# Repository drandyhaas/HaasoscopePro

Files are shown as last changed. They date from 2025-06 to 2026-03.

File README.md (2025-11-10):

## Haasoscope Pro

An affordable 2 GHz 3.2 GS/s 12 bit open-source open-hardware expandable USB oscilloscope

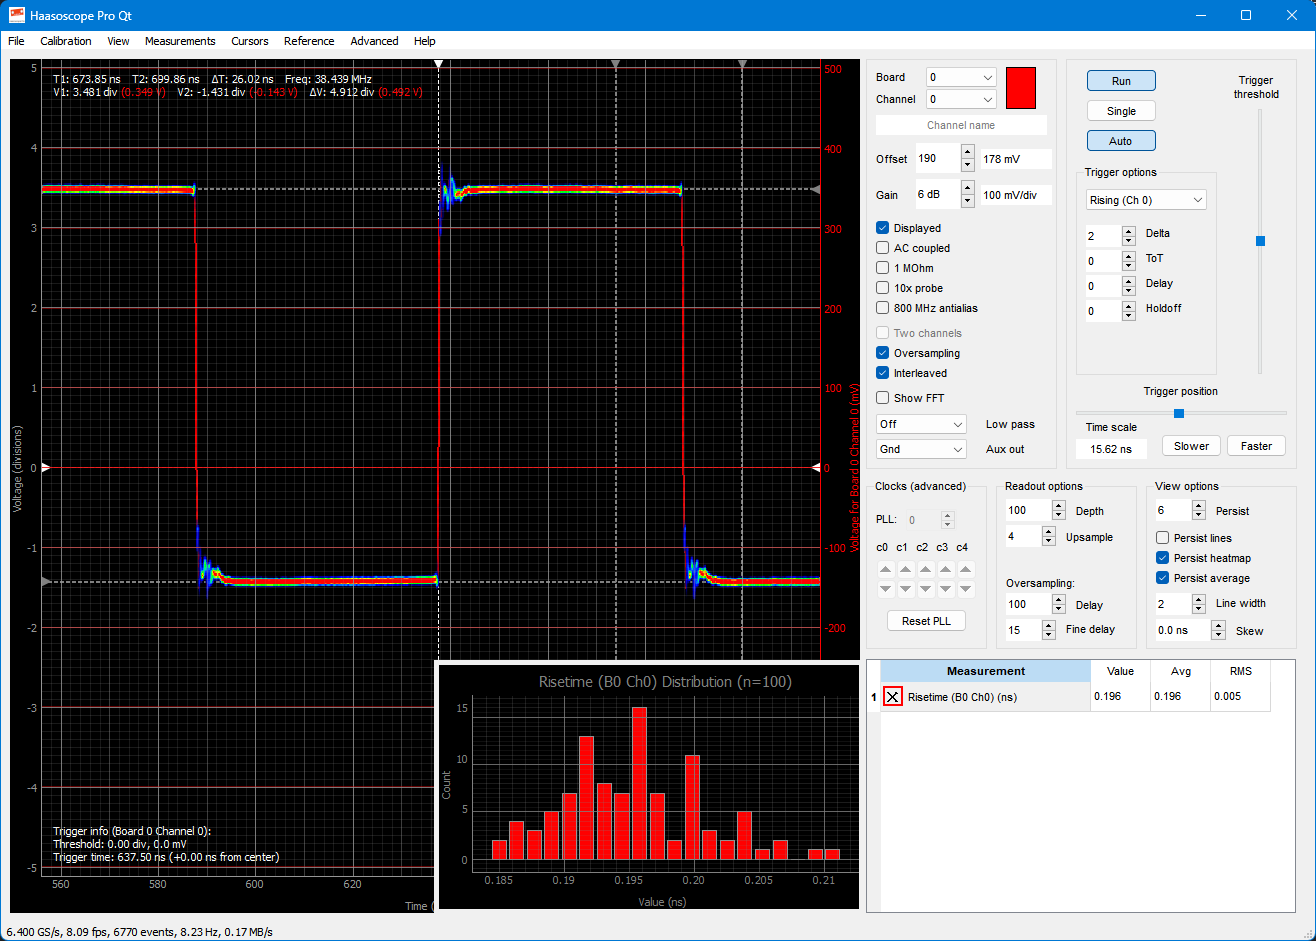
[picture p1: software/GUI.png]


## Links

Available on [CrowdSupply](https://www.crowdsupply.com/andy-haas/haasoscope-pro) and at [Mouser](https://www.mouser.com/c/?q=Haasoscope)

[Hackaday.io page](https://hackaday.io/project/200773-haasoscope-pro)

[Schematics PDF](adc%20board/haasoscope_pro_adc_fpga_board_schematics.pdf)

[Routing image](adc%20board/haasoscope_pro_adc_fpga_board_routing.png)

[Firmware overview](adc%20board%20firmware/schematic.pdf)

[Software overview](software/diagram.png)

## Video tutorials

See this [YouTube Playlist](https://www.youtube.com/playlist?list=PLB1iz3MRh5DiKQQmUUNoTf2oo_m5qS00k) !

## Software and firmware versions

- "main" branch currently has v32 firmware and software
- "v32_test" branch: new development is happening here
- old: "v29" branch has v29 firmware and adds more software features
- old: "v27" branch has v27 firmware that shipped with the first round of units

To use a different branch, do <code>git pull && git checkout "branchname"</code>.
For v30+ you can [download a release](https://github.com/drandyhaas/HaasoscopePro/releases) zip file for your platform (Windows, Mac, Linux).
Then run the new software, update the firmware (if needed) on your board from that new software, and power cycle the board (automatic firmware reload for boards with v29+ firmware).

## Quick start for Windows / Mac (M1+) / Linux (Ubuntu)

1) [Download a release](https://github.com/drandyhaas/HaasoscopePro/releases) zip file for your OS
2) Install [FTDI D2xx driver](https://ftdichip.com/drivers/d2xx-drivers/) for your OS:
- for Windows: run the setup exe at <code>ftdi_setup.exe</code>
- for Mac: <code>sudo mkdir -p /usr/local/lib; sudo cp libftd2xx.dylib /usr/local/lib/</code> 
- for Linux: <code>sudo cp libftd2xx.so /usr/lib/</code>
3) Plug Haasoscope Pro into your computer via USB (5V 2A at least!)
4) Run **HaasoscopeProQt** in the <code>(OS)_HaasoscopeProQt</code> directory

## Fuller way of running

1) Install python3 and git for your operating system
2) Get code: <code>git clone https://github.com/drandyhaas/HaasoscopePro.git</code>
3) <code>cd HaasoscopePro/software</code>
4) Install dependencies: <code>pip install -r requirements.txt</code><br>
   or manually: <code>pip install numpy scipy pyqtgraph PyQt5 pyftdi ftd2xx requests packaging</code><br>
5) Install FTDI driver (see Quick start above)
6) Plug Haasoscope Pro into your computer via USB (5V 2A at least!)
7) Run: <code>python3 HaasoscopeProQt.py</code>

## Tips

- If not enough power is being supplied, plug in via a [powered USB hub](https://a.co/d/hfAtVhl), a [USB PD hub with 15W reserved for ports](https://a.co/d/174I3v8), or use an external [5-24V 20W+ power adapter with 2.1mm plug](https://a.co/d/1EkzLRP)
- If you get security issues on Mac, do: <code>xattr -cr Mac_HaasoscopeProQt</code>
- If the board is not found on Linux, use this udev rule and then plug it in: <code>sudo cp ft245.rules /etc/udev/rules.d/</code>
- If you get an error like "qt.qpa.plugin: Could not load the Qt platform plugin "xcb" in "" even though it was found", try: <code>sudo apt install libxcb-xinerama0</code>

## Support

- Ask a question in the [discussions forum](https://github.com/drandyhaas/HaasoscopePro/discussions)
- Post bugs or requests in the [issues section](https://github.com/drandyhaas/HaasoscopePro/issues)

## Repository structure

- [adc board](adc%20board/): Design files and documentation for the main board, based on Eagle 9.6.2
- [adc board firmware](adc%20board%20firmware/): Quartus lite project and documentation for the Altera Cyclone IV FPGA firmware
- [case](case/): Front and back PCB panels for the aluminum case
- [other](other/): Other files like safety docs, jlc files, and ftdi template
- [software](software/): Python files and documentation for the oscilloscope program
- [sub boards](sub%20boards/): Eagle design files and documentation for smaller test boards that were used during development

## 2 GHz Active Probe

All designs for the accompanying Haasoscope Pro-be active probe are in a [separate repository](https://github.com/drandyhaas/oshw-active-probe)

## Other GUIs

 - [ngscopeclient](https://www.ngscopeclient.org/) is a very powerful multi-instrument analysis suite. HaasoscopeProQt must be running, which then automatically opens the LAN port and accepts connections from ngscopeclient. See the ngscopeclient user manual for details.

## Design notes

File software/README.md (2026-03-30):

# HaasoscopePro Software

Python-based oscilloscope software for the HaasoscopePro hardware.

## Quick Start

### Installation

```bash
# Install dependencies from requirements file
pip install -r requirements.txt

# Or install manually
pip install numpy scipy pyqtgraph PyQt5 ftd2xx requests packaging
```

**Note:** `requests` and `packaging` are optional but recommended for automatic update checking.

### Running with Hardware

```bash
# Run the application
python HaasoscopeProQt.py
```

The software will automatically detect connected HaasoscopePro boards via USB.

### Running with Dummy Server (No Hardware Required)

For development and testing without physical hardware:

```bash
# Terminal 1 - Start dummy server
cd dummy_scope
python dummy_server.py --port 9999

# Terminal 2 - Run application with socket connection
python HaasoscopeProQt.py --socket localhost:9999
```

**Command-Line Options:**

```bash
# Single dummy board on custom port
python HaasoscopeProQt.py --socket localhost:9999

# Multiple dummy boards (multi-board simulation)
python HaasoscopeProQt.py --socket localhost:9998 --socket localhost:9999 --socket localhost:10000

# Remote dummy server
python HaasoscopeProQt.py --socket 192.168.1.100:9999

# Mix hardware and dummy boards (if hardware is detected, socket boards are added)
python HaasoscopeProQt.py --socket localhost:9999

# Limit maximum number of devices to connect (default: 100)
python HaasoscopeProQt.py --max-devices 4

# USB3 mode for HaasoscopePro Max (uses FT60X instead of FT232H, allows 1M memory depth)
python HaasoscopeProQt.py --usb3

# Testing mode (disables dynamic status bar updates for stable screenshots)
python HaasoscopeProQt.py --socket localhost:9999 --testing

# Combine options
python HaasoscopeProQt.py --max-devices 5 --socket localhost:9999 --testing

# Show help
python HaasoscopeProQt.py --help
```

**Automatic Fallback:** If no `--socket` is specified and no hardware is detected, the application automatically tries to connect to `localhost:9998`.

See [dummy_scope/README.md](dummy_scope/README.md) for detailed dummy server documentation.

## Editing the GUI

The Haasoscope Pro GUI can be edited using [Qt Designer](https://www.pythonguis.com/installation/install-qt-designer-standalone/), on software/HaasoscopePro.ui or HaasoscopeProFFT.ui etc.

## Keyboard Shortcuts

The GUI supports keyboard shortcuts for quick control adjustments:

| Shortcut | Function |
|---|---|
| **Arrow Keys** | |
| `Left` / `Right` | Decrease / Increase time scale (downsample) |
| `Up` / `Down` | Increase / Decrease offset |
| **Shift + Arrow Keys** | |
| `Shift+Up` / `Shift+Down` | Increase / Decrease gain |
| **Ctrl + Arrow Keys** | |
| `Ctrl+Up` / `Ctrl+Down` | Increase / Decrease trigger threshold |
| `Ctrl+Left` / `Ctrl+Right` | Decrease / Increase trigger position |
| **Alt + Arrow Keys** | |
| `Alt+Up` / `Alt+Down` | Increase / Decrease trigger delta |
| **Other Keys** | |
| `Space` | Toggle run/pause |
| `R` | Set rising edge trigger on current channel |
| `F` | Set falling edge trigger on current channel |
| `T` | Toggle two-channel mode for current board |
| `C` | Toggle between channel 0 and 1 (two-channel mode) |
| `0` - `9` | Select board 0-9 |
| `` ` `` (backtick) | Select board 0 (alias for `0`) |

**Tips:**
- Arrow keys provide quick navigation without reaching for the mouse
- Modifier keys (Shift/Ctrl/Alt) access additional functions on the same arrow keys
- All shortcuts work when the main window has focus

## Multi-Board Features

The Haasoscope Pro supports daisy-chaining multiple boards via LVDS for synchronized operation.

### Automatic LVDS Delay Calibration

When multiple boards are connected, the system automatically calibrates and compensates for trigger signal propagation delays:

- **Initial Setup**: After PLL reset during startup, LVDS calibration runs automatically for the initial trigger board
- **Switching Trigger Sources**: When you set a different board to channel-based trigger (using `R` or `F` keys, or via UI), calibration runs automatically if no saved calibration exists
- **Saved Calibrations**: Each trigger source board has its own calibration set that is automatically restored when switching back

**To use:**
1. Start the application (PLL reset and LVDS calibration happen automatically)
2. Switch trigger sources as needed using keyboard shortcuts or UI - calibration is fully automatic!

**Manual calibration** is also available via **Calibration → Board LVDS delays** menu.

For detailed technical information, see [EXTTRIG_ECHO_CALIBRATION.md](EXTTRIG_ECHO_CALIBRATION.md).

### Trigger Source Management

- Only one board can be self-triggering at a time (enforced automatically)
- When setting a board to channel-based trigger, all other boards are automatically set to external trigger mode
- Keyboard shortcuts make it easy to switch trigger boards:
  - `0`-`9`: Select board
  - `R`: Set rising edge trigger on current board
  - `F`: Set falling edge trigger on current board

### Board Synchronization

- **Board Stabilizer**: Corrects for trigger jitter on the self-triggering board
- **Extra Trigger Stabilizer**: Fine-grained per-frame stabilization applied across all boards
- **LVDS Compensation**: Firmware (coarse) + software (fine) dual-layer delay compensation for sample-level precision

## Code Architecture

This diagram shows the software architecture with all major components, data flows, and relationships.
Use [mermaid.live](https://mermaid.live/) to convert it to [diagram.png](https://raw.githubusercontent.com/drandyhaas/HaasoscopePro/refs/heads/main/software/diagram.png).

```mermaid
graph TD
    %% --- Styling Definitions ---
    classDef core fill:#d9ead3,stroke:#38761d,stroke-width:2px,font-size:12px;
    classDef startup fill:#cfe2f3,stroke:#3d85c6,stroke-width:2px,font-size:12px;
    classDef hardware fill:#fce5cd,stroke:#e69138,stroke-width:2px,font-size:12px;
    classDef helpers fill:#fff2cc,stroke:#f1c232,stroke-width:2px,font-size:12px;
    classDef datastore fill:#e2d0f3,stroke:#674ea7,stroke-width:2px,font-size:12px;
    classDef user fill:#f4cccc,stroke:#cc0000,stroke-width:2px,font-size:12px;
    classDef device fill:#d0e0e3,stroke:#45818e,stroke-width:2px,font-size:14px;
    classDef testing fill:#c9daf8,stroke:#1c4587,stroke-width:2px,font-size:12px,stroke-dasharray:5;

    %% --- Entry Point ---
    User(["👤 User Input<br>Clicks, Menus, Keys"]) -.-> A
    A["🚀 HaasoscopeProQt.py<br><i>Entry Point</i>"] --> B

    %% --- Main Controller ---
    B["🎛️ MainWindow<br>main_window.py<br><i>Central Controller</i>"]

    %% --- Central State ---
    C[("💾 ScopeState<br>scope_state.py<br>Settings & Config")]

    B <--> C

    %% --- Core Processing Components ---
    B --> D["🔌 HardwareController<br>hardware_controller.py<br>USB/Socket Communication"]
    B --> E["⚙️ DataProcessor<br>data_processor.py<br>Signal Processing"]
    B --> F["📊 PlotManager<br>plot_manager.py<br>Visualization"]

    D <--> C
    E <--> C
    F <--> C

    %% --- Owned Managers ---
    B --> M1["📏 MeasurementsManager<br>measurements_manager.py<br>Statistics & Analysis"]
    B --> M2["📌 ReferenceManager<br>reference_manager.py<br>Waveform Storage"]
    B --> M3["💾 SettingsManager<br>settings_manager.py<br>Save/Load .hsp"]

    M1 --> C
    M2 --> C
    M3 --> C

    %% --- Plot Manager Owned Components ---
    F --> P1["🎯 CursorManager<br>cursor_manager.py<br>H/V Cursors"]
    F --> P2["🔥 HeatmapManager<br>heatmap_manager.py<br>Persistence Heatmap"]

    P1 --> C
    P2 --> C

    %% --- Popup Windows ---
    B -.-> W1["📈 FFTWindow<br>FFTWindow.py<br>Frequency Analysis"]
    B -.-> W2["🧮 MathChannelsWindow<br>math_channels_window.py<br>Channel Math"]
    B -.-> W3["📊 HistogramWindow<br>histogram_window.py<br>Distribution View"]
    B -.-> W4["🕐 HistoryWindow<br>history_window.py<br>Waveform History"]
    B -.-> W5["📉 XYWindow<br>xy_window.py<br>XY Plot Mode"]
    B -.-> W6["🔍 ZoomWindow<br>zoom_window.py<br>Zoomed View"]

    W1 --> C
    W2 --> C
    W5 --> C
    W6 --> C

    %% --- Data Flow ---
    D -- "Raw ADC Data" --> E
    E -- "Processed xydata" --> F
    E -- "Measurements" --> M1
    E -- "FFT Data" --> W1

    %% --- Hardware Layer ---
    D --> H1["🔧 Low-Level Libs<br>usbs.py, board.py<br>USB_FT232H.py"]
    H1 --> H2["🔌 Hardware Interface<br>SPI: spi.py, adf435x_core.py<br>Calibration: calibration.py"]

    H1 --> DEV1["🖥️ Physical Scope<br>via USB/FTDI"]
    H1 --> DEV2["🔬 Dummy Server<br>dummy_scope/<br>TCP Socket"]

    %% --- Additional Services ---
    B -.-> S1["🌐 SCPIsocket.py<br>Remote Control"]
    B -.-> S2["💾 DataRecorder<br>data_recorder.py<br>CSV Export"]

    %% --- Style Applications ---
    class A startup
    class B core
    class C datastore
    class D,E,F core
    class M1,M2,M3,P1,P2 core
    class W1,W2,W3,W4,W5,W6 helpers
    class H1,H2 hardware
    class DEV1 device
    class DEV2 testing
    class S1,S2 helpers
    class User user
```

## Key Modules

### Core Components

**`main_window.py`** - Main application controller
- Handles all UI events (clicks, menus, keyboard shortcuts)
- Orchestrates data flow between hardware, processing, and display
- Manages all component lifecycles
- Implements per-channel/per-board setting synchronization

**`scope_state.py`** - Central state storage
- Single source of truth for all oscilloscope settings
- Per-channel settings: gain, offset, AC/DC, impedance, resamp, peak detect, persistence
- Per-board settings: trigger settings, channel modes, pulse stabilizer
- Global settings: timebase, downsample, display options

**`hardware_controller.py`** - Hardware abstraction layer
- Manages communication with oscilloscope boards
- Sends low-level commands (SPI, trigger, gain/offset)
- Retrieves waveform data packets
- Supports both USB (FTDI) and socket (dummy server) connections

**`data_processor.py`** - Signal processing
- Processes raw ADC data into calibrated waveforms
- Calculates FFT spectra
- Computes measurements (Vpp, RMS, frequency, duty cycle, rise time, trigger-crossing frequency/period)
- Applies calibration corrections

**`plot_manager.py`** - Display and visualization
- Renders waveforms using PyQtGraph
- Applies FIR frequency response correction
- Applies Savitzky-Golay polynomial filtering
- Manages per-channel peak lines, persistence, references
- Handles XY plot mode
- Cursor and measurement overlays
- Real-time plot updates

**`frequency_calibration.py`** - FIR calibration system
- Automatic frequency response correction using square wave calibration
- Support for all modes: normal (3.2 GHz), two-channel (1.6 GHz), oversampling, and interleaved (6.4 GHz)
- Measures duty cycle, frequency, and DC offset from input signal
- Adaptive tap count (32/64/128) based on sample rate
- Save/load calibration files (.fir format)
- See [FIR_CALIBRATION_README.md](FIR_CALIBRATION_README.md) for details

### Supporting Components

**`FFTWindow.py`** - FFT spectrum analyzer window
- Real-time frequency domain display
- Per-channel FFT enable/disable
- Peak detection and analysis

**`math_channels_window.py`** - Math channel operations
- Channel arithmetic (add, subtract, multiply, divide)
- Mathematical functions (differentiate, integrate, smooth, envelope, abs, square, sqrt, log, exp)
- Digital filters (low-pass, high-pass, band-pass, band-stop) with Butterworth and Chebyshev designs
- Time shift with sub-sample interpolation (0.001 Hz to 10 GHz range)
- AC coupling and min/max tracking
- Custom expression evaluation

**Implementation Note**: Math channels are calculated from non-resampled source data (before `doresamp` is applied) to ensure correct FFT frequency ranges and optimal filter performance. Results are then resampled for display to match the source channel's resampling setting. This ensures that:
- FFT analysis shows the true Nyquist frequency of the source data
- Digital filters operate at the actual hardware sample rate
- Min/Max tracking automatically handles array size changes when `doresamp` is modified

**`xy_window.py`** - XY Plot window
- Displays Lissajous figures and parametric plots
- Plots one channel against another (X vs Y)
- Supports both physical and math channels
- Channel selection via dropdown menus
- Useful for I-V curves, phase relationships, and parametric analysis
- Accessed via View menu → XY Plot

**`zoom_window.py`** - Zoom window
- Synchronized zoomed view of the main plot
- Shows all active channels, math channels, and references
- Displays trigger lines, cursors, peak detect, and persistence
- Region of Interest (ROI) selection on main plot
- Secondary Y-axis for voltage display
- Non-interactive view (pan/zoom controlled by ROI on main plot)
- Cross-window mouse pointer (20-pixel crosshair visible only within ROI)
- Accessed via View menu → Zoom Window

**`histogram_window.py`** - Histogram display
- Statistical distribution visualization
- Waveform amplitude analysis
- Histogram binning and counting

**`history_window.py`** - Waveform history viewer
- Stores previous waveform captures
- Allows review of historical data
- Sequential playback of captured waveforms

**`measurements_manager.py`** - Measurements display
- Automated measurement calculations
- Statistics table display
- Rise time and edge analysis

**`reference_manager.py`** - Reference waveform management
- Store and recall waveforms
- Per-channel reference display
- Waveform comparison

**`cursor_manager.py`** - Cursor controls
- Horizontal/vertical cursors
- Delta measurements
- Snap to waveform
- Rise time fit visualization

**`heatmap_manager.py`** - Persistence heatmap visualization
- Density-based visualization of persist lines
- Adaptive resolution based on zoom level (1000x200 bins)
- Gaussian smoothing for professional appearance
- Color-coded density (blue-to-red gradient)
- Automatic regeneration on pan/zoom/gain changes

**`settings_manager.py`** - Settings persistence
- Save/load configuration files (.hsp)
- Backward compatibility handling
- Per-channel/board settings migration

**`data_recorder.py`** - Data logging
- CSV export
- Event capture
- Waveform recording

### Hardware Communication

**`usbs.py`** - USB device management
- FTDI device discovery and initialization
- Socket device connections (for dummy server)
- Multi-board detection and ordering

**`board.py`** - Low-level board commands
- SPI communication
- PLL configuration
- Fan control, temperature reading
- Clock distribution for multi-board setups

**`USB_FT232H.py`** - FTDI wrapper
- Synchronous FIFO mode (FT232H)
- High-speed USB data transfer

**`dummy_scope/`** - Testing framework
- TCP socket-based oscilloscope simulator
- Configurable waveform generation (sine, square, pulse)
- Full protocol implementation
- Multi-board simulation support

**`test/test_scpi_client.py`** - SCPI socket test client
- Connects to the SCPI server and queries identity, rates, and depths
- Retrieves and parses binary waveform data
- Usage: `python test/test_scpi_client.py [host] [port]`

### Utility Modules

**`calibration.py`** - Calibration data management

**`SCPIsocket.py`** - SCPI remote control interface
- TCP server on port 32001 for remote oscilloscope control
- Supports standard SCPI queries (`*IDN?`, `RATES?`, `DEPTHS?`) and acquisition commands (`START`, `STOP`, `SINGLE`, `FORCE`)
- Binary waveform data retrieval via `K` command
- See `test/test_scpi_client.py` for an example client

**`spi.py`** - SPI communication helpers

**`utils.py`** - Common utility functions

## Data Flow

1. **Acquisition**: `hardware_controller.get_event()` retrieves raw ADC data from board
2. **Processing**: `data_processor.process_board_data()` converts to calibrated waveforms
3. **Display**: `plot_manager.update_plots()` renders waveforms on screen
4. **Analysis**: `data_processor.calculate_measurements()` computes measurements
5. **FFT**: Optional FFT analysis in `FFTWindow`

## Configuration Files

Settings are saved in `.hsp` files (JSON format):
- Window geometry and UI state
- Per-channel settings (gain, offset, colors, persistence, resamp)
- Per-board settings (trigger, modes, pulse stabilizer)
- Display preferences (grid, cursors, markers)
- Math channel definitions
- Reference waveforms
- FIR and polynomial filtering enable states

FIR calibration data is saved separately in `.fir` files (JSON format):
- FIR coefficients for all modes (normal, two-channel, oversampling, interleaved)
- Sample rates and frequency response data
- Calibration metadata (timestamp, parameters)

**Backward Compatibility**: The settings manager automatically converts old single-value settings (resamp, peak detect, pulse stabilizer) to per-channel/board arrays when loading legacy files.

## Development

### Building Standalone Executables

```bash
# Windows
windowspyinstaller.bat

# macOS
./macpyinstaller.sh

# Linux
./linuxpyinstaller.sh
```

Executables are created in `dist/` directory.

### Adding New Per-Channel Settings

1. Add array to `scope_state.py`:
   ```python
   self.my_setting = [default_value] * (num_boards * num_chan_per_board)
   ```

2. Update GUI in `main_window.py` `select_channel()`:
   ```python
   self.ui.mySettingBox.setValue(s.my_setting[s.activexychannel])
   ```

3. Add change handler:
   ```python
   def my_setting_changed(self, value):
       self.state.my_setting[self.state.activexychannel] = value
   ```

4. Update `settings_manager.py` for save/load with backward compatibility

### Adding New Per-Board Settings

Same pattern as per-channel, but use `s.activeboard` instead of `s.activexychannel`.

### Code Style

- Follow existing naming conventions (snake_case for functions, CamelCase for classes)
- Document complex algorithms with inline comments
- Use type hints where helpful
- Keep UI logic in `main_window.py`, processing in separate modules

## Troubleshooting

**ImportError: No module named 'PyQt5'**
```bash
pip3 install PyQt5 pyqtgraph
```

**FTDI device not found**
- Install FTDI D2XX drivers (see main README)
- Check USB connection (5V 2A minimum)
- Verify device appears in system device manager

**Slow performance**
- Reduce persistence time
- Disable peak detect when not needed
- Close FFT window when not in use

## Dependencies

All dependencies are listed in `requirements.txt` and can be installed with:

```bash
pip install -r requirements.txt
```

### Core Dependencies
- **Python 3.7+** (3.8+ recommended)
- **PyQt5** - GUI framework
- **pyqtgraph** - Fast plotting library
- **numpy** - Numerical computing
- **scipy** - Signal processing (FFT, filtering, interpolation)
- **ftd2xx** - FTDI driver wrapper for hardware communication

### Optional Dependencies
- **requests** - For automatic update checking (gracefully degrades if not installed)
- **packaging** - For version comparison in update checker

## License

Same as parent HaasoscopePro project.

## See Also

- [Main Project README](../README.md)
- [Dummy Server Documentation](dummy_scope/README.md)
- [Firmware Documentation](../adc%20board%20firmware/README.md)
- [Hardware Schematics](../adc%20board/haasoscope_pro_adc_fpga_board_schematics.pdf)
- [HaasoscopePro on Hackaday.io](https://hackaday.io/project/200773-haasoscope-pro)

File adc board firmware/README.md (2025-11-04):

# Firmware Architecture

This section documents how the Haasoscope Pro ADC board firmware works.

## Overview

The firmware runs on an **Intel/Altera Cyclone IV E FPGA** (EP4CE30F23C6) and implements a real-time data acquisition system with the following key features:
- **LVDS high-speed serial interface** (800 Mbps) for ADC data
- **USB 2.0 control and data transfer** via FT232H chip
- **Advanced triggering system** with sub-sample precision
- **Multi-board synchronization** via LVDS trigger chain
- **Flexible downsampling** and averaging (1× to 40×)

**Current Firmware Version:** 31

## System Block Diagram

```
ADC Chips (4 channels × 14-bit LVDS @ 800 Mbps)
    ↓
LVDS Receivers & Deserializers (10:1 deserialization)
    ↓
Downsampler (40 samples/clock, channel formatting, decimation)
    ↓
Triggerer (threshold detection, state machine, RAM write control)
    ↓
RAM Buffer (1024 × 560-bit dual-port circular buffer)
    ↓
Command Processor (USB interface, waveform readout)
    ↓
FTDI 245-FIFO Controller (AXI-stream to USB)
    ↓
FT232H USB 2.0 Chip → PC Software
```

## Main Components

### 1. LVDS Receivers (lvds1.v, lvds2.v, etc.)
- **Purpose:** Convert LVDS analog signals from ADC chips to digital data
- **Configuration:** 4 independent receivers, 14-bit parallel output per receiver
- **Data Rate:** 800 Mbps input → 140-bit parallel output (10:1 deserialization)
- **Technology:** Altera ALTLVDS_RX with DPA (Dynamic Phase Alignment) for clock recovery
- **Clock Domain:** LVDS sample clock (100 MHz)

### 2. Downsampler (downsampler.v)
- **Purpose:** Organize deserialized data into samples, apply channel formatting, and perform decimation
- **Input:** 4 × 140-bit LVDS data (560 bits total)
- **Processing:**
  - Extracts 40 individual 12-bit ADC samples per clock cycle
  - Applies channel configuration (single/dual/oversampling modes)
  - Performs programmable downsampling (1×, 2×, 4×, 8×, 20×, 40×)
  - Optional high-resolution averaging (sums multiple samples for 12-20 bit precision)
- **Output:** 560-bit wide data containing 40 samples × 14 bits (12-bit data + 2-bit metadata)
- **Clock:** 100 MHz LVDS clock

### 3. Triggerer (triggerer.v)
- **Purpose:** Implements the trigger detection system and controls RAM write operations
- **Key States:**
  - State 0: Ready (waiting for trigger)
  - States 1-2: Threshold comparison (rising/falling edge)
  - States 5-7: External/auto triggers
  - State 200: Pre-acquisition (collecting pre-trigger samples)
  - State 250: Post-trigger acquisition
  - State 251: Data ready for readout
- **Trigger Types:**
  - Type 1: Threshold rising edge
  - Type 2: Threshold falling edge
  - Type 3: External LVDS trigger (from another board)
  - Type 4: Auto trigger (periodic forced capture)
  - Type 5: External SMA trigger (back panel input)
  - Type 30: LVDS trigger with echo-back (for time measurement)
- **Features:**
  - Programmable upper/lower thresholds (12-bit signed)
  - Time-of-Threshold (ToT) gating to prevent false triggers
  - Pre/post trigger capture (configurable sample counts)
  - Rolling trigger mode (~10 Hz when armed but not triggered)
  - Trigger phase detection (records which of 40 samples triggered)
  - Multi-board synchronization via LVDS trigger I/O
- **Clock:** 100 MHz LVDS clock

### 4. RAM Buffer (rambuffer.v)
- **Purpose:** Store captured ADC waveforms during acquisition
- **Capacity:** 1024 locations × 560 bits = 655 kB
- **Write Port:** LVDS clock domain (100 MHz), controlled by triggerer
- **Read Port:** Main clock domain (50 MHz), controlled by command processor
- **Technology:** Altera altsyncram (dual-port synchronous RAM)
- **Organization:** Circular buffer, each location holds 40 samples

### 5. Command Processor (command_processor.v)
- **Purpose:** Main control module - receives USB commands, configures system, reads out data
- **Clock:** 50 MHz main clock
- **Interfaces:**
  - USB AXI-stream input: 8-bit command reception
  - USB AXI-stream output: 32-bit data transmission
  - SPI master control for ADC configuration
  - PLL phase adjustment control
  - Flash memory interface for firmware updates
  - RGB LED and fan PWM control

**Key Commands (8-byte USB messages):**

| Cmd | Function | Description |
|-----|---|---|
| 0 | Read waveform data | Reads RAM from triggered point, transmits via USB |
| 1 | Arm trigger | Sets trigger type, channel type, and capture length |
| 2 | Read status/registers | Returns version, board status, lock info, etc. |
| 3 | SPI transaction | Configures ADC chips via SPI |
| 4 | Set SPI mode | Selects SPI timing mode (0-3) |
| 5 | Reset PLLs | Resets clock generation PLLs |
| 6 | Adjust PLL phase | Fine-tunes clock phase for alignment |
| 7 | Switch clock source | Selects crystal oscillator or external clock |
| 8 | Set trigger thresholds | Programs trigger levels and options |
| 9 | Downsampling settings | Controls decimation rate and averaging |
| 10 | Control board outputs | Sets relay outputs, probe comp, etc. |
| 11 | RGB LED colors | Sets neo-pixel LED colors |
| 14 | Read register | Reads internal register value |
| 15 | Read flash | Reads byte from on-board flash memory |
| 16 | Write flash | Writes byte to flash (requires auth) |
| 17 | Erase flash | Bulk erases flash (requires auth) |

### 6. FTDI 245-FIFO Controller (ftdi245fifo/)
- **Purpose:** Interfaces with FT232H USB chip using 245-FIFO mode
- **Input:** 32-bit AXI-stream from command processor
- **Output:** 8-bit parallel data to FT232H chip
- **Features:** Handles USB flow control, data packing/unpacking, FIFOs for clock domain crossing
- **Third-party IP:** Based on open-source ftdi_245fifo_top module

### 7. Supporting Modules
- **SPI_Master.v:** Bit-banging SPI controller with configurable modes (0-3) and clock speed
- **phase_detector.v:** Measures time difference between signal edges using fast clock (for multi-board sync)
- **pwm_generator.v:** 8-bit PWM generator for fan speed control
- **neo_driver.v:** WS2812B protocol driver for RGB LED control
- **pll1-4.v:** Programmable clock generation and phase adjustment (Altera IP)

## Data Flow

### ADC Input → USB Output Pipeline

1. **ADC LVDS Input:** 4 ADC chips output 14-bit differential data at 800 Mbps
2. **LVDS Deserializer:** Converts serial LVDS to 140-bit parallel (10:1) at 100 MHz
3. **Downsampler:** Organizes 560 bits into 40 × 12-bit samples, applies decimation
4. **Triggerer:** Monitors samples for trigger conditions, controls RAM writes
5. **RAM Buffer:** Stores 1024 sets of 40 samples (circular buffer)
6. **Command Processor:** Receives USB commands, reads RAM from trigger point, reorders data
7. **FTDI Controller:** Converts 32-bit words to 8-bit USB, handles flow control
8. **USB to PC:** FT232H chip transmits data at USB 2.0 speeds (up to ~60-120 Mbps sustained)

### Data Width Conversions
- LVDS: 14 bits × 4 ADCs = 56 bits per LVDS bit time
- Deserialized: 56 bits × 10 = 560 bits per 100 MHz clock
- Samples: 40 × 12-bit = 480 bits of ADC data (+ 80 bits control/metadata)
- RAM: 560 bits × 1024 locations = 655 kB total
- USB: 32-bit words transmitted sequentially

## Clock Architecture

### Primary Clock Domains

1. **LVDS Clock (100 MHz)**
   - Derived from ADC sample clock via DPA
   - Feeds: Downsampler, Triggerer, RAM write port
   - Critical for timing accuracy

2. **Main Clock (50 MHz)**
   - Source: On-board crystal oscillator (switchable to external)
   - Feeds: Command processor, USB controller, control logic
   - Generated by PLL1 with multiple phase-adjustable outputs

3. **Flash/LED Clock (12.5 MHz)**
   - Divided from 50 MHz (÷4)
   - Feeds: Flash memory interface, RGB LED driver, PWM fan control

### Clock Domain Crossing (CDC)
- LVDS domain → 50 MHz domain: 2-3 stage synchronizer pipeline
- Synchronized signals: trigger state, RAM address, event counters, timestamps

## Triggering System

### Threshold Trigger Operation

The threshold trigger uses a **two-step detection** algorithm to prevent false triggers:

1. **Step 1:** Detect signal crossing threshold *outward*
   - Rising edge: sample < lower_threshold
   - Falling edge: sample > upper_threshold

2. **Step 2:** Detect signal crossing threshold *inward*
   - Rising edge: sample > upper_threshold
   - Falling edge: sample < lower_threshold
   - Also enforces Time-of-Threshold (ToT) holdoff

This hysteresis prevents noise from causing false triggers.

### Runt Pulse Trigger

The firmware implements a **runt pulse rejection** feature that prevents triggering on pulses that exceed a second, higher threshold. This is useful for rejecting overshoot or selecting signals of a specific amplitude range.

**Operation:**
- When `triggerdelta + triggerdelta2 < 128`, runt rejection is active
- The trigger system uses two thresholds:
  - **threshold1** = triggerlevel + triggerdelta (first threshold)
  - **threshold2** = triggerlevel + triggerdelta + triggerdelta2 (runt threshold)
- During State 2 (Step 2 of threshold detection), the system checks all 40 samples
- If any sample exceeds threshold2, the trigger is rejected and returns to State 1
- This ensures the trigger only fires when the signal crosses threshold1 but does NOT exceed threshold2

**Threshold Encoding:**
- Both thresholds are packed into 24-bit registers:
  - `lowerthresh[11:0]` = threshold1, `lowerthresh[23:12]` = threshold2
  - `upperthresh[11:0]` = threshold1, `upperthresh[23:12]` = threshold2
- When `triggerdelta + triggerdelta2 >= 128`, runt rejection is disabled
  - The software sends triggerdelta2 = 128 to the firmware
  - The firmware sets threshold2 to min/max values (-2048/+2047) to never trigger rejection

**Use Cases:**
- Reject pulses with overshoot or ringing
- Select pulses of specific amplitude ranges
- Discriminate between different signal types by amplitude

### Trigger Configuration
- **Thresholds:** Set via command 8, 12-bit signed values
- **triggerdelta:** Hysteresis threshold offset (upper/lower from triggerlevel)
- **triggerdelta2:** Runt rejection threshold offset (adds to triggerdelta)
- **Pre-trigger:** `prelengthtotake` samples captured before trigger
- **Post-trigger:** `lengthtotake` total samples after trigger fires
- **ToT:** Minimum time signal must remain outside thresholds
- **Holdoff:** Quiet time required between triggers

### Trigger Phase Detection
- Records which of 40 samples caused the trigger
- Provides sub-microsecond precision (~2.5 ns resolution)
- Enables precise trigger jitter elimination in post-processing

### Multi-Board Synchronization
- LVDS trigger outputs: `lvdsout_trig` (forward) and `lvdsout_trig_b` (backward echo)
- Supports daisy-chain topology with configurable "first"/"last" board designation
- Enables synchronized multi-channel capture across multiple Haasoscope Pro units
- Phase detector measures propagation delay for time correlation

## Advanced Features

### Pre-Trigger Capture
The firmware can capture samples *before* the trigger condition occurs by continuously writing to a circular RAM buffer. When a trigger fires, it records the current RAM address and the PC can read backwards to retrieve pre-trigger history.

### Rolling Trigger Mode
When armed but no trigger condition is met, the system automatically triggers periodically (~10 Hz) to allow observation of slow or repetitive signals without explicit triggering.

### Overrange Detection
Monitors 4 ADC overrange flags and counts saturation events, helping identify when signals exceed ADC input range.

### Event Time Stamping
A 32-bit counter increments at the LVDS clock rate and captures the timestamp when each trigger fires, enabling precise event correlation.

### Flash Firmware Updates
The firmware supports reading/writing the on-board flash memory, allowing firmware updates without a JTAG programmer (requires authentication to prevent accidental corruption).

### Fan Control & LED Indicators
- PWM-controlled cooling fan with software-adjustable duty cycle
- 2 RGB neo-pixel LEDs for status indication
- 10 board LEDs for debug output

## Key Files

| File | Purpose |
|---|---|
| `command_processor.v` | Main control processor, USB interface, waveform readout |
| `triggerer.v` | Trigger state machine, RAM write control |
| `downsampler.v` | Sample organization, channel formatting, decimation |
| `rambuffer.v` | Dual-port RAM buffer wrapper |
| `SPI_Master.v` | SPI interface for ADC configuration |
| `phase_detector.v` | Multi-board trigger timing measurement |
| `pwm_generator.v` | Fan speed PWM control |
| `neo_driver.v` | RGB LED WS2812B protocol driver |
| `lvds1-4.v` | LVDS receiver and deserializer IP |
| `pll1-4.v` | Clock generation and phase adjustment IP |
| `ftdi245fifo/` | USB FTDI 245-FIFO interface modules |
| `coincidence.bdf` | Top-level block diagram schematic |
| `coincidence.qsf` | Quartus project settings file |

## Design Philosophy

The firmware architecture separates high-speed ADC data acquisition (100 MHz LVDS domain) from lower-speed control/USB operations (50 MHz domain) to maximize performance while maintaining flexibility. The circular RAM buffer and trigger system enable capture of fast transient events with pre-trigger history, while the USB interface allows full remote control and data retrieval. Multi-board synchronization via LVDS enables scaling to many channels while maintaining precise timing correlation.

# For compiling firmware

Install Quartus Prime Lite (free)
 - Tested on Windows, but Linux should work too
 - Tested with version 23.1, but newer should also be OK

Open the **adc_board_firmware/coincidence.qpf** project file in this directory with Quartus Prime Lite
 - File... Open Project

If you've made changes to the code, recompile
 - Processing... Start Compilation (or the "play" button in the menu bar)

# To upload firmware using USB blaster

 - Attach power to board
 - Attach USB Blaster to board via JTAG (to set up the usb blaster see tips below)
 - Tools... Programmer
   - Hardware Setup... select USB blaster by double clicking, then close
   - (If you need permanent writing to the board flash, and have recompiled, remake the jic file by doing File... Convert Programming Files, then Open Conversion Setup Data..., select **adc_board_firmware/coincidence.cof**, then Generate button at bottom)
   - Add File... **adc_board_firmware/output_files/coincidence.sof** (for temporary testing) or **adc_board_firmware/output_files/coincidence.jic** (for permanent writing to the board flash memory)
   - Select checkbox Program/Configure
   - Start

### To setup USB Blaster on Windows:
 - After plugging in the USB Blaster, it may appear as an unrecognized device in the device manager. If so, you need to install a driver for it. Drivers come with the Quartus installation (even the "programmer only" version). Follow these instructions to install the driver:<br>
Plug in the USB blaster device, go to it in the device manager, and do Update driver, then Browse my computer for drivers, Let me pick from a list of devices, select JTAG cables, Have disk, and select the intelFPGA_lite\<version>\quartus\drivers\usb-blaster-ii directory, and install.

### To setup USB Blaster on Linux:
 - In theory it should work out of the box, but you just need permissions to access it. Try this and then plug it in: <code>sudo cp blaster.rules /etc/udev/rules.d/</code>

### Tips in case of problems:
 - Maybe the USB-blaster must first be powered from the board and then connected to the PC. So the procedure step by step: connect the USB-Blaster to your board, power-on the board, plug the USB cable in the PC.

### Screenshots for temporary (sof) or permanent flash (jic) programming:





# To upload firmware using Raspberry Pi

### Set up things

 - Power up the raspberry pi and log into it
 - Install openFPGALoader: https://github.com/trabucayre/openFPGALoader
 - For now you may still need the head version of the code and to compile it yourself - there is a [small change I committed](https://github.com/trabucayre/openFPGALoader/pull/584) which is only in release v1.0.0 onwards

### Connect things

 - The command to upload over JTAG will include "--pins 26:13:6:19" corresponding to the GPIOs to use for TDI:TDO:TCK:TMS
 - Given where those are on the JTAG connector on the Haasoscope Pro (which is standard for JTAG), we need raspberry pi pins 31 33 35 37 39 (corresponding to GPIO 26 13 6 19 and GND) going to JTAG pins 1 3 5 9 and 10, respectively, on the Haasoscope Pro

Pi Jtag

### Upload
 
 - cd HaasoscopePro/adc\ board\ firmware
 - For temporary (SRAM) upload: <code>openFPGALoader -c libgpiod --pins 26:13:6:19 output_files/coincidence.rbf</code>
 - For permanent (flash) upload, first copy a [special bridge firmware](https://github.com/drandyhaas/spioverjtag) (used for writing to flash) to a place where openFPGALoader can find it:
   <br><code>sudo cp spiOverJtag_EP4CE30.rbf /usr/local/share/openFPGALoader/</code>
   <br>Then you can do the flash writing: <br><code>openFPGALoader -c libgpiod --pins 26:13:6:19 --fpga-part EP4CE30 -f output_files/coincidence.rbf</code>

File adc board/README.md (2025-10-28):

# Haasoscope Pro ADC/FPGA Board

This is the main ADC and FPGA board for the Haasoscope Pro - a 2 GHz 3.2 GS/s 12-bit open-source USB oscilloscope.

Board Layout

## Overview

The Haasoscope Pro ADC board is a high-performance data acquisition board featuring dual-channel analog-to-digital conversion with FPGA processing and USB connectivity. The board integrates the complete signal chain from analog inputs through digitization, processing, and USB transfer.

## Key Specifications

- **Bandwidth**: 2 GHz
- **Sample Rate**: Up to 3.2 GS/s (interleaved) or 1.6 GS/s per channel
- **Resolution**: 12-bit
- **Channels**: 2 analog input channels
- **Interface**: USB 2.0 (FT232HQ)
- **FPGA**: Intel/Altera Cyclone IV EP4CE30F23C6N
- **Power**: 5-24V DC input with multiple onboard regulators

## Major Components

### Data Acquisition
- **ADC12DL2500ACF** (U2): Texas Instruments 12-bit dual 2.5GSPS or single 5GSPS ADC with LVDS interface
  - Datasheet: [adc12dl2500.pdf](adc12dl2500.pdf)

### Signal Conditioning (per channel)
- **OPA859IDSGR** (FL1-FL4): High-speed operational amplifiers for input buffering
- **LMH5401IRMST** (IC13, IC21): 6.2 GHz differential amplifiers
- **LMH6401IRMZR** (IC14, IC29): Programmable gain amplifiers (PGA) with 4.5 GHz bandwidth

### Processing & Control
- **EP4CE30F23C6N** (IC5): Cyclone IV FPGA (484-pin FBGA)
  - 28,848 logic elements
  - 1,803 embedded memory blocks
  - Configuration flash: EPCQ16ASI8N (IC6)
  - Custom firmware in [../adc board firmware](../adc%20board%20firmware/)

### Clock Generation
- **ADF4350BCPZ** (U2): 4.4 GHz PLL/frequency synthesizer for ADC clock generation
- **Y2**: 50 MHz reference oscillator
- **Y3**: 12 MHz crystal for USB interface

### USB Interface
- **FT232HQ** (IC8): FTDI USB 2.0 high-speed interface chip
  - Configuration EEPROM: 93LC56B (IC9)

### Auxiliary Features
- **DAC8562SDGSR** (IC17): Dual-channel 16-bit DAC for offset/gain control
- **ADC122S021CIMM** (IC3): 12-bit ADC for temperature and voltage monitoring
- **G6K-2F-RF** (K1-K5): Omron RF relays for input switching
- **TLP3475** (K6-K7): PhotoMOS solid-state relays
- **WS2812-2020** (U1, U3): RGB LED indicators

### Power Management
- **LMR33630ADDA** (PS2, PS9-PS14): 3A step-down DC-DC converters (7 total)
- **TPS7A7200RGTR** (IC7, IC22-IC28): 2A low-dropout linear regulators
- **TPS72325DBVR** (IC10, IC25): 2.5V precision LDO regulators
- Multiple voltage rails: 3.3V, 2.5V, 1.2V, and adjustable rails

## Design Files

### Eagle CAD Files (v9.6.2)
- **haasoscope_pro_adc_fpga_board.sch**: Main schematic
- **haasoscope_pro_adc_fpga_board.brd**: PCB layout (10-layer board)
- **Component Libraries**:
  - ADC12DL2500ACF.lbr
  - EP4CE30F23C6N.lbr
  - EPCQ16ASI8N.lbr
  - SN74AVC4T774PWR.lbr
  - NFM31PC276B0J3L.lbr
  - EEE-FT1E102UP.lbr
  - WS2812-2020.lbr
  - ADC102S021CIMM_NOPB.lbr

### KiCad Files
- **Kicad/**: KiCad conversion of the design files

### Documentation
- **haasoscope_pro_adc_fpga_board_schematics.pdf**: Complete schematic in PDF format
- **haasoscope_pro_adc_fpga_board_routing.png**: PCB routing visualization
- **haasoscope_pro_adc_fpga_board.png**: Board layout image

### Manufacturing Files
- **haasoscope_pro_adc_fpga_board_2025-03-11.zip**: Gerber files for PCB fabrication
- **haasoscope_pro_adc_fpga_board_bom.csv**: Bill of materials for JLCPCB assembly
- **haasoscope_pro_adc_fpga_board_cpl.csv**: Component placement file
- **bom.csv** / **bom.xlsx**: Detailed bill of materials with part numbers and suppliers
- **jlcpcb_parts_output.csv**: JLCPCB part mapping
- **jlcpcb_parts_scraper.py**: Python script for JLCPCB parts database

### CAM Files
- Use [jlcpcb_10_layer_v9_haas.cam](../other/jlcpcb_10_layer_v9_haas.cam) for generating Gerbers
- Design rules: [jlcpcb-10layers-haas.dru](../other/jlcpcb-10layers-haas.dru)

## Bill of Materials Summary

The board contains approximately:
- **320+ capacitors** (0402/0603/0805 sizes, plus 1000µF electrolytics for power)
- **240+ resistors** (primarily 0402/0201 sizes)
- **30+ ICs** (amplifiers, regulators, FPGA, ADC, etc.)
- **25+ inductors** (power and RF chokes)
- **18 LEDs** (status indicators plus 2 RGB LEDs)
- **7 switches/relays** (5 RF relays, 2 tactile switches)

### Key Off-Board Components
- 2× BNC connectors (Molex 73100-0105) for analog inputs
- 2× USB Type-A connectors (TE 292303-1)
- 2× Ethernet RJ45 jacks (Amphenol FRJAE-438)
- 3× SMA edge connectors (for clock/reference signals)
- 1× USB Type-C connector (for power/data)
- 1× DC power jack (PJ-002AH, 12V input)
- 1× 2x5 JTAG connector for FPGA programming
- 1× 5V 40×40×10mm cooling fan with JST connector
- 2× Light pipes (BIVAR SLP3-150-100-F)
- 2× 20×20×10mm heatsinks
- Enclosure: Hammond 1455R2201 (165×30.5×220mm aluminum extrusion)

## PCB Specifications

- **Layers**: 10-layer stackup
- **Dimensions**: Approximately 165×220mm (fits Hammond 1455R2201 case)
- **Technology**:
  - Minimum trace/space optimized for high-speed signals
  - Controlled impedance for RF traces
  - Multiple ground/power planes
  - Via stitching for EMI control
- **Manufacturer**: Designed for JLCPCB 10-layer process

## Power Requirements

- **Input voltage**: 5-24V DC (recommended: 12V 2A minimum)
- **USB Power**: USB Type-C (5V, up to 2A)
- **Consumption**: Approximately 10W, with ADC running at 3.2 GHz

## Assembly Notes

1. The board uses SMD components down to 0201 size - professional assembly recommended
2. FPGA requires proper thermal management (heatsink + fan)
3. High-speed ADC sections require careful assembly to maintain signal integrity
4. Multiple voltage regulators must be populated in correct sequence
5. USB EEPROM (93LC56B) should be programmed with configuration (see [../other/ftdi_template_haasoscopepro.xml](../other/ftdi_template_haasoscopepro.xml))

## Programming & Firmware

- **FPGA Programming**: Via JTAG connector using Quartus Programmer
- **Firmware**: See [../adc board firmware](../adc%20board%20firmware/) directory
- **USB Configuration**: Use FT_Prog tool with [../other/ftdi_template_haasoscopepro.xml](../other/ftdi_template_haasoscopepro.xml) template

## Testing & Calibration

The board includes:
- Temperature sensor (NCP18WF104F03RC thermistor at R207)
- Voltage monitoring via ADC122S021
- RGB status LEDs for operational feedback
- Multiple test points for voltage verification

## License

See [LICENSE](../LICENSE) file in the repository root.

## Design History

- Latest revision: 2025-03-11
- Original design based on Eagle 9.6.2
- Multiple board revisions with continuous improvements

## Related Documentation

- Main project repository: [../README.md](../README.md)
- Firmware documentation: [../adc board firmware](../adc%20board%20firmware/)
- Software/GUI: [../software](../software/)
- Case design: [../case](../case/)

## Resources

- [Product Page on CrowdSupply](https://www.crowdsupply.com/andy-haas/haasoscope-pro)
- [Available at Mouser](https://www.mouser.com/c/?q=Haasoscope)
- [Hackaday.io Project](https://hackaday.io/project/200773-haasoscope-pro)
- [Video Tutorials](https://www.youtube.com/playlist?list=PLB1iz3MRh5DiKQQmUUNoTf2oo_m5qS00k)

## Support

For questions and support, see the main repository or visit the project pages listed above.

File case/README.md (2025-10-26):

# Haasoscope Pro Case Panels

This directory contains the PCB panel designs for the front and back panels of the Haasoscope Pro aluminum case.

## Panel Design Files

### Front Panel
- `front panel.sch` - Eagle schematic for the front panel
- `front panel.brd` - Eagle board layout for the front panel
- `front panel_2025-02-23.zip` - Latest production files (gerbers/drill files)
- `front panel_2025-01-31.zip` - Previous version

The front panel includes connectors and indicators for user interface elements.

### Back Panel
- `back panel.sch` - Eagle schematic for the back panel
- `back panel.brd` - Eagle board layout for the back panel
- `back panel_2025-02-23.zip` - Latest production files (gerbers/drill files)
- `back panel_2025-01-31.zip` - Previous version

The back panel includes I/O connectors and power interfaces.

## Component Datasheets

The directory includes PDF datasheets for the connectors and components used on the panels:

- `1455R2201BU.pdf` - Case/enclosure datasheet
- `2212071830_HCTL-HC-TYPE-C-16P-CH3-18-3A-02_C5307756.pdf` - USB Type-C connector
- `628f655577fda929DS_CON_EDGE_SMA_5-3049320.pdf` - Edge-mount SMA connector
- `6941xx301002.pdf` - Connector datasheet
- `731000105_sd.pdf` - Connector datasheet
- `Bivar_SLP3_150_XXX_X_N-3318840.pdf` - LED light pipe
- `ENG_CD_292303_G-2061405.pdf` - Connector datasheet

## Eagle Library Files

- `725996-2.lbr` - Custom component library
- `SLP3-150-100-F.lbr` - LED light pipe library

## Manufacturing

The latest production-ready files are in the dated `.zip` archives. Use the most recent version for manufacturing:
- Front panel: `front panel_2025-02-23.zip`
- Back panel: `back panel_2025-02-23.zip`

These can be sent directly to a PCB manufacturer that supports custom panel designs.

## Design Software

The panel designs were created using **Autodesk Eagle 9.6.2**. You can open the `.sch` and `.brd` files with Eagle to view or modify the designs.

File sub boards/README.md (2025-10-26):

# Sub Boards

This directory contains Eagle design files and documentation for smaller test boards that were developed during the Haasoscope Pro design process. These boards were used to test and validate individual subsystems before integration into the final main ADC/FPGA board.

## Board Descriptions

### Clock Board
Test board for the clock generation and distribution circuitry using the ADF4350 PLL frequency synthesizer. This board validates the high-frequency clock signals needed for the ADC sampling system.

**Key Components:**
- ADF4350 PLL synthesizer
- Reference materials and datasheets

### Data Board
Test board for data handling and buffering circuits.

### Eval Board
Evaluation board for testing component configurations and interfaces.

### FPGA Board
Test board for the Altera Cyclone IV FPGA (EP4CE10/EP4CE30) and its associated support circuitry including configuration memory (EPCQ16).

**Key Components:**
- EP4CE30F23C6N FPGA
- EPCQ16ASI8N configuration memory
- Pin definition spreadsheets
- Cyclone IV datasheets and documentation

### Input Board
Test board for the analog input signal conditioning path, including differential amplifiers, variable gain stages, and DAC-controlled offset circuits.

**Key Components:**
- LMH5401/LMH6401 differential amplifiers
- OPA693 operational amplifier
- DAC8562 dual 16-bit DAC
- TLV9102 op-amp

### Logo Board
Simple board design containing the Haasoscope logo artwork for branding purposes.

### Power Board
Test board for power regulation and distribution, including multiple voltage rail generation from 5V input or higher voltage DC input.

**Key Components:**
- LMR33630 buck converter
- TPS5430 buck converter
- TPS7A7200 low-noise LDO regulator
- TPS72325 LDO regulator

### Preinput Board
Test board for the front-end input signal conditioning before the main input amplifier stage.

## File Types

Each board directory typically contains:

- **`.sch`** - Eagle schematic files
- **`.brd`** - Eagle board layout files
- **`_bom.csv`** - Bill of Materials (component list)
- **`_cpl.csv`** - Component Placement List (pick-and-place data)
- **`.lbr`** - Eagle component library files
- **`.pdf`** - Component datasheets and reference documentation
- **`.zip`** - Exported Gerber/manufacturing files (when available)

## Design Software

All board files were created using **Eagle 9.6.2** (or compatible versions).

## Purpose

These test boards allowed individual subsystems to be:
- Prototyped and tested independently
- Validated before committing to the main board design
- Used for troubleshooting and characterization
- Referenced during main board development

The lessons learned from these test boards were incorporated into the final Haasoscope Pro main board design found in the `adc board/` directory.

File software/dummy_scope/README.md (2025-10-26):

# Dummy Oscilloscope Server

A TCP socket-based simulator for testing HaasoscopePro software without physical hardware.

## Overview

The dummy server (`dummy_server.py`) simulates a HaasoscopePro oscilloscope board by implementing the same command protocol over TCP sockets. It generates realistic waveforms (sine, square, pulse) and responds to all standard oscilloscope commands, allowing you to develop and test HaasoscopePro software features without requiring physical hardware.

## Components

- **`dummy_server.py`** - Main TCP server that simulates oscilloscope board behavior
- **`USB_Socket.py`** - Socket adapter implementing USB-compatible interface for seamless integration
- **`dummy_server_config_dialog.py`** - GUI dialog for real-time waveform configuration
- **`__init__.py`** - Package initialization

## Why Use the Dummy Server?

- **Software Development** - Test new features without hardware
- **Debugging** - Reproduce specific signal conditions reliably
- **CI/CD Testing** - Automated testing in continuous integration pipelines
- **Training** - Learn HaasoscopePro software without risking hardware
- **Multi-Board Testing** - Simulate multiple boards simultaneously by running multiple servers

## Quick Start

### 1. Start the Dummy Server

```bash
cd software/dummy_scope
python dummy_server.py --port 9999
```

The server will start listening on `localhost:9999` and display:
```
Opening port 9999
Dummy oscilloscope server running on localhost:9999
Press Ctrl+C to stop
```

### 2. Connect HaasoscopePro Software

Launch the main application with the `--socket` parameter:

```bash
cd software
python HaasoscopeProQt.py --socket localhost:9999
```

The software will connect to the dummy server instead of looking for USB hardware.

**Note:** The `--socket` argument can be specified multiple times for multi-board simulation (see below).

## Command Line Options

```bash
python dummy_server.py [OPTIONS]
```

**Options:**
- `--host HOST` - Bind address (default: `localhost`)
- `--port PORT` - TCP port number (default: `9998`)
- `--firmware VERSION` - Firmware version to report (default: `0`)
- `--no-noise` - Disable noise for deterministic outputs (useful for automated testing)

**Examples:**
```bash
# Start on default port 9998
python dummy_server.py

# Start on port 9999
python dummy_server.py --port 9999

# Listen on all interfaces (allows remote connections)
python dummy_server.py --host 0.0.0.0 --port 9999

# Simulate firmware version 31
python dummy_server.py --firmware 31

# Run in deterministic mode (no noise, fixed phase) for testing
python dummy_server.py --no-noise --port 9999
```

## Waveform Configuration

### Default Waveforms

**Channel 0** (default):
- Type: Sine wave
- Frequency: 3.2 MHz
- Amplitude: 1500 ADC counts

**Channel 1** (default):
- Type: Pulse
- Frequency: 100 MHz
- Pulse rise time: 8 samples
- Pulse decay time: 40 samples
- Amplitude: 10-500 ADC counts (randomized per pulse)

### Runtime Configuration

Use the GUI configuration dialog in HaasoscopePro:
1. Launch HaasoscopePro connected to dummy server
2. Open **Tools** → **Dummy Server Config** menu
3. Select channel and waveform type
4. Adjust parameters in real-time

**Available Waveform Types:**

**Sine Wave**
- Frequency (Hz)
- Amplitude (ADC counts)

**Square Wave**
- Frequency (Hz)
- Amplitude (ADC counts)
- Rise/Fall sharpness (1-100, higher = sharper edges)

**Pulse**
- Frequency (Hz)
- Rise time constant (samples)
- Decay time constant (samples)
- Minimum amplitude (ADC counts)
- Maximum amplitude (ADC counts)

### Configuration Protocol

Waveform settings can be changed via opcode **128** (custom configuration command):

```python
# Command format: [128, channel, param_id, value_bytes...]
# See dummy_server.py for parameter IDs
```

## Simulated Features

The dummy server accurately simulates:

### Hardware State
- ✓ Firmware version reporting
- ✓ PLL lock status
- ✓ Temperature sensors (ADC and board)
- ✓ Fan control (PWM)
- ✓ External clock detection
- ✓ Board position (first/middle/last)

### Trigger System
- ✓ Rising/falling edge triggering
- ✓ Trigger level and hysteresis (delta)
- ✓ Trigger position in waveform
- ✓ Trigger counter
- ✓ Phase-coherent triggering (waveform aligns to trigger point)

### Channel Configuration
- ✓ Single/dual channel modes
- ✓ Per-channel gain (dB)
- ✓ Per-channel offset
- ✓ AC/DC coupling
- ✓ 50Ω / 1MΩ impedance
- ✓ Attenuator settings

### Data Acquisition
- ✓ Downsampling (decimation and averaging modes)
- ✓ Sample merging
- ✓ Continuous waveform generation
- ✓ Noise simulation (1% RMS by default, disable with `--no-noise` for deterministic testing)

### Advanced Features
- ✓ SPI mode switching
- ✓ Aux output control
- ✓ Clock splitter for oversampling mode
- ✓ Status register bits

## Deterministic Mode for Testing

When running automated tests, you can use the `--no-noise` flag to ensure completely reproducible outputs:

```bash
python dummy_server.py --no-noise --port 9999
```

**In deterministic mode:**
- ✓ No random noise added to waveforms (clean signals)
- ✓ Fixed starting phase (always 0.0 radians)
- ✓ Pulse amplitudes use average of min/max range (no randomization)
- ✓ Pulse positions are fixed (no jitter)
- ✓ Identical waveforms generated for identical settings

**Use cases:**
- **Screenshot comparison tests** - Pixel-perfect comparison of UI output
- **Data validation tests** - Verify processing algorithms with known inputs
- **Regression testing** - Detect changes in signal processing behavior
- **CI/CD pipelines** - Reproducible test results across different runs

**Example test workflow:**
```bash
# Start deterministic dummy server
python dummy_server.py --no-noise --port 9999 &

# Run automated tests

# All screenshots and data will be identical across runs
```

## Technical Details

### Protocol Compatibility

The dummy server implements the complete HaasoscopePro command protocol:

| Opcode | Function | Status |
|---|---|---|
| 0 | Reset | ✓ |
| 1 | Set mode (trigger type, channels) | ✓ |
| 2 | Temperature request | ✓ |
| 3 | Analog controls | ✓ |
| 5 | Return status | ✓ |
| 8 | Set trigger parameters | ✓ |
| 9 | Set downsample | ✓ |
| 10-13 | SPI commands | ✓ |
| 14 | Board position | ✓ |
| 15-19 | PLL/clock control | ✓ |
| 22 | Fan control | ✓ |
| 128 | Waveform config (custom) | ✓ |

### Data Format

Waveform data is returned as 16-bit signed integers (ADC counts):
- 12-bit ADC resolution (values: 0-4095)
- Packed into upper 12 bits of 16-bit word
- Single channel: 3.2 GS/s effective
- Dual channel: 1.6 GS/s per channel

### Phase Continuity

The server maintains phase continuity across acquisitions using a `data_counter` that increments continuously, ensuring realistic signal behavior when viewing persistent or rolling displays.

### Trigger Alignment

When trigger parameters are set (opcode 8), the server:
1. Parses trigger level, position, and delta
2. Generates waveform with threshold crossing at requested position
3. Uses `arcsin` calculation to determine starting phase
4. Reports detected trigger position back to software

This creates realistic trigger-synchronized waveforms.

## Multi-Board Simulation

Run multiple dummy servers on different ports to simulate multi-board setups:

```bash
# Terminal 1 - Board 0
python dummy_server.py --port 9998

# Terminal 2 - Board 1
python dummy_server.py --port 9999

# Terminal 3 - Board 2
python dummy_server.py --port 10000
```

Then connect (specify `--socket` multiple times):
```bash
python HaasoscopeProQt.py --socket localhost:9998 --socket localhost:9999 --socket localhost:10000
```

You can also mix hardware and dummy boards - if physical boards are detected, socket boards are added to the list.

## Troubleshooting

**Connection refused**
- Ensure dummy server is running before launching HaasoscopePro
- Check firewall settings if using remote host
- Verify port number matches between server and client

**No waveform displayed**
- Check that trigger settings are appropriate for the signal
- Try "Auto" trigger mode
- Verify channel is enabled in the UI

**Waveform looks wrong**
- Check waveform configuration via config dialog
- Verify gain/offset settings
- Check downsample settings

**Configuration changes not applying**
- Ensure only one client is connected
- Check server console for error messages
- Restart server and reconnect client

## Development Notes

### Adding New Waveform Types

Edit `dummy_server.py` and add to `_generate_waveform()`:

```python
elif wave_type == "my_waveform":
    # Your waveform generation code
    waveform = ...
    return waveform
```

Then add UI controls in `dummy_server_config_dialog.py`.

### Adding New Commands

Implement new opcode handlers in `_handle_opcode()`:

```python
elif opcode == YOUR_NEW_OPCODE:
    # Parse data
    # Update board_state
    # Return response bytes
    return response
```

### Debugging

Enable verbose logging by modifying the server:

```python
# Add at start of _handle_opcode()
print(f"Opcode {opcode}: {data.hex()}")
```

## Performance

- **Latency**: ~1-5ms per command (local connection)
- **Data Rate**: Up to 100 MB/s transfer rate
- **CPU Usage**: ~5-10% per server instance
- **Memory**: ~50 MB per server

## License

Same as parent HaasoscopePro project (open source).

## See Also

- [Main HaasoscopePro README](../../README.md)
- [HaasoscopePro User Guide](https://hackaday.io/project/200773-haasoscope-pro)
- [FTDI Driver Setup](../ftdi_setup.exe)

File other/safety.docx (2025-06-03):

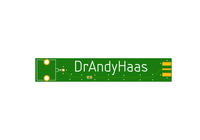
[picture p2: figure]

Regulatory Compliance and Safety Information

Haasoscope Pro and Haasoscope Pro-be

IMPORTANT: PLEASE RETAIN THIS INFORMATION FOR FUTURE REFERENCE

Getting Started

For full set up and installation instructions please visit: github.com/drandyhaas/HaasoscopePro

Warnings

- This product shall only be connected to an external power supply rated at 5V DC for the USB-C connection and a minimum current of 2A, and/or 12V DC for the barrel jack connection and a minimum current of 1A. Any external power supply used with the Haasoscope PRo shall comply with relevant regulations and standards applicable in the country of intended use.
- This product should be operated in a well-ventilated environment and the case should not be covered.
- This product should be placed on a stable, flat, non-conductive surface in use and should not be contacted by conductive items.
- The connection of unapproved devices to the connectors may affect compliance or result in damage to the unit.
- All peripherals used with the unit should comply with relevant standards for the country of use and be marked accordingly to ensure that safety and performance requirements are met. These articles include but are not limited to probes, cables, and adapters.
- Where peripherals are connected that do not include the cable or connector, the cable or connector used must offer adequate insulation and operation in order that the requirements of the relevant performance and safety requirements are met.

Institutions for safe use

To avoid malfunction or damage to your Haasoscope Pro please observe the following:

- Do not expose it to water, moisture or place it on a conductive surface whilst in operation.
- Do not expose it to heat from any source; the Haasoscope Pro is designed for reliable operation at normal ambient room temperatures.
- Take care whilst handling to avoid mechanical or electrical damage to the printed circuit board and connectors.
- Avoid handling the printed circuit board while it is powered. Only handle it by the edges to minimize the risk of electrostatic discharge damage.

Compliance information

The Haasoscope Pro complies with the relevant provisions of the RoHS Directive for the European Union. In

common with all Electrical and Electronic Equipment (EEE) the Haasoscope Pro should not be disposed of as

household waste. Alternative arrangements may apply in other jurisdictions.

Electromagnetic compatibility and operation:

- This product is in conformity with the protection requirements of EU Council Directive 2004/108/EC on the approximation of the laws of the Member States relating to electromagnetic compatibility.
- This product has been tested and found to comply with the limits for Class B Information Technology Equipment according to the European Standard.
- NOTE: This equipment has been tested and found to comply with the limits for a Class B digital device, pursuant to part 15 of the FCC Rules. These limits are designed to provide reasonable protection against harmful interference in a residential installation. This equipment generates, uses and can radiate radio frequency energy and, if not installed and used in accordance with the instructions, may cause harmful interference to radio communications. However, there is no guarantee that interference will not occur in a particular installation. If this equipment does cause harmful interference to radio or television reception, which can be determined by turning the equipment off and on, the user is encouraged to try to correct the interference by one or more of the following measures:

❍ Reorient or relocate the receiving antenna

❍ Increase the separation between the equipment and receiver

❍ Connect the equipment into an outlet on a circuit different from that to which the receiver is connected

❍ Consult the dealer or an experienced radio/TV technician for help

- This Class B digital apparatus complies with CAN ICES-3 (B). Cet appareil numérique de la classe B est conforme à la norme NMB-3 (B) du Canada.
- WARNING: Please do not alter or modify the design of this product, doing so may void your ability to use the product freely, this includes altering the frequency at which the product operates.

DrAndyHaas Electronics

215 Lane Gate Rd, Cold Spring, NY 10516 USA

DrAndyHaas.com

Informationen zur Einhaltung gesetzlicher Vorschriften und zur Sicherheit

Haasoskop Pro und Haasoskop Pro-be

WICHTIG: BITTE BEWAHREN SIE DIESE INFORMATIONEN ZUM SPÄTEREN NACHSCHLAGEN AUF

Erste Schritte

Die vollständigen Einrichtungs- und Installationsanweisungen finden Sie unter: github.com/drandyhaas/HaasoscopePro

Abnehmen

- Dieses Produkt darf nur an eine externe Stromversorgung mit 5 V DC für den USB-C-Anschluss und einem Mindeststrom von 2 A und/oder 12 V DC für den Hohlsteckeranschluss und einem Mindeststrom von 1 A angeschlossen werden. Alle mit dem Haasoscope PRo verwendeten externen Netzteile müssen den einschlägigen Vorschriften und Normen entsprechen, die im Land der beabsichtigten Verwendung gelten.
- Dieses Produkt sollte in einer gut belüfteten Umgebung betrieben werden und das Gehäuse sollte nicht abgedeckt werden.
- Dieses Produkt sollte während des Gebrauchs auf einer stabilen, flachen, nicht leitenden Oberfläche platziert werden und nicht mit leitenden Gegenständen in Berührung kommen.
- Der Anschluss nicht zugelassener Geräte an die Anschlüsse kann die Konformität beeinträchtigen oder zu Schäden am Gerät führen.
- Alle mit dem Gerät verwendeten Peripheriegeräte sollten den relevanten Standards des jeweiligen Landes entsprechen und entsprechend gekennzeichnet sein, um sicherzustellen, dass die Sicherheits- und Leistungsanforderungen erfüllt werden. Zu diesen Artikeln gehören unter anderem Sonden, Kabel und Adapter.
- Wenn Peripheriegeräte angeschlossen werden, die kein Kabel oder Stecker enthalten, muss das verwendete Kabel oder der Stecker eine ausreichende Isolierung und Funktion bieten, damit die Anforderungen der relevanten Leistungs- und Sicherheitsanforderungen erfüllt werden.

Institutionen zur sicheren Nutzung

Um Fehlfunktionen oder Schäden an Ihrem Haasoscope Pro zu vermeiden, beachten Sie bitte Folgendes:

- Setzen Sie es während des Betriebs weder Wasser noch Feuchtigkeit aus und stellen Sie es nicht auf eine leitfähige Oberfläche.
- Setzen Sie es keiner Hitzequelle aus; Das Haasoscope Pro ist für einen zuverlässigen Betrieb bei normalen Raumtemperaturen ausgelegt.
- Seien Sie bei der Handhabung vorsichtig, um mechanische oder elektrische Schäden an der Leiterplatte und den Anschlüssen zu vermeiden.
- Vermeiden Sie den Umgang mit der Leiterplatte, während sie mit Strom versorgt wird. Fassen Sie es nur an den Kanten an, um das Risiko einer Beschädigung durch elektrostatische Entladung zu minimieren.

Compliance-Informationen

Das Haasoscope Pro entspricht den einschlägigen Bestimmungen der RoHS-Richtlinie für die Europäische Union. In

Wie bei allen elektrischen und elektronischen Geräten (EEE) sollte der Haasoscope Pro nicht entsorgt werden

Hausmüll. In anderen Gerichtsbarkeiten können alternative Regelungen gelten.

Elektromagnetische Verträglichkeit und Betrieb:

- Dieses Produkt entspricht den Schutzanforderungen der Richtlinie 2004/108/EG des EU-Rats zur Angleichung der Rechtsvorschriften der Mitgliedstaaten zur elektromagnetischen Verträglichkeit.
- Dieses Produkt wurde getestet und entspricht den Grenzwerten für Informationstechnologiegeräte der Klasse B gemäß der europäischen Norm.
- HINWEIS: Dieses Gerät wurde getestet und entspricht den Grenzwerten für ein digitales Gerät der Klasse B gemäß Teil 15 der FCC-Bestimmungen. Diese Grenzwerte sollen einen angemessenen Schutz vor schädlichen Störungen in einer Wohnanlage bieten. Dieses Gerät erzeugt und verwendet Hochfrequenzenergie und kann diese ausstrahlen. Wenn es nicht gemäß den Anweisungen installiert und verwendet wird, kann es schädliche Störungen der Funkkommunikation verursachen. Es gibt jedoch keine Garantie dafür, dass bei einer bestimmten Installation keine Störungen auftreten. Wenn dieses Gerät schädliche Störungen beim Radio- oder Fernsehempfang verursacht, was durch Aus- und Einschalten des Geräts festgestellt werden kann, wird dem Benutzer empfohlen, zu versuchen, die Störung durch eine oder mehrere der folgenden Maßnahmen zu beheben:

❍ Richten Sie die Empfangsantenne neu aus oder verschieben Sie sie

❍ Erhöhen Sie den Abstand zwischen Gerät und Empfänger

❍ Schließen Sie das Gerät an eine Steckdose an, die zu einem anderen Stromkreis gehört als der, an den der Empfänger angeschlossen ist

❍ Wenden Sie sich an den Händler oder einen erfahrenen Radio-/TV-Techniker

- Dieses digitale Gerät der Klasse B entspricht CAN ICES-3 (B). Dieses digitale Gerät der Klasse B entspricht der kanadischen Norm ICES-3 (B).
- WARNUNG: Bitte verändern oder modifizieren Sie das Design dieses Produkts nicht. Dies kann dazu führen, dass Sie das Produkt nicht mehr frei nutzen können, einschließlich der Änderung der Betriebsfrequenz des Produkts.

DrAndyHaas Electronics

215 Lane Gate Rd, Cold Spring, NY 10516 USA

DrAndyHaas.com

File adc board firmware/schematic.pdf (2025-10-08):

Date: October 08, 2025 | coincidence.bdf | Project: coincidence

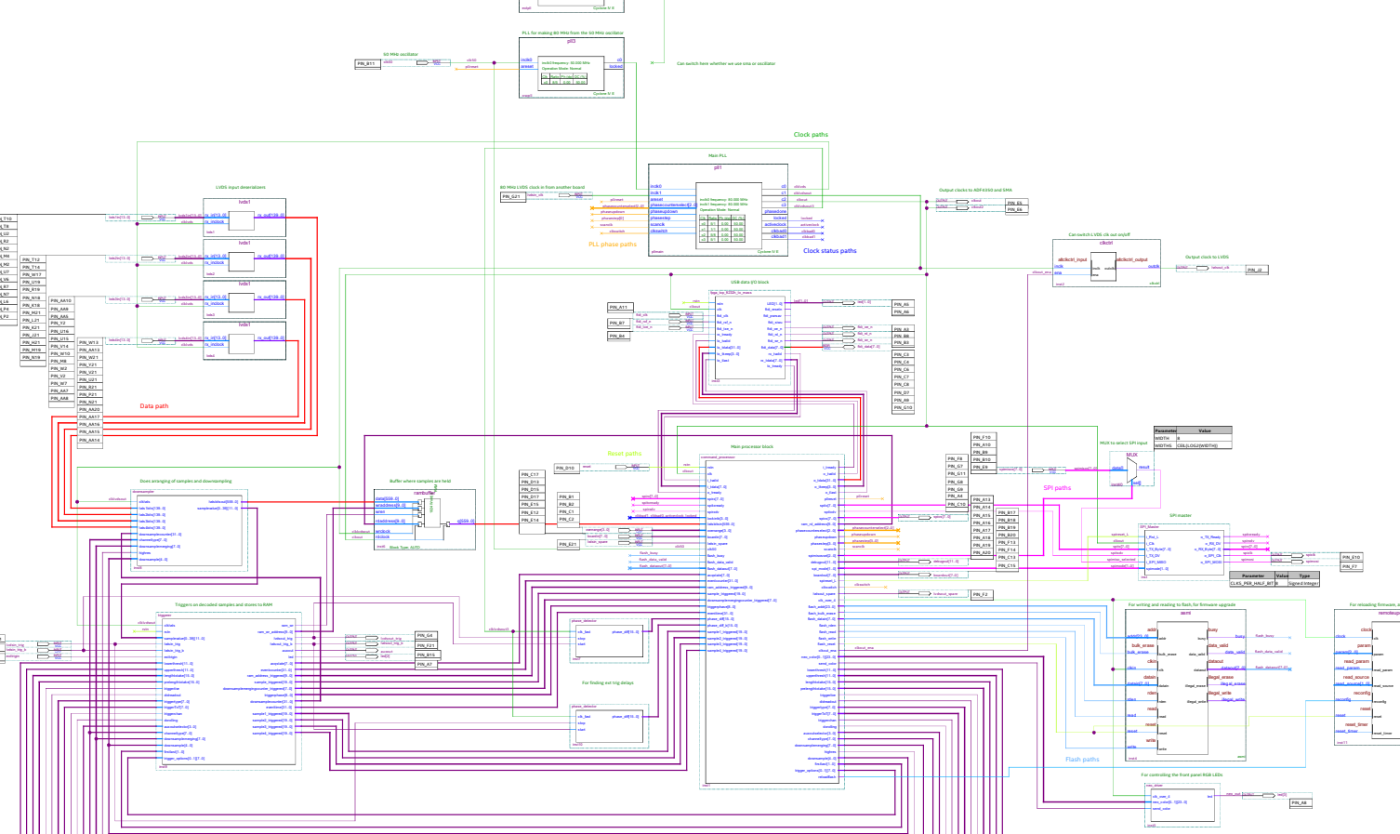
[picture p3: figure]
neo_out; lvds1in[13..0]; lvds4in[13..0]; lvds3in[13..0]; lvds2in[13..0]; led[1..0]; clkout; clkout clklvdsout clkout; clklvds clklvds clklvds clklvds; flash_dataout[7..0]; flash_data_valid; flash_busy; flash_busy flash_data_valid; spitxready; spirxdv spirx[7..0] spiclk spimosi spitxdv; spimisos[7..0] spirx[7..0] spitxready; spirxdv clkbad1, clkbad0, activeclock, locked; clkout_ena; rstn; spireset_L; clklvdsout; clk50; clklvds clkout clklvdsout3; locked activeclock clkbad0 clkbad1; clklvdsout3; LVDS input deserializers; Buffer where samples are held; SPI master MUX to select SPI input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

Page 1 of 1 | Revision: coincidence

## spitx[7..0] spimode[1..0] spimiso_selected

# clkswitch pllreset phasecounterselect[2..0] phaseupdown phasestep[3..0] scanclk

## pllreset clkswitch phasecounterselect[2..0] phaseupdown phasestep[0] scanclk

# pllreset pllreset

## 50 MHz oscillator

## For writing and reading to flash, for firmware upgrade

Output clocks to ADF4350 and SMA | Output clock to LVDS Can switch LVDS clk out on/off

## For controlling the front panel RGB LEDs

## Does arranging of samples and downsampling Triggers on decoded samples and stores to RAM

PLL for making 80 MHz from the 50 MHz oscillator PLL for making 80 MHz from the 10 MHz external SMA ref clock 10 MHz external SMA ref clock in

## Can switch here whether we use sma or oscillator

## For reloading firmware, after an upgrade

VCC

clk_ext | INPUT

lvds4bits[139..0] downsamplecounter[31..0] channeltype[7..0] downsamplemerging[7..0] highres downsample[4..0]

inclk1 frequency: 80.000 MHz Operation Mode: Normal Clk | Ratio | Ph (dg) | DC (%) c0 | 5/1 | 0.00 | 50.00

## areset phasecounterselect[2..0] phaseupdown

inclk0 frequency: 50.000 MHz Operation Mode: Normal Clk | Ratio | Ph (dg) | DC (%) c0 | 8/5 | 0.00 | 50.00

## pll3

inclk0 frequency: 10.000 MHz Operation Mode: Normal Clk | Ratio | Ph (dg) | DC (%) c0 | 8/1 | 0.00 | 50.00

## inclk0

areset | c0 locked

## pll2

## busy busy

clk | data_out data_out param

## remoteupdate clock param[2..0] read_param

reset reset_timer | busy data_out[28..0] remoteupdate

triggerphase[8..0] downsamplecounter[31..0] eventtime[31..0] sample1_triggered[19..0] sample2_triggered[19..0] sample3_triggered[19..0] sample4_triggered[19..0] flash_dataout[7..0] acqstate[7..0] eventcounter[31..0] ram_address_triggered[9..0] sample_triggered[19..0] downsamplemergingcounter_triggered[7..0]

triggerphase[8..0] eventtime[31..0] phase_diff[15..0] phase_diff_b[15..0] sample1_triggered[19..0] sample2_triggered[19..0] sample3_triggered[19..0] sample4_triggered[19..0] o_tdata[31..0] o_tkeep[3..0] o_tlast pllreset spitx[7..0] spitxdv

PIN_T10 PIN_T8 PIN_U2 PIN_R2 PIN_N2 PIN_M4 PIN_M2 PIN_U7 PIN_V6 PIN_R7 PIN_N7 PIN_L6 PIN_P4 PIN_P2 PIN_W13 PIN_AA13 PIN_W21 PIN_Y21 PIN_V21 PIN_U21 PIN_R21 PIN_P21 PIN_N21 PIN_AA20 PIN_AA17 PIN_AA16 PIN_AA15 PIN_AA14

PIN_AA10 PIN_AA9 PIN_AA5 PIN_Y2 PIN_U16 PIN_U15 PIN_V14 PIN_W10 PIN_M8 PIN_W2 PIN_V2 PIN_W7 PIN_AA7 PIN_AA8

PIN_T12 PIN_T14 PIN_W17 PIN_U19 PIN_R19 PIN_N18 PIN_K18 PIN_M21 PIN_L21 PIN_K21 PIN_J21 PIN_H21 PIN_M19 PIN_N19 | PIN_F10 PIN_A10 PIN_B9 PIN_B10 PIN_E9
PIN_B1 PIN_B2 PIN_C1 PIN_C2 PIN_C17 PIN_D13 PIN_D15 PIN_D17 PIN_E15 PIN_E12 PIN_E14 PIN_D21 | PIN_E21 PIN_H2

## PIN_A12

## PIN_E16

PIN_A3 PIN_B8 PIN_B3 | PIN_F8 PIN_G7 PIN_G11 PIN_G8 PIN_G9 PIN_A4 PIN_C10 | PIN_E10 PIN_F7
PIN_A13 PIN_A14 PIN_A15 PIN_A16 PIN_A17 PIN_A18 PIN_A19 PIN_A20 | PIN_B17 PIN_B18 PIN_B19 PIN_B20 PIN_F13 PIN_F14 PIN_C13 PIN_C15 PIN_G4 | PIN_F2 PIN_F21
PIN_C3 PIN_C4 PIN_C6 PIN_C7 PIN_C8 PIN_D7 PIN_A9 PIN_G10 | WIDTH | 8 WIDTHS CEIL(LOG2(WIDTH)) Parameter | Value | CLKS_PER_HALF_BIT 8 | Signed Integer Parameter | Value | Type

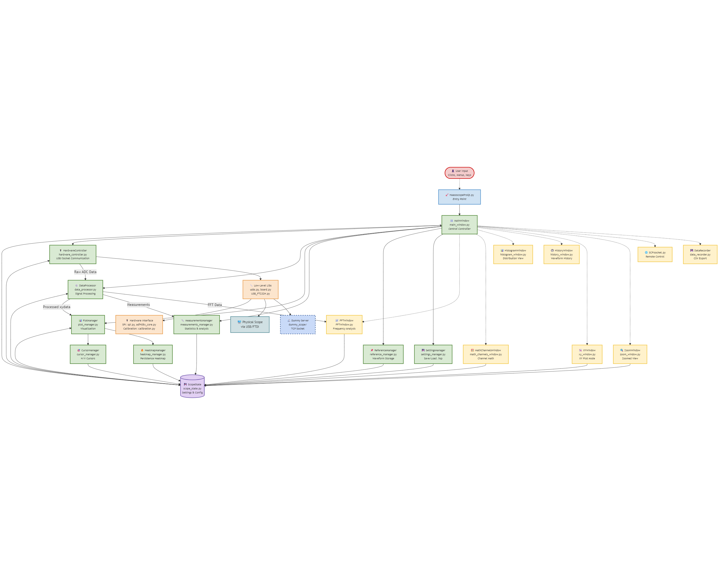
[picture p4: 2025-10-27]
software/diagram.png

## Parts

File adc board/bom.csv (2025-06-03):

Comment | topDesignator | bottomDesignator | Footprint | JLCPCB Part # | MFR Part # | Manufacturer | Description | Stock | Package | Datasheet
47nF | C1,C2,C157 |  | C0402 | C272875 | CC0402KRX7R9BB473 | Yageo | 50V 47nF X7R ±10% 0402 Multilayer Ceramic Capacitors MLCC - SMD/SMT ROHS | 407007 | 402 | https://www.lcsc.com/datasheet/lcsc_datasheet_2304140030_YAGEO-CC0402KRX7R9BB473_C272875.pdf
1.0pF | C105 |  | C0402 | C72134 | GJM1555C1H1R0WB01D | Murata Electronics | 50V 1pF C0G 0402 Multilayer Ceramic Capacitors MLCC - SMD/SMT ROHS | 142137 | 402 | https://wmsc.lcsc.com/wmsc/upload/file/pdf/v2/lcsc/1811081612_Murata-Electronics-GJM1555C1H1R0WB01D_C72134.pdf
1.3pF | C106 |  | C0402 | C88880 | GJM1555C1H1R3WB01D | Murata Electronics | 50V 1.3pF C0G 0402 Multilayer Ceramic Capacitors MLCC - SMD/SMT ROHS | 13082 | 402 | https://wmsc.lcsc.com/wmsc/upload/file/pdf/v2/lcsc/2304140030_Murata-Electronics-GJM1555C1H1R3WB01D_C88880.pdf
16pF | C127,C128,C80 |  | C0402 | C77590 | CC0402JRNPO9BN160 | Yageo | 50V 16pF NP0 ±5% 0402 Multilayer Ceramic Capacitors MLCC - SMD/SMT ROHS | 133648 | 402 | https://wmsc.lcsc.com/wmsc/upload/file/pdf/v2/lcsc/2304140030_YAGEO-CC0402JRNPO9BN160_C77590.pdf
0.75pF | C136 |  | C0402 | C76914 | GJM1555C1HR75WB01D | Murata Electronics | 50V 0.75pF C0G 0402 Multilayer Ceramic Capacitors MLCC - SMD/SMT ROHS | 13542 | 402 | https://www.lcsc.com/datasheet/lcsc_datasheet_1811081611_Murata-Electronics-GJM1555C1HR75WB01D_C76914.pdf
7.5pF | C138,C161 |  | C0402 | C505479 | CC0402CRNPO9BN7R5 | Yageo | 50V 7.5pF NP0 0402 Multilayer Ceramic Capacitors MLCC - SMD/SMT ROHS | 15503 | 402 | https://wmsc.lcsc.com/wmsc/upload/file/pdf/v2/lcsc/2003312210_YAGEO-CC0402CRNPO9BN7R5_C505479.pdf
11pF | C139,C162 |  | C0402 | C161525 | GRM1555C1H110JA01D | Murata Electronics | 50V 11pF C0G ±5% 0402 Multilayer Ceramic Capacitors MLCC - SMD/SMT ROHS | 15839 | 402 | https://www.lcsc.com/datasheet/lcsc_datasheet_2304140030_Murata-Electronics-GRM1555C1H110JA01D_C161525.pdf
6.8pF | C140,C163 |  | C0402 | C1576 | 0402CG6R8C500NT | Fh (guangdong Fenghua Advanced tech) | 50V 6.8pF C0G 0402 Multilayer Ceramic Capacitors MLCC - SMD/SMT ROHS | 128596 | 402 | https://www.lcsc.com/datasheet/lcsc_datasheet_2304140030_FH--Guangdong-Fenghua-Advanced-Tech-0402CG6R8C500NT_C1576.pdf
3.0pF | C153 |  | C0402 | C327228 | CC0402BRNPO9BN3R0 | Yageo | 50V 3pF NP0 0402 Multilayer Ceramic Capacitors MLCC - SMD/SMT ROHS | 114561 | 402 | https://wmsc.lcsc.com/wmsc/upload/file/pdf/v2/lcsc/1811141233_YAGEO-CC0402BRNPO9BN3R0_C327228.pdf
2.7nF | C155 |  | C0402 | C22435967 | CGA0402X7R272K500GT | Hre | 50V 2.7nF X7R ±10% 0402 Multilayer Ceramic Capacitors MLCC - SMD/SMT ROHS | 139805 | 402 | https://www.lcsc.com/datasheet/lcsc_datasheet_2405231404_HRE-CGA0402X7R272K500GT_C22435967.pdf
680pF | C156 |  | C0402 | C107030 | CC0402KRX7R9BB681 | Yageo | 50V 680pF X7R ±10% 0402 Multilayer Ceramic Capacitors MLCC - SMD/SMT ROHS | 119274 | 402 | https://www.lcsc.com/datasheet/lcsc_datasheet_2304140030_YAGEO-CC0402KRX7R9BB681_C107030.pdf
3.9pF | C158 |  | C0402 | C1566 | 0402CG3R9C500NT | Fh (guangdong Fenghua Advanced tech) | 50V 3.9pF C0G 0402 Multilayer Ceramic Capacitors MLCC - SMD/SMT ROHS | 302231 | 402 | https://www.lcsc.com/datasheet/lcsc_datasheet_2304140030_FH--Guangdong-Fenghua-Advanced-Tech-0402CG3R9C500NT_C1566.pdf
2.4pF | C159 |  | C0402 | C48346 | 0402CG2R4C500NT | Fh (guangdong Fenghua Advanced tech) | 50V 2.4pF C0G 0402 Multilayer Ceramic Capacitors MLCC - SMD/SMT ROHS | 312060 | 402 | https://wmsc.lcsc.com/wmsc/upload/file/pdf/v2/lcsc/2304140030_FH--Guangdong-Fenghua-Advanced-Tech-0402CG2R4C500NT_C48346.pdf
0.1uF | C245,C247,C249,C250,C252,C254,C256,C258,C259,C260,C262,C263,C264,C266,C267,C268,C270,C271,C272,C274,C275,C276,C278,C279,C280,C282,C283,C284,C286,C318 |  | RESC0402_N | C307331 | CL05B104KB54PNC | Samsung electro-mechanics | 50V 100nF X7R ±10% 0402 Multilayer Ceramic Capacitors MLCC - SMD/SMT ROHS | 10822474 | 402 | https://www.lcsc.com/datasheet/lcsc_datasheet_2304140030_Samsung-Electro-Mechanics-CL05B104KB54PNC_C307331.pdf
NFM31PC276B0J3L | C5,C15,C25,C35,C45 |  | NFM31HK103R1H3L | C118987 | NFM31PC276B0J3L | Murata Electronics | 27uF ±20% 5mΩ SMD-3P,1.6x3.2mm Feed Through Capacitors ROHS | 4879 | SMD-3P,1.6x3.2mm | https://www.lcsc.com/datasheet/lcsc_datasheet_1810201315_Murata-Electronics-NFM31PC276B0J3L_C118987.pdf
0.1uF | C50,C107,C108,C109,C110,C111,C112,C113,C47,C49,C101,C102,C58,C59,C60,C73,C74,C78,C84,C85,C86,C87,C88,C89,C90,C91,C92,C93,C94,C95,C96,C97,C98,C44,C55,C56,C114,C115,C116,C117,C119,C121,C122,C123,C124,C125,C53,C54,C75,C129,C130,C131,C132,C133,C134,C135,C142,C143,C144,C145,C146,C147,C148,C149,C150,C151,C152,C154,C51,C77,C3,C4,C7,C9,C17,C19,C27,C29,C37,C39 | C12,C20,C23,C31,C33,C61,C62,C63,C64,C65,C66,C67,C68,C69,C70,C71 | RESC0402_N | C1525 | CL05B104KO5NNNC | Samsung electro-mechanics | 16V 100nF X7R ±10% 0402 Multilayer Ceramic Capacitors MLCC - SMD/SMT ROHS | 12512624 | 402 | https://www.lcsc.com/datasheet/lcsc_datasheet_2304140030_Samsung-Electro-Mechanics-CL05B104KO5NNNC_C1525.pdf
10uF | C6,C8,C10,C13,C16,C18,C21,C24,C26,C28,C34,C36,C38,C40,C41,C42,C43,C46,C48,C52,C76,C118,C120,C126,C170,C173,C174,C175,C176,C242,C243,C244,C246,C248,C251,C253,C255,C257,C287,C288,C289,C319,C320,C321,C322 |  | RESC0805_N | C15850 | CL21A106KAYNNNE | Samsung electro-mechanics | 25V 10uF X5R ±10% 0805 Multilayer Ceramic Capacitors MLCC - SMD/SMT ROHS | 7845551 | 805 | https://www.lcsc.com/datasheet/lcsc_datasheet_2304140030_Samsung-Electro-Mechanics-CL21A106KAYNNNE_C15850.pdf
1uF | C72,C82,C261,C265,C269,C273,C277,C281,C285 | C11,C14,C22,C30,C32 | RESC0402_N | C52923 | CL05A105KA5NQNC | Samsung electro-mechanics | 25V 1uF X5R ±10% 0402 Multilayer Ceramic Capacitors MLCC - SMD/SMT ROHS | 4632086 | 402 | https://www.lcsc.com/datasheet/lcsc_datasheet_2304140030_Samsung-Electro-Mechanics-CL05A105KA5NQNC_C52923.pdf
22uF | C81,C166,C290,C291,C292,C293,C294,C295,C296,C297,C298,C299,C300,C301,C302,C303,C304,C305,C306,C307,C308,C309,C310,C311,C312,C313,C314,C315,C316,C317 |  | RESC0805_N | C45783 | CL21A226MAQNNNE | Samsung electro-mechanics | 25V 22uF X5R ±20% 0805 Multilayer Ceramic Capacitors MLCC - SMD/SMT ROHS | 972962 | 805 | https://www.lcsc.com/datasheet/lcsc_datasheet_2304140030_Samsung-Electro-Mechanics-CL21A226MAQNNNE_C45783.pdf
1000uF | C83,C99,C100,C165,C167,C168,C171,C172 |  | EEE0JA152UAP | C401766 | EEEFT1E102UP | Panasonic | 1000uF 25V 1.19A@100kHz 60mΩ@100kHz ±20% SMD,D10xL10.2mm Aluminum Electrolytic Capacitors - SMD ROHS | 15217 | SMD,D10xL10.2mm | https://wmsc.lcsc.com/wmsc/upload/file/pdf/v2/lcsc/1912111437_PANASONIC-EEEFT1E102UP_C401766.pdf
B340A | D10 |  | SMA-DIODE | C64982 | B340A | mdd(microdiode semiconductor) | 40V Independent Type 550mV@3A 3A SMA(DO-214AC) Schottky Diodes ROHS | 52411 | SMA(DO-214AC) | https://www.lcsc.com/datasheet/lcsc_datasheet_2407101107_MDD-Microdiode-Semiconductor-B340A_C64982.pdf
50mΩ 220Ω@100MHz 0603 | FB2 |  | 603 | C14709 | BLM18PG121SN1D | Murata Electronics | 50mΩ ±25% 120Ω@100MHz 0603 Ferrite Beads ROHS | 1044223 | 603 | https://www.lcsc.com/datasheet/lcsc_datasheet_2304140030_Murata-Electronics-BLM18PG121SN1D_C14709.pdf
OPA859IDSGR | FL1,FL2,FL3,FL4 |  | SON50P200X200X80-9N | C2058582 | OPA859IDSGR | Texas Instruments | WSON-8-EP(2x2) Operational Amplifier ROHS | 4398 | WSON-8-EP(2x2) | https://www.lcsc.com/datasheet/lcsc_datasheet_2302221330_Texas-Instruments-OPA859IDSGR_C2058582.pdf
TPS72325DBVR | IC10,IC25 |  | SOT95P280X145-5N | C69932 | TPS72325DBVR | Texas Instruments | 200mA 65dB Fixed 2.5V Negative electrode 10V SOT-23-5 Voltage Regulators - Linear, Low Drop Out (LDO) Regulators ROHS | 3867 | SOT-23-5 | https://www.lcsc.com/datasheet/lcsc_datasheet_1809251717_Texas-Instruments-TPS72325DBVR_C69932.pdf
LMH5401IRMST | IC13,IC21 |  | LMH5401IRMSR | C2057542 | LMH5401IRMST | Texas Instruments | 6.2GHz Single Channel 8GHz QFN-14(2.5x2.5) Differential Amplifiers ROHS | 23 | QFN-14(2.5x2.5) | https://wmsc.lcsc.com/wmsc/upload/file/pdf/v2/lcsc/2303012230_Texas-Instruments-LMH5401IRMST_C2057542.pdf
LMH6401IRMZR | IC14,IC29 |  | LMH6401IRMZR | C2060538 | LMH6401IRMZR | Texas Instruments | Single Channel 4.5GHz UQFN-16(3x3) Programmable / Variable Gain Amplifiers (PGA/VGA) ROHS | 154 | UQFN-16(3x3) | https://wmsc.lcsc.com/wmsc/upload/file/pdf/v2/lcsc/2303012000_Texas-Instruments-LMH6401IRMZR_C2060538.pdf
DAC8562SDGSR | IC17 |  | SOP50P490X110-10N | C127965 | DAC8562SDGSR | Texas Instruments | VSSOP-10-0.5mm Digital to Analog Converters (DAC) ROHS | 664 | VSSOP-10-0.5mm | https://www.lcsc.com/datasheet/lcsc_datasheet_1809291523_Texas-Instruments-DAC8562SDGSR_C127965.pdf
SN74AVC4T774PWR | IC2,IC15,IC30 |  | SOP65P640X120-16N | C129363 | SN74AVC4T774PWR | Texas Instruments | 1.1V~3.6V 1 4 1.1V~3.6V 380Mbps TSSOP-16 Translators, Level Shifters ROHS | 6333 | TSSOP-16 | https://www.lcsc.com/datasheet/lcsc_datasheet_1811081942_Texas-Instruments-SN74AVC4T774PWR_C129363.pdf
ADC122S021CIMM_NOPB | IC3 |  | SOP65P490X110-8N | C206499 | ADC122S021CIMM/NOPB | Texas Instruments | 12 Bits 200kHz VSSOP-8-0.65mm Analog to Digital Converters (ADC) ROHS | 385 | VSSOP-8-0.65mm | https://www.lcsc.com/datasheet/lcsc_datasheet_1806121318_Texas-Instruments-ADC122S021CIMM-NOPB_C206499.pdf
TLV9102IPWR | IC4,IC18,IC33 |  | SOP65P640X120-8N | C2058017 | TLV9102IPWR | Texas Instruments | Dual channel 10pA 1.1MHz TSSOP-8 Operational Amplifier ROHS | 19 | TSSOP-8 | https://wmsc.lcsc.com/wmsc/upload/file/pdf/v2/lcsc/2303012230_Texas-Instruments-TLV9102IPWR_C2058017.pdf
EP4CE30F23C6N | IC5 |  | BGA484C100P22X22_2300X2300X240 | C6549145 | EP4CE30F23C7N | intel/altera | 28848 1803 FBGA-484(23x23) Programmable Logic Device (CPLDs/FPGAs) ROHS | 43 | FBGA-484_23x23 | https://wmsc.lcsc.com/wmsc/upload/file/pdf/v2/lcsc/2312051050_Intel-Altera-EP4CE30F23C7N_C6549145.pdf
EPCQ16ASI8N | IC6 |  | SOIC127P600X175-8N | C467192 | EPCQ16ASI8N | intel/altera | SOIC-8 Programmable Logic Device (CPLDs/FPGAs) ROHS | 239 | SOIC-8 | https://wmsc.lcsc.com/wmsc/upload/file/pdf/v2/lcsc/2304140030_Intel-Altera-EPCQ16ASI8N_C467192.pdf
TPS7A7200RGTR | IC7,IC22,IC23,IC24,IC26,IC27,IC28 |  | QFN50P300X300X100-17N | C180439 | TPS7A7200RGTR | Texas Instruments | 2A Adjustable 900mV~5V Positive electrode 6.5V VQFN-16-EP(3x3) Voltage Regulators - Linear, Low Drop Out (LDO) Regulators ROHS | 253 | VQFN-16-EP(3x3) | https://www.lcsc.com/datasheet/lcsc_datasheet_2303021230_Texas-Instruments-TPS7A7200RGTR_C180439.pdf
FT232HQ | IC8 |  | QFN48_8MM | C82158 | FT232HQ-REEL | Ftdi | QFN-48-EP(8x8) USB Converters ROHS | 1272 | QFN-48-EP(8x8) | https://www.lcsc.com/datasheet/lcsc_datasheet_2409300133_FTDI-FT232HQ-REEL_C82158.pdf
93LC56B | IC9 |  | SOT23-6 | C190271 | 93LC56BT-I/OT | Microchip Tech | 2Kbit SPI SOT-23-6 EEPROM ROHS | 3992 | SOT-23-6 | https://www.lcsc.com/datasheet/lcsc_datasheet_2410311238_Microchip-Tech-93LC56BT-I-OT_C190271.pdf
G6K-2F-RF-T-TR03_DC5 | K1,K2,K3,K4,K5 |  | G6K2FRFTTR03DC5 | C5644852 | G6K-2F-RF-T-TR03-DC5 | Omron Electronics | Two Sets of Conversion: 2C (DPDT-Conversion) 1A 5V Signal Relays ROHS | 266 | - | https://www.lcsc.com/datasheet/lcsc_datasheet_2410010202_Omron-Electronics-G6K-2F-RF-T-TR03-DC5_C5644852.pdf
TLP3475_TPF | K7,K6 |  | TLP3475TPF | C2152213 | TLP3475(TP,F | Toshiba | 1 Form A(SPST-NO) 1.27V 50V 1Ω 300mA AC,DC VSON-4(1.5x2.5) Solid State Relays - MOS Output (PhotoMOS) ROHS | 0 | VSON-4(1.5x2.5) | https://www.lcsc.com/datasheet/lcsc_datasheet_2411220132_TOSHIBA-TLP3475-TP-F_C2152213.pdf
10uH | L1,L2,L9,L10,L11,L12,L13,L14 |  | CDRH125 | C339970 | YDRH105R-100M | Yjycoin | 4.45A 10uH ±20% SMD,10.1x10.1mm Power Inductors ROHS | 1263 | SMD,10.1x10.1mm | https://wmsc.lcsc.com/wmsc/upload/file/pdf/v2/lcsc/2304140030_YJYCOIN-YDRH105R-100M_C339970.pdf
6.8nH | L16,L17 |  | RESC0402_N | C77110 | LQG15HS6N8J02D | Murata Electronics | 600mA 6.8nH ±5% 220mΩ 0402 Inductors (SMD) ROHS | 149413 | 402 | https://wmsc.lcsc.com/wmsc/upload/file/pdf/v2/lcsc/2304140030_Murata-Electronics-LQG15HS6N8J02D_C77110.pdf
3.3nH | L4,L7 |  | RESC0402_N | C162542 | LQG15HS3N3B02D | Murata Electronics | 800mA 3.3nH 125mΩ 0402 Inductors (SMD) ROHS | 22225 | 402 | https://www.lcsc.com/datasheet/lcsc_datasheet_2304140030_Murata-Electronics-LQG15HS3N3B02D_C162542.pdf
15nH | L8,L15,L18,L19 |  | RESC0402_N | C521066 | LQG15HS15NH02D | Murata Electronics | 450mA 15nH ±3% 320mΩ 0402 Inductors (SMD) ROHS | 8033 | 402 | https://wmsc.lcsc.com/wmsc/upload/file/pdf/v2/lcsc/2304140030_Murata-Electronics-LQG15HS15NH02D_C521066.pdf
red | LED1,LED2,LED3,LED4,LED25,LED26,LED27,LED28,LED29,LED30,LED32,LED41,LED42,LED43,LED45,LED46,LED47,LED48 |  | CHIP-LED0603 | C2286 | KT-0603R | Hubei Kento Elec | -40℃~+85℃ Red 0603 LED Indication - Discrete ROHS | 2797098 | 603 | https://www.lcsc.com/datasheet/lcsc_datasheet_1810231112_Hubei-KENTO-Elec-KT-0603R_C2286.pdf
LMR33630ADDA | PS2,PS9,PS10,PS11,PS12,PS13,PS14 |  | SOIC127P600X170-9N | C841384 | LMR33630ADDAR | Texas Instruments | Step-down type Adjustable 3.8V~36V 1V~24V 3A ESOP-8 DC-DC Converters ROHS | 783 | ESOP-8 | https://www.lcsc.com/datasheet/lcsc_datasheet_2410121900_Texas-Instruments-LMR33630ADDAR_C841384.pdf
S8050 | Q1,Q4,Q5,Q7,Q8,Q9 |  | SOT-23 | C7420370 | SS8050 | Hongjiacheng | 25V 300mW 120@100mA,1.0V 1.5A NPN SOT-23 Bipolar (BJT) ROHS | 975913 | SOT-23 | https://wmsc.lcsc.com/wmsc/upload/file/pdf/v2/lcsc/2312221203_hongjiacheng-SS8050_C7420370.pdf
FDN340P | Q2 |  | SOT-23 | C15127 | AO3401A | Alpha & Omega Semicon | 30V 4A 44mΩ@10V,4.3A 1.4W 1.3V@250uA 1 Piece P-Channel SOT-23 MOSFETs ROHS | 1229349 | SOT-23 | https://www.lcsc.com/datasheet/lcsc_datasheet_2412061733_Alpha---Omega-Semicon-AO3401A_C15127.pdf
100 | R1,R2,R3,R4 | R17,R19,R20,R21,R23,R24,R25,R26,R39,R54,R55,R56,R57,R58,R59,R60,R61,R62,R63,R64,R65,R66,R67,R68,R69,R70,R71,R72,R73,R74,R75,R76,R77,R94,R95,R96,R97,R98,R99,R100,R101,R102,R103,R104,R105,R106,R107,R108,R109,R110,R111,R112,R113,R114,R115,R116,R117,R118,R119,R120 | R0201 | C270366 | 0201WMF1000TEE | uni-royal(uniroyal elec) | 50mW Thick Film Resistors 25V ±1% ±200ppm/℃ 100Ω 0201 Chip Resistor - Surface Mount ROHS | 1236836 | 201 | https://wmsc.lcsc.com/wmsc/upload/file/pdf/v2/lcsc/2205311945_UNI-ROYAL-Uniroyal-Elec-0201WMF1000TEE_C270366.pdf
127 | R131,R132,R189,R190 |  | R0402 | C1509602 | ARG02BTC1270 | Viking Tech | 62.5mW Thin Film Resistor 50V ±25ppm/℃ ±0.1% 127Ω 0402 Chip Resistor - Surface Mount ROHS | 6925 | 402 | https://www.lcsc.com/datasheet/lcsc_datasheet_2304140030_Viking-Tech-ARG02BTC1270_C1509602.pdf
66.5 | R133,R191 |  | R0402 | C368442 | WR04X66R5FTL | Walsin Tech Corp | 62.5mW Thick Film Resistors 50V ±100ppm/℃ ±1% 66.5Ω 0402 Chip Resistor - Surface Mount ROHS | 6649 | 402 | https://wmsc.lcsc.com/wmsc/upload/file/pdf/v2/lcsc/2304140030_Walsin-Tech-Corp-WR04X66R5FTL_C368442.pdf
22.6 | R134,R192 |  | R0402 | C272377 | RC0402FR-0722R6L | Yageo | 62.5mW Thick Film Resistors 50V ±100ppm/℃ ±1% 22.6Ω 0402 Chip Resistor - Surface Mount ROHS | 7664 | 402 | https://www.lcsc.com/datasheet/lcsc_datasheet_2304140030_YAGEO-RC0402FR-0722R6L_C272377.pdf
220 | R135,R193 |  | R0402 | C25091 | 0402WGF2200TCE | uni-royal(uniroyal elec) | 62.5mW Thick Film Resistors 50V ±100ppm/℃ ±1% 220Ω 0402 Chip Resistor - Surface Mount ROHS | 1483972 | 402 | https://www.lcsc.com/datasheet/lcsc_datasheet_2205311900_UNI-ROYAL-Uniroyal-Elec-0402WGF2200TCE_C25091.pdf
100k | R137,R163,R209,R221,R223,R224,R225,R226,R227,R229,R230,R231,R232,R233 |  | RES-0402 | C25741 | 0402WGF1003TCE | uni-royal(uniroyal elec) | 62.5mW Thick Film Resistors 50V ±100ppm/℃ ±1% 100kΩ 0402 Chip Resistor - Surface Mount ROHS | 4716586 | 402 | https://www.lcsc.com/datasheet/lcsc_datasheet_2206010100_UNI-ROYAL-Uniroyal-Elec-0402WGF1003TCE_C25741.pdf
0 | R142,R149,R150,R155,R166,R196,R247,R128,R129,R15,R18,R81,R87,R88,R89,R90 |  | RES-0402 | C17168 | 0402WGF0000TCE | uni-royal(uniroyal elec) | 62.5mW Thick Film Resistors 50V ±800ppm/℃ ±1% 0Ω 0402 Chip Resistor - Surface Mount ROHS | 7577882 | 402 | https://www.lcsc.com/datasheet/lcsc_datasheet_2206010216_UNI-ROYAL-Uniroyal-Elec-0402WGF0000TCE_C17168.pdf
10k | R161,R167,R148,R151,R173,R174,R175,R156,R186,R198,R125,R127,R130,R5,R27,R38,R78,R79,R80,R82,R83,R84,R85,R86,R91,R92,R121,R123,R212,R213,R214,R215,R216,R219,R220,R234,R239,R246 |  | RES-0402 | C25744 | 0402WGF1002TCE | uni-royal(uniroyal elec) | 62.5mW Thick Film Resistors 50V ±100ppm/℃ ±1% 10kΩ 0402 Chip Resistor - Surface Mount ROHS | 6952275 | 402 | https://www.lcsc.com/datasheet/lcsc_datasheet_2411221126_UNI-ROYAL-Uniroyal-Elec-0402WGF1002TCE_C25744.pdf
5.1k | R176,R152,R165,R182,R183,R217,R218,R235 |  | RES-0402 | C25905 | 0402WGF5101TCE | uni-royal(uniroyal elec) | 62.5mW Thick Film Resistors 50V ±100ppm/℃ ±1% 5.1kΩ 0402 Chip Resistor - Surface Mount ROHS | 5629675 | 402 | https://www.lcsc.com/datasheet/lcsc_datasheet_2206010045_UNI-ROYAL-Uniroyal-Elec-0402WGF5101TCE_C25905.pdf
357 | R185,R50 |  | RES-0402 | C423184 | 0402WGF3570TCE | uni-royal(uniroyal elec) | 62.5mW Thick Film Resistors 50V ±100ppm/℃ ±1% 357Ω 0402 Chip Resistor - Surface Mount ROHS | 424 | 402 | https://wmsc.lcsc.com/wmsc/upload/file/pdf/v2/lcsc/2205312216_UNI-ROYAL-Uniroyal-Elec-0402WGF3570TCE_C423184.pdf
39 | R187,R188,R194,R195,R184,R44,R45,R138,R139 |  | R0402 | C185420 | RC0402FR-0739RL | Yageo | 62.5mW Thick Film Resistors 50V ±100ppm/℃ ±1% 39Ω 0402 Chip Resistor - Surface Mount ROHS | 47658 | 402 | https://www.lcsc.com/datasheet/lcsc_datasheet_2304140030_YAGEO-RC0402FR-0739RL_C185420.pdf
NCP18WF104F03RC | R207 |  | R0603 | C13564 | NCP18XH103F03RB | Murata Electronics | 10kΩ 310uA 100mW ±1% 3380K ±1% 0603 NTC Thermistors ROHS | 57118 | 603 | https://www.lcsc.com/datasheet/lcsc_datasheet_1810311113_Murata-Electronics-NCP18XH103F03RB_C13564.pdf
1k | R208,R179,R180,R181,R197,R199,R200,R201,R162,R164,R171,R172,R178,R157,R140,R141,R143,R144,R145,R146,R147,R122,R124,R126,R236,R237,R238,R243,R244,R206,R6,R7,R8,R9,R10,R11,R12,R13,R14,R16,R22,R28,R29,R30,R32,R33,R34,R35,R36,R37,R40,R41,R46,R47,R48,R49,R51,R52,R53,R93,R202,R203 |  | 0402_RES | C11702 | 0402WGF1001TCE | uni-royal(uniroyal elec) | 62.5mW Thick Film Resistors 50V ±100ppm/℃ ±1% 1kΩ 0402 Chip Resistor - Surface Mount ROHS | 15329251 | 402 | https://www.lcsc.com/datasheet/lcsc_datasheet_2206010216_UNI-ROYAL-Uniroyal-Elec-0402WGF1001TCE_C11702.pdf
39k | R222 |  | RES-0402 | C25783 | 0402WGF3902TCE | uni-royal(uniroyal elec) | 62.5mW Thick Film Resistors 50V ±100ppm/℃ ±1% 39kΩ 0402 Chip Resistor - Surface Mount ROHS | 198842 | 402 | https://www.lcsc.com/datasheet/lcsc_datasheet_2206010100_UNI-ROYAL-Uniroyal-Elec-0402WGF3902TCE_C25783.pdf
56k | R228 |  | RES-0402 | C25796 | 0402WGF5602TCE | uni-royal(uniroyal elec) | 62.5mW Thick Film Resistors 50V ±100ppm/℃ ±1% 56kΩ 0402 Chip Resistor - Surface Mount ROHS | 312130 | 402 | https://www.lcsc.com/datasheet/lcsc_datasheet_2411221126_UNI-ROYAL-Uniroyal-Elec-0402WGF5602TCE_C25796.pdf
120 | R240,R241 |  | R0402 | C25079 | 0402WGF1200TCE | uni-royal(uniroyal elec) | 62.5mW Thick Film Resistors 50V ±100ppm/℃ ±1% 120Ω 0402 Chip Resistor - Surface Mount ROHS | 676145 | 402 | https://www.lcsc.com/datasheet/lcsc_datasheet_2205311900_UNI-ROYAL-Uniroyal-Elec-0402WGF1200TCE_C25079.pdf
1M | R42,R158,R204,R205 |  | RES-0402 | C26083 | 0402WGF1004TCE | uni-royal(uniroyal elec) | 62.5mW Thick Film Resistors 50V ±100ppm/℃ ±1% 1MΩ 0402 Chip Resistor - Surface Mount ROHS | 2377080 | 402 | https://www.lcsc.com/datasheet/lcsc_datasheet_2206010030_UNI-ROYAL-Uniroyal-Elec-0402WGF1004TCE_C26083.pdf
47 | R43,R168,R169,R170,R177,R242,R136,R31,R153,R154,R159,R210,R160 | R211 | RES-0402 | C25118 | 0402WGF470JTCE | uni-royal(uniroyal elec) | 62.5mW Thick Film Resistors 50V ±1% ±200ppm/℃ 47Ω 0402 Chip Resistor - Surface Mount ROHS | 740434 | 402 | https://www.lcsc.com/datasheet/lcsc_datasheet_2205311900_UNI-ROYAL-Uniroyal-Elec-0402WGF470JTCE_C25118.pdf
SKQGADE010 | SW3,SW4 |  | SW4-SMD-5.2X5.2X1.5MM | C116647 | SKQGADE010 | Alpsalpine | 5.2mm 1.5mm Round Button 50mA Standing paste 5.2mm SPST 12V SMD Tactile Switches ROHS | 23600 | SMD | https://www.lcsc.com/datasheet/lcsc_datasheet_1809200033_ALPSALPINE-SKQGADE010_C116647.pdf
WS2812-2020 | U1,U3 |  | LED_WS2812-2020 | C965555 | WS2812B-2020 | Worldsemi | SMD,2x2mm RGB LEDs(Built-in IC) ROHS | 260282 | SMD,2.2x2mm | https://www.lcsc.com/datasheet/lcsc_datasheet_2012110135_Worldsemi-WS2812B-2020_C965555.pdf
ADF4350BCPZ | U2 |  | QFN50P500X500X100-33V2N | C98705 | ADF4350BCPZ-RL7 | Analog Devices | 4.4GHz LFCSP-32(5x5) Clock Generators, PLLs, Frequency Synthesizers ROHS | 786 | LFCSP-32(5x5) | https://www.lcsc.com/datasheet/lcsc_datasheet_1809051230_Analog-Devices-ADF4350BCPZ-RL7_C98705.pdf
USBC | X1 |  | USB_C_CUSB31-CFM2AX-01-X | C5307756 | HC-TYPE-C-16P-CH3.18-3A-02 | Hctl | 3A USB 3.1 1 260℃@10S Horizontal attachment 16P Female -25℃~+85℃ Gold High conductivity copper Type-C SMD USB Connectors ROHS | 952 | SMD | https://wmsc.lcsc.com/wmsc/upload/file/pdf/v2/lcsc/2212071830_HCTL-HC-TYPE-C-16P-CH3-18-3A-02_C5307756.pdf
OSCILLATORSMD-5X3 | Y2 |  | OSCILLATOR-SMD-5X3.2 | C2901546 | SX5M50.000M20F30TNN | Shenzhen Sctf Elec | 1.62V~3.63V ±20ppm 20mA ±30ppm CMOS 50MHz SMD5032-4P Crystal Oscillators ROHS | 4634 | SMD5032-4P | https://wmsc.lcsc.com/wmsc/upload/file/pdf/v2/lcsc/2405241539_Shenzhen-SCTF-Elec-SX5M50-000M20F30TNN_C2901546.pdf
12MHz | Y3 |  | CRYSTAL-SMD-5X3 | C2901628 | SX5B12.000F1620F30 | Shenzhen Sctf Elec | 12MHz SMD crystal oscillator 16pF ±20ppm ±30ppm SMD5032-4P Crystals ROHS | 25 | SMD5032-4P | https://wmsc.lcsc.com/wmsc/upload/file/pdf/v2/lcsc/2406051021_Shenzhen-SCTF-Elec-SX5B12-000F1620F30_C2901628.pdf
Other parts | Quantity
ADC | 1 |  |  |  | ADC12DL2500 | Texas Instruments | 12-bit, dual 2.5GSPS or single 5GSPS analog-to-digital converter (LVDS interface) |  |  | https://www.ti.com/lit/gpn/adc12dl2500
BNC connector | 2 |  |  |  | 73100-0105 | Molex | BNC Jack, Right-Angle, PCB Receptacle, Die Cast Body, Nickel (Ni) Plated, Low Profile, Tray, 50 Ohms |  |  | https://www.molex.com/en-us/products/part-detail/731000105
Light pipe | 2 |  |  |  | SLP3-150-100-F | BIVAR | Light Pipes, Rigid Board Mount |  |  | https://www.bivar.com/product/slp3-150-100-f/
USB A connector | 2 |  |  |  | 292303-1 | TE Connectivity | A, 2.0, Standard Profile, Receptacle, 1 Port, Top, Right Angle, Box & Tube / Tube, Flush, Through Hole - Solder, Cable-to-Board, USB Connectors |  |  | https://www.te.com/en/product-292303-1.html
Ethernet connector | 2 |  |  |  | FRJAE-438 | Amphenol | Modular Jack - Right Angle, Input Output Connectors 8P8C, Shield, No Filter. |  |  | https://www.amphenol-cs.com/product/frjae438.html
Compensation tabs | 2 |  |  |  | 725996-2 | TE Connectivity | Tab, 2.79 mm [.11 in] Tab Width, 1.3 mm [.051 in] PCB Hole, Through Hole - Solder, Tin Plating, Box, FASTON 110, PCB Terminals |  |  | https://www.te.com/en/product-725996-2.html
Case | 1 |  |  |  | 1455R2201 | Hammond Mfg. | extruded aluminum enclosure w/ metal end panels 165 X 30.5 X 220MM ALM EXTRUSN |  |  | https://www.hawkusa.com/manufacturers/hammond-mfg/enclosures/box-metal/1455r2201
SMA edge connector | 3 |  |  | C496550 | BWSMA-KE-P001 | Bat Wireless | 1 Inner hole SMA Board-End Staggered pins 50Ω 5.2mm Plugin Coaxial Connectors (RF) ROHS |  |  | https://a.co/d/4B7CaRl
12V connector | 1 |  |  | C2961147 | PJ-002AH | Cui | Plugin DC Power Connectors ROHS |  |  | https://a.co/d/eoDnTFM
Fan 5V 40x40x10mm | 1 |  |  | https://a.co/d/87twmHs
Female JST fan connector | 1 |  |  | https://a.co/d/eWYJwHc
JTAG connector 2x5 | 1 |  |  | https://a.co/d/f5vxffH
Heatsink 20x20x10mm | 2 |  |  | https://a.co/d/1xYD7Q9
Thermal tape |  |  |  | https://a.co/d/dvBZmN2
Bubble wrap |  |  |  | https://a.co/d/7Qrm6s9
Box 12x8x2 | 1 |  |  | https://a.co/d/dbKtnco
USB A to C cable | 1 |  |  | https://a.co/d/j788qq6
Sticker for box | 1 |  |  | https://www.vistaprint.com/labels-stickers

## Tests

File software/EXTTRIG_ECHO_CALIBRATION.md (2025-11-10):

# External Trigger Echo Delay Calibration

## Overview

The Haasoscope Pro supports daisy-chaining multiple boards via LVDS connections. When multiple boards are synchronized, one board can generate triggers that propagate to other boards through the LVDS chain. However, LVDS signal propagation introduces delays that vary based on cable length and board position in the chain.

The **LVDS delay calibration** mechanism automatically measures and compensates for these trigger propagation delays, ensuring that waveforms from all boards are correctly time-aligned.

## Quick Start

**Automatic Calibration (Recommended):**

The system automatically performs LVDS calibration in these scenarios:

1. **Initial Setup**: After PLL reset completes during startup, calibration runs automatically for the initial trigger board
2. **Switching Trigger Sources**: When you set a different board to channel-based trigger (Rising/Falling Ch0 or Ch1), calibration runs automatically if no saved calibration exists for that trigger board
3. **Restoring Saved Calibrations**: When switching to a trigger board with existing calibration, the saved values are restored automatically

**To use:**
1. Start the application (PLL reset happens automatically)
2. Wait for initial LVDS calibration to complete (~5-50 acquisition cycles per board)
3. Switch trigger sources as needed - calibration is automatic!

**Manual Calibration:**

You can also manually trigger calibration via **Calibration → Board LVDS delays** menu.

**Important Notes:**
- Only one board can be self-triggering at a time (enforced automatically)
- Calibration runs asynchronously in the event loop (UI remains responsive)
- Each trigger source board has its own saved calibration set
- PLL resets are blocked during calibration to prevent interference
- Automatic calibration requires acquisition to be running (not paused)

## Architecture

### Event-Driven Calibration

The calibration system is **non-blocking** and runs asynchronously:

1. `calibrate_lvds_delays()` validates configuration and sets up state
2. Returns immediately to the UI
3. Calibration progresses in background via `_get_predata()` during normal acquisition
4. Each board is calibrated sequentially
5. Results are saved and firmware is updated when complete

State tracking in `scope_state.py`:
```python
self.lvds_calibration_active = False          # Whether calibration is running
self.lvds_calibration_boards = []             # Boards to calibrate
self.lvds_calibration_current_idx = 0         # Current board index
self.lvds_calibration_cycles = 0              # Cycles spent on current board
self.lvds_calibration_max_cycles = 50         # Timeout threshold
self.lvds_calibration_results = []            # Accumulated results
self.lvds_calibration_sets = {}               # Saved calibrations per trigger board
```

### Delay Compensation Split

Delay compensation is split between **firmware** and **software** for optimal precision:

**Firmware (send_trigger_info)** - Coarse 40-sample quantization:
```python
triggerpos += int(8 * lvdstrigdelay[board] / 40 / downsamplefactor / factor)
```
- Adjusts trigger position in 40-sample chunks
- Applied when trigger threshold/mode changes
- Limited precision but faster hardware response

**Software (data_processor.py)** - Fine sample-level residual:
```python
# Total correction needed (in full-rate ADC samples)
total_lvds_correction = 8 * lvdstrigdelay[board] / downsamplefactor

# What firmware already applied (in full-rate ADC samples, accounting for quantization and two-channel mode)
fw_lvds_correction = 40 * factor * int(8 * lvdstrigdelay[board] / 40 / downsamplefactor / factor)

# Software applies the fine residual (converted to per-channel samples for two-channel mode)
offset -= int((total_lvds_correction - fw_lvds_correction) / factor)
```
- `factor = 2` in two-channel mode (1.6 GHz per channel), `factor = 1` otherwise (3.2 GHz)
- Corrects for firmware quantization error
- Sample-level precision for perfect alignment
- Applied during waveform data processing

**Why split?**
- Firmware operates in fixed 40-sample windows
- Software can adjust per-sample for fine alignment
- Combined approach gives best of both: fast firmware response + precise software correction

### Saved Calibrations

Calibrations are **saved per trigger source board**:

```python
state.lvds_calibration_sets = {
    0: {1: 4.5, 2: 9.2, 3: 13.8},  # When Board 0 is trigger source
    1: {0: 3.8, 2: 4.6, 3: 9.1},   # When Board 1 is trigger source
    2: {0: 8.9, 1: 4.2, 3: 4.7},   # When Board 2 is trigger source
}
```

When you switch trigger sources (by setting a different board to channel-based triggering):
1. All other boards are automatically set to external trigger
2. Previously saved calibration for that trigger board is restored
3. If no saved calibration exists, automatic calibration starts (if acquisition is running)
4. Firmware trigger positions are updated

## Hardware Topology

Boards are connected in a daisy-chain configuration:

```
Board 0 <--LVDS--> Board 1 <--LVDS--> Board 2 <--LVDS--> Board N-1
```

Key signals transmitted over LVDS between boards:
- **lvdsout_trig** / **lvdsin_trig**: Forward trigger signal (board i → board i+1)
- **lvdsout_trig_b** / **lvdsin_trig_b**: Backward trigger signal (board i → board i-1)
- **clkout** / **clkin**: Clock synchronization

The trigger signals can propagate in both directions:
- **Forward**: From lower-indexed board to higher-indexed board
- **Backward**: From higher-indexed board to lower-indexed board (includes tuning factor)

## Firmware Components

### Phase Difference Registers

The firmware tracks trigger signal timing using phase counters:

- **`phase_diff`** (16-bit): Measures timing of forward trigger signal (lvdsin_trig)
- **`phase_diff_b`** (16-bit): Measures timing of backward trigger signal (lvdsin_trig_b)

Read via commands in `command_processor.v`:
- **Command 2, Subcommand 12**: Returns `phase_diff`
- **Command 2, Subcommand 13**: Returns `phase_diff_b`

The firmware returns the phase measurement in bytes `res[0]` and `res[1]`. Consistent values (res[0] == res[1]) indicate stable phase alignment.

### Trigger Types

- **Type 3**: External trigger mode - board waits for LVDS trigger input
- **Type 30**: External trigger **echo** mode - enables phase measurement during calibration

## Software Components

### Key Functions

**`calibrate_lvds_delays()`** (`hardware_controller.py:571-658`)
- Validates exactly one self-triggering board
- Sets up calibration state and enables echo mode for first board
- Returns immediately (non-blocking)
- Calibration proceeds asynchronously in event loop

**`_get_predata(board_idx)`** (`hardware_controller.py:451-557`)
- Called during each acquisition cycle
- Contains echo delay measurement logic
- Progresses through calibration boards sequentially
- Handles timeout and completion

**`_finish_lvds_calibration()`** (`hardware_controller.py:630-661`)
- Applies ~16ns board offset correction
- Saves calibration set indexed by trigger source board
- Updates firmware trigger positions

**`restore_lvds_calibration(trigger_board)`** (`hardware_controller.py:663-692`)
- Restores previously saved calibration
- Called automatically when switching trigger sources
- Updates firmware if calibration exists

## Calibration Algorithm

### Two Boards Example

**Configuration**: Board 0 generates triggers → Board 1 receives triggers

```
Board 0 (self-triggering)     Board 1 (ext trigger)
doexttrig[0] = False           doexttrig[1] = True
triggertype = 0-2              triggertype = 30 (during calibration)
```

**Process:**

1. User selects **Calibration → Board LVDS delays**
2. `calibrate_lvds_delays()` validates and enables echo mode for Board 1
3. During acquisition, `_get_predata(0)` on Board 0:
   - Detects `doexttrigecho[1] == True`
   - Since Board 1 > Board 0: **Forward echo**
   - Sends Command `[2, 12]` to read `phase_diff`
4. Firmware returns phase measurement in `res[0]` and `res[1]`
5. Calculate delay:
   ```python
   if res[0] == res[1]:  # Phase is stable
       lvdstrigdelay = (res[0] + res[1]) / 4  # LVDS cycles
   ```
6. Stability check - if consistent with last measurement:
   - Store `lvdstrigdelay[1]`
   - Disable echo mode
   - Apply ~16ns offset: `lvdstrigdelay[1] -= 16/2.5`
7. Save calibration set for trigger Board 0
8. Update firmware trigger positions

### Three Boards Example

**Configuration**: Board 1 generates triggers → Boards 0 and 2 receive triggers

```
Board 0 (ext trig)    Board 1 (self-trig)    Board 2 (ext trig)
doexttrig[0] = True   doexttrig[1] = False   doexttrig[2] = True
```

**Calibration sequence:**

1. **Board 0 (Backward echo)**:
   - Enable `doexttrigecho[0] = True`
   - Board 1 sends Command `[2, 13]` to read `phase_diff_b`
   - Calculate: `lvdstrigdelay = (res[0] + res[1]) / 4`
   - **Apply backward tuning**: `lvdstrigdelay += round(lvdstrigdelay / 11.5, 1)`
   - Apply offset correction

2. **Board 2 (Forward echo)**:
   - Enable `doexttrigecho[2] = True`
   - Board 1 sends Command `[2, 12]` to read `phase_diff`
   - Calculate: `lvdstrigdelay = (res[0] + res[1]) / 4`
   - No backward tuning needed
   - Apply offset correction

3. Save both delays under trigger source Board 1

### Multi-Hop Delays

The echo signal physically travels through all intermediate boards:

**Example**: 4 boards with Board 1 as trigger source

```
Board 0 ← Board 1 → Board 2 → Board 3
```

- **Board 0 delay**: 1-hop backward through cable
- **Board 2 delay**: 1-hop forward through cable
- **Board 3 delay**: 2-hop forward (Board 1 → Board 2 → Board 3)
  - Includes Board 2 internal routing + both cables
  - Approximately 2× single-hop delay

The `phase_diff` measurement captures the **total multi-hop echo time**.

## Board Offset Correction

A ~16ns (~6.4 LVDS cycles) correction is applied to all ext-trig boards:

```python
for board in range(num_board):
    if doexttrig[board]:
        lvdstrigdelay[board] -= 16 / 2.5  # 16ns / 2.5ns per cycle
```

This compensates for systematic timing offsets in the trigger path.

## Physical Interpretation

Delays are measured in **LVDS clock cycles** (400 MHz = 2.5 ns/cycle):

| LVDS Cycles | Time (ns) | Samples @ 3.2 GHz |
|---|---|---|
| 1.0 | 2.5 | 8 |
| 4.5 | 11.25 | 36 |
| 6.4 | 16.0 | 51 |
| 10.0 | 25.0 | 80 |

**Conversion factor**: 8 samples per LVDS cycle (3.2 GHz / 400 MHz = 8)

## Safety Features

### Single Self-Triggering Board

The system enforces **exactly one self-triggering board**:

```python
# In rising_falling_changed() - main_window.py:3504-3514
if not is_other_boards and not is_external_sma:
    for board_idx in range(num_board):
        if board_idx != active_board and not doexttrig[board_idx]:
            doexttrig[board_idx] = True  # Force to ext trigger
            set_exttrig(board_idx, True)

    # Restore saved calibration for this trigger board
    restore_lvds_calibration(active_board)
```

When you set a board to channel-based triggering, all other boards are automatically switched to external trigger mode.

### PLL Reset Prevention

Automatic PLL resets are blocked during calibration:

```python
# In update_plot_event() - main_window.py:1132-1134
elif s.lvds_calibration_active:
    # Don't trigger PLL resets during LVDS calibration
    pass
```

This prevents interruption of the calibration process by transient clock issues.

### External Clock Lock Verification

After PLL reset completes, all ext-trig boards are verified to be locked to external clock:

```python
# In adjustclocks() - hardware_controller.py:209-212
if all(x == -10 for x in plljustreset):
    ensure_boards_locked()  # Check sequentially board 1→N
```

## Timing Behavior

### Calibration Duration

- **Per board**: 5-50 acquisition cycles (typically ~10 cycles)
- **4 boards**: ~30-150 total cycles
- **At 1 kHz trigger rate**: 30-150 ms total

### Firmware Update Timing

Firmware trigger positions are updated:
1. After LVDS calibration completes
2. When downsample factor changes
3. When trigger mode changes

Call to `send_trigger_info()` updates the hardware immediately.

## Troubleshooting

### Calibration Times Out

**Symptoms**: "Board X: Calibration timed out after 50 cycles"

**Causes**:
- Phase measurements not stabilizing (res[0] != res[1])
- LVDS clock phase misalignment
- Cable connection issues

**Solutions**:
- Check LVDS cable connections
- Run PLL calibration first
- Verify external clock lock on all boards

### Waveforms Not Aligned After Calibration

**Check**:
1. Calibration completed successfully (no timeout messages)
2. Trigger threshold is stable (not changing during measurement)
3. Firmware trigger positions updated (check console for "Updating firmware trigger positions")
4. Downsample factor hasn't changed since calibration

**Debug**:
- Re-run calibration
- Check `lvdstrigdelay` values in state
- Verify both firmware and software compensation are active

### Switching Trigger Sources

When switching which board generates triggers:

1. Select the new trigger board in UI
2. Set it to channel-based trigger (Rising/Falling Ch0 or Ch1)
3. System automatically:
   - Sets all other boards to external trigger
   - Restores saved calibration for that trigger board (if exists)
   - **Starts automatic calibration** if no saved calibration exists (requires acquisition running)
   - Updates firmware trigger positions

You can also manually trigger calibration via **Calibration → Board LVDS delays** menu.

## Implementation Details

### Conversion Constants

```python
LVDS_FREQ = 400e6          # 400 MHz LVDS clock
ADC_FREQ = 3.2e9           # 3.2 GHz ADC sampling
SAMPLES_PER_LVDS = 8       # ADC_FREQ / LVDS_FREQ
NS_PER_LVDS = 2.5          # 1/LVDS_FREQ * 1e9
```

### Firmware Trigger Position Quantization

Firmware operates in **40-sample windows**:
```python
triggerpos_increment = int(8 * lvdstrigdelay / 40 / downsamplefactor / factor)
actual_samples = triggerpos_increment * 40 * factor
```

Residual correction in software ensures sample-level precision.

### Backward Echo Tuning Factor

The `11.5` tuning factor for backward echo:
```python
if echoboard < board_idx:  # Backward direction
    lvdstrigdelay += round(lvdstrigdelay / 11.5, 1)
```

This empirical correction accounts for asymmetries in the backward signal path timing. The exact value may need adjustment for different hardware configurations.

## API Reference

### State Variables

```python
state.doexttrig[board]              # True if board uses external trigger
state.doexttrigecho[board]          # True if board is in echo mode (calibration)
state.lvdstrigdelay[board]          # Measured delay in LVDS cycles
state.lvds_calibration_active       # True during active calibration
state.lvds_calibration_sets[trig_board][board]  # Saved delays per trigger source
```

### Functions

```python
controller.calibrate_lvds_delays()
# Start LVDS calibration (non-blocking)
# Returns: (success: bool, message: str)

controller.restore_lvds_calibration(trigger_board)
# Restore saved calibration for trigger_board
# Returns: bool (True if calibration restored)

controller.send_trigger_info(board)
# Update firmware trigger position for board
# Includes LVDS delay compensation

controller.ensure_boards_locked()
# Verify all ext-trig boards locked to external clock
# Called after PLL reset
```

## Version History

- **v32**: Event-driven calibration, firmware/software split compensation, saved calibrations per trigger board, automatic calibration on startup and when switching trigger sources, fixed board processing order for distcorr stabilization
- **v31**: Menu-based calibration only (removed automatic calibration)
- **v30**: Multi-board systematic calibration
- **v29**: Initial doexttrigecho implementation

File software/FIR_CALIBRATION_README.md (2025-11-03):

# FIR Frequency Response Calibration

## Overview

This feature corrects for the non-flat frequency response of the Haasoscope Pro hardware by applying a calibrated FIR (Finite Impulse Response) filter to measured waveforms. The calibration is based on a known 10 MHz square wave input signal.

## How It Works

1. **Calibration Signal**: Uses a 10 MHz square wave as reference
2. **Measurement**: Captures and averages 1000 waveforms to reduce noise
3. **Analysis**: Computes frequency response H(f) = FFT(measured) / FFT(ideal)
4. **Filter Design**: Creates an adaptive FIR filter (32/64/128 taps based on sample rate) to invert the frequency response
5. **Application**: Applies the filter in real-time using zero-phase filtering (same as LPF)

**Key Features**:
- **Adaptive tap count**: Automatically selects 32/64/128 taps based on sample rate for consistent ~50 MHz frequency resolution
- **Robust to imperfect signals**: Measures actual duty cycle, frequency, and removes DC offset
- **SNR-based harmonic selection**: Uses 100x noise floor threshold for reliable measurements
- **Over-correction prevention**: Limits to ±6 dB magnitude and ±25° phase corrections
- **Hardware LPF aware**: Respects hardware anti-alias filter cutoffs (700/1400/2500 MHz depending on mode)

## Pipeline Integration

The FIR correction is applied in the waveform processing pipeline at this location:

```
Hardware → DataProcessor (unpack, scale, LPF)
    → Board Trigger Stabilizer
    → PlotManager → Extra Trigger Stabilizer
    → Time Skew Correction
    → **FIR Frequency Response Correction** ← NEW
    → Display
```

This ensures corrections are applied after trigger stabilization but before display.

## Usage Instructions

### Operating Modes: Normal, Two-Channel, Oversampling, and Interleaved

The FIR calibration system automatically detects the current operating mode and applies the appropriate calibration:

- **Normal Mode**: Single calibration applies to all boards/channels at base sample rate (3.2 GHz)

- **Two-Channel Mode**: Single calibration for dual-channel acquisition at half sample rate (1.6 GHz per channel)
  - Determined by checking `state.dotwochannel[activeboard]`
  - Sample rate per channel is halved (1.6 GHz instead of 3.2 GHz)
  - Both channels share the same hardware path, so one calibration applies to both
  - Calibration is performed on the active channel (whichever channel is currently selected)
  - Correction is automatically applied to both channels during acquisition

- **Oversampling Mode** (not interleaved): Board pair (N and N+1) are calibrated separately at base sample rate
  - Determined by checking `state.dooversample[activeboard]`
  - Board N and Board N+1 each get independent FIR coefficients
  - Hardware duplicates the 10 MHz signal to both boards automatically
  - Both boards are calibrated simultaneously from the same capture session
  - Corrections are automatically applied per-board during acquisition

- **Interleaved Oversampling Mode** (both oversampling AND interleaving enabled): Interleaved waveform calibrated at 2x sample rate (6.4 GHz)
  - Determined by checking both `state.dooversample[activeboard]` and `state.dointerleaved[activeboard]`
  - Single calibration for the interleaved waveform combining both boards
  - Sample rate is 2x the base rate (6.4 GHz instead of 3.2 GHz)
  - Captures both boards simultaneously and interleaves them during calibration
  - Hardware automatically duplicates the 10 MHz signal to both boards
  - Correction is applied to the already-interleaved waveform during plotting

### 1. Connect Calibration Signal
- Connect a **10 MHz square wave** to the input
- **Normal Mode**: Signal goes to Board 0, Channel 0
- **Two-Channel Mode**: Signal goes to the **active channel** (whichever channel is currently selected)
  - Both channels share the same hardware path
  - The calibration applies to both channels automatically
  - The dialog will tell you which channel to connect to (e.g., "Connect to CH1" or "Connect to CH2")
- **Oversampling Mode** (not interleaved): Hardware automatically duplicates signal to both Board N and Board N+1
  - Both boards are calibrated separately but simultaneously from the same signal
  - No need to move the signal between boards
- **Interleaved Mode**: Hardware automatically duplicates signal to both Board N and Board N+1
  - The interleaved waveform at 6.4 GHz is calibrated as a single entity
  - Both boards contribute to the same calibration
- The signal should have good amplitude and clean edges
- Ensure the scope is triggered and acquiring stable waveforms

### 2. Set Maximum Sample Rate
- **IMPORTANT**: Set **Downsample to 0** (maximum sample rate) before calibration
- Calibration must be performed at maximum sample rate for best results
- After calibration, corrections can be used at downsampled rates (though with reduced accuracy)
- **Depth**: The software automatically increases depth to 1000 samples during calibration for optimal frequency resolution
  - Your current depth setting is temporarily changed and then restored
  - This gives the finest possible frequency resolution (Δf = sample_rate / 1000)
  - After calibration, you can use any depth - the FIR filter works identically at all depths

### 3. Capture Calibration
- Start acquisition (unpause the scope)
- Go to menu: **Calibration → Measure 10 MHz square FIR**
- If downsample > 0, you'll get a warning to set it to 0 first
- The software will:
  - Capture 50 waveforms (takes ~1-2 seconds)
  - Average them to reduce noise
  - Compute the frequency response
  - Design the 64-tap FIR correction filter
  - Display a success message with improvement in dB

### 4. Apply Correction
- The correction is automatically enabled after successful calibration
- You can toggle it on/off using: **Calibration → Apply FIR corrections** (checkbox)
- The correction applies to **all channels** (not per-channel)

### 5. Verify Results
- View the corrected waveforms
- The 10 MHz square wave should now have better-defined edges and harmonics
- You can toggle the correction on/off to see the difference

### 6. Save/Load Calibration
- Calibration data is saved to **separate .fir files** (not in the main setup file)
- Use: **Calibration → Save FIR filter** to export calibration to a file
- Use: **Calibration → Load FIR filter** to import calibration from a file
- **Calibration Storage**:
  - A single .fir file can contain **all four** calibration types: normal, two-channel, oversampling, and interleaved
  - When saving: All available calibrations are saved to the same file
  - When loading: Software automatically detects which calibrations are present and loads them
  - The appropriate calibration is selected automatically based on current mode during acquisition
- The saved .fir file (JSON format) contains:
  - **Normal Mode data** (if calibrated): FIR coefficients (64-256 taps), sample rate (3.2 GHz), frequency response, metadata
  - **Two-Channel Mode data** (if calibrated): FIR coefficients, sample rate (1.6 GHz per channel), frequency response, metadata
  - **Oversampling Mode data** (if calibrated): Two sets of FIR coefficients (one per board), sample rates (3.2 GHz each), frequency responses, metadata
  - **Interleaved Mode data** (if calibrated): FIR coefficients, sample rate (6.4 GHz), frequency response, metadata
- **Sample rate validation**: When loading, the software checks if the base sample rate matches
- **Downsample handling**:
  - Calibration must be done at downsample=0 (maximum sample rate)
  - The calibration can be used at downsampled rates (downsample>0)
  - When loading at downsample>0, you'll be informed that accuracy may be reduced
  - For best results, use downsample=0 when applying corrections
- **Note**: Calibration is specific to the hardware's base sample rate. Different hardware units need separate calibrations
- **Recommended workflow**:
  1. Connect 10 MHz square wave to input
  2. Calibrate in normal mode (no oversampling, no interleaving, single channel)
  3. Save calibration file
  4. Enable two-channel mode
  5. Run calibration again (will calibrate at 1.6 GHz per channel)
  6. Save again (same file now contains both normal and two-channel calibrations)
  7. Disable two-channel mode, enable oversampling on active board (without interleaving)
  8. Run calibration again (will calibrate both boards in pair simultaneously)
  9. Save again (same file now contains normal, two-channel, and oversampling calibrations)
  10. Enable both oversampling AND interleaving on active board
  11. Run calibration again (will calibrate interleaved waveform at 6.4 GHz)
  12. Save again (same file now contains all four calibration types: normal, two-channel, oversampling, and interleaved)

## Technical Details

### FIR Filter Specifications
- **Number of taps**: **Automatically scaled based on sample rate** for consistent ~50 MHz frequency resolution
  - **Two-channel mode** (1.6 GHz): **32 taps** → Δf ≈ 50 MHz
  - **Normal/Oversampling mode** (3.2 GHz): **64 taps** → Δf ≈ 50 MHz
  - **Interleaved mode** (6.4 GHz): **128 taps** → Δf ≈ 50 MHz
  - This scaling maintains consistent filter quality while minimizing computation at lower sample rates
- **Window**: Blackman window (reduces ringing)
- **Filter method**: `scipy.signal.filtfilt` (zero-phase, no time delay)
- **Regularization**: 0.001 (small epsilon to prevent division by zero, not aggressive damping)
- **Max magnitude correction**: ±6 dB (prevents excessive boost/cut and over-correction artifacts)
- **Max phase correction**: ±25 degrees (prevents phase artifacts)
- **Median filter size**: 10 (smooths correction values to remove outliers)
- **SNR threshold**: 100x local noise floor (ensures reliable harmonic detection)
- **Number of averages**: 1000 waveforms (reduces noise for accurate measurements)
- **Progress reporting**: Prints at 10% intervals during calibration
- **Diagnostic output**: Reports bins with large corrections (>3 dB or >12.5 degrees)

### Sample Rate Handling
- Calibration is performed at the **current sample rate** (at downsample=0)
  - **Normal mode**: 3.2 GHz (base sample rate)
  - **Two-channel mode**: 1.6 GHz per channel (half of base sample rate)
  - **Oversampling mode** (not interleaved): 3.2 GHz per board
  - **Interleaved mode**: 6.4 GHz (2x base sample rate)
- The filter is stored with the sample rate it was calibrated at
- **Important**: If you change base sample rates, you should re-run calibration
- Can be used at different downsample settings (with reduced accuracy)

### Hardware LPF Cutoff Limits
The hardware has different anti-alias low-pass filters in each mode. The calibration automatically detects the mode and only corrects frequencies below the hardware cutoff:

| Mode | Sample Rate | Hardware LPF Cutoff | Max Correction Frequency |
|---|---|---|---|
| Two-channel | 1.6 GHz | 700 MHz | 700 MHz |
| Normal | 3.2 GHz | 1400 MHz | 1400 MHz |
| Oversampling/Interleaved | 3.2/6.4 GHz | 2500 MHz | 2500 MHz |

**Why this matters**:
- Frequencies above the hardware cutoff are already attenuated by the anti-alias filter
- Attempting to correct them would just amplify noise in those bands
- The calibration prints the detected mode and max correction frequency during operation
- For a 10 MHz square wave:
  - Two-channel: Uses harmonics up to 700 MHz (70th harmonic)
  - Normal: Uses harmonics up to 1400 MHz (140th harmonic)
  - Oversampling/Interleaved: Uses harmonics up to 2500 MHz (250th harmonic)

### Depth (Sample Count) and Windowing
- **Automatic depth optimization during calibration**: Software temporarily sets depth to 640 samples
  - Chosen so 10 MHz harmonics land exactly on FFT bin centers (avoids spectral leakage)
  - FFT bin spacing:
    - Two-channel: Δf = 1.6 GHz / 640 = 2.5 MHz → harmonics at bins 4, 8, 12, 16...
    - Normal/Oversampling: Δf = 3.2 GHz / 640 = 5 MHz → harmonics at bins 2, 6, 10, 14...
    - Interleaved: Δf = 6.4 GHz / 640 = 10 MHz → harmonics at bins 1, 3, 5, 7...
  - This ensures accurate measurement of harmonic amplitudes without leakage between bins
  - After calibration completes, original depth is restored automatically
- **FIR filter is depth-independent**: Works identically at any depth
  - During calibration: depth affects frequency resolution of H(f) measurement
  - After calibration: freely change depth - correction applies the same way
  - **Why**: FIR filtering is sample-by-sample convolution, not dependent on signal length

### Performance
- FIR filtering uses `filtfilt` (forward-backward filtering)
- Same infrastructure as existing LPF, so minimal performance impact
- **Adaptive tap count** optimizes performance:
  - Two-channel (32 taps): ~32,000 multiplies per 1000 samples → **fastest**
  - Normal/Oversample (64 taps): ~64,000 multiplies per 1000 samples → **moderate**
  - Interleaved (128 taps): ~128,000 multiplies per 1000 samples → **slower but higher bandwidth**
- Typical overhead: ~10-20% increase in processing time per waveform
- The tap count scaling ensures computational cost scales appropriately with data rate

### Square Wave Calibration Coverage
- **Imperfect Square Wave Handling**:
  - The calibration automatically measures the actual duty cycle of the input square wave
  - Generates an ideal reference with the same duty cycle for comparison
  - Measures the actual fundamental frequency (may not be exactly 10 MHz)
  - Removes DC offset from averaged waveforms before processing
  - This allows calibration to work even with non-ideal square wave inputs
- **Harmonic Selection**:
  - Uses both odd AND even harmonics (10, 20, 30, 40... MHz) for better frequency coverage
  - Measures local noise floor in ±250 MHz window around each harmonic
  - Only uses harmonics with SNR > 100x local noise floor
  - Excludes ±2.5 MHz around each harmonic from noise estimation
  - Applies median filtering (window size 10) to remove outlier corrections
  - Limits magnitude correction to ±6 dB and phase correction to ±25 degrees
  - Typical result: 100-250 valid harmonics measured (depending on signal quality)
- **Hardware LPF cutoff limits**:
  - Calibration respects hardware anti-alias filter cutoffs for each mode
  - **Two-channel mode (1.6 GHz)**: Corrects up to **700 MHz** (hardware has 700 MHz LPF)
  - **Normal mode (3.2 GHz)**: Corrects up to **1400 MHz** (hardware has 1400 MHz LPF)
  - **Oversampling/Interleaved mode (6.4 GHz)**: Corrects up to **2500 MHz** (hardware has 2500 MHz LPF)
  - Frequencies above the hardware cutoff are already attenuated by the anti-alias filter
  - No point correcting frequencies that the hardware has already filtered out
- The FIR filter interpolates smoothly between measured harmonics
- This provides correction across the usable hardware bandwidth

### Calibration Quality
- The calibration quality depends on:
  - Signal-to-noise ratio of input square wave
  - Stability of trigger (use trigger stabilizers)
  - Number of averages (default: 1000)
  - Cleanliness of square wave edges
- **New features for robust calibration**:
  - Automatic duty cycle measurement handles non-50% duty cycle square waves
  - Automatic frequency measurement handles reference signals that aren't exactly 10 MHz
  - DC offset removal ensures accurate baseline
  - SNR-based harmonic selection ignores noisy frequency bins
  - Median filtering removes outlier corrections
  - Magnitude and phase correction limits prevent over-correction artifacts
- The success message shows improvement in dB (typically 3-10 dB for hardware with already-flat response)
- **Note**: If your hardware already has good frequency response (H(f) ≈ 1.0 at most frequencies), improvement will be modest. This is actually a good sign!
- **Progress tracking**: During calibration, progress is printed at 10% intervals, and bins with large corrections are reported for diagnostic purposes

## File Format (.fir)

FIR calibration files use JSON format with the following structure:

```json
{
  "fir_coefficients": [0.0123, 0.0234, ... 32/64/128 values],
  "calibration_samplerate_hz": 3200000000.0,
  "calibration_downsample": 0,
  "num_taps": 64,  // Automatically determined: 32 (two-channel), 64 (normal), 128 (interleaved)
  "calibration_type": "10MHz_square_wave",
  "software_version": 31.08,
  "frequency_response": {
    "freqs": [0, 1e6, 2e6, ... frequency bins in Hz],
    "magnitude": [1.0, 0.98, ... magnitude at each frequency],
    "phase": [0.0, -0.01, ... phase in radians]
  }
}
```

**File Size:** ~10-20 KB per .fir file (varies with tap count)

## Files Modified/Created

### New Files
- `frequency_calibration.py` - Core calibration logic, FIR filter design, save/load functions

### Modified Files
- `scope_state.py` - Added FIR calibration state variables (lines 114-118)
- `plot_manager.py` - Added FIR filter application (lines 437-441)
- `main_window.py` - Added handlers and calibration capture (lines 521-637)
- `HaasoscopePro.ui` - UI actions for measure, apply, save, load (lines 2357-2360, 2994-3021)

## State Variables

The calibration state is stored in `ScopeState`:

```python
# Global enable/disable
state.fir_correction_enabled          # bool: Enable/disable correction

# Normal mode (3.2 GHz)
state.fir_coefficients                # np.array: FIR filter coefficients
state.fir_calibration_samplerate      # float: Sample rate during calibration (Hz)
state.fir_freq_response              # dict: Measured H(f) for display/analysis

# Two-channel mode (1.6 GHz per channel)
state.fir_coefficients_twochannel           # np.array: FIR filter coefficients
state.fir_calibration_samplerate_twochannel # float: Sample rate during calibration
state.fir_freq_response_twochannel          # dict: Measured H(f)

# Oversampling mode (3.2 GHz per board)
state.fir_coefficients_oversample           # list[2]: [board_N, board_N+1]
state.fir_calibration_samplerate_oversample # list[2]: Sample rates
state.fir_freq_response_oversample          # list[2]: Measured H(f)

# Interleaved mode (6.4 GHz)
state.fir_coefficients_interleaved           # np.array: FIR filter coefficients
state.fir_calibration_samplerate_interleaved # float: Sample rate during calibration
state.fir_freq_response_interleaved          # dict: Measured H(f)
```

## Future Enhancements

1. **Per-channel calibration**: Currently applies same correction to all channels
2. **Chirp calibration**: Use frequency sweep for continuous coverage
3. **Display H(f)**: Show frequency response plot in a dialog
4. **Auto-detect sample rate change during session**: Warn if sample rate changed after calibration was performed
5. **Multi-frequency calibration**: Use 1 MHz, 5 MHz, 10 MHz, 20 MHz square waves
6. **Calibration validation**: Show before/after FFT comparison in a dialog
7. **Calibration library**: Manage multiple calibrations for different sample rates in one place

## Troubleshooting

**"No calibration data available"**
- Run "Measure 10 MHz square FIR" first with a 10 MHz square wave connected

**"FIR calibration must be performed at maximum sample rate"**
- Set Downsample to 0 before running calibration
- The downsample control should show 0 (no downsampling)
- After calibration, you can use any downsample setting, but accuracy is best at downsample=0

**"Only captured N waveforms"**
- Ensure scope is acquiring (not paused)
- Check that trigger is stable
- Verify signal is connected to Channel 0

**Poor calibration results**
- Improve signal quality (cleaner square wave)
- Enable trigger stabilizers for better alignment
- Increase number of averages in `frequency_calibration.py` (line 12)
- Check that signal frequency is exactly 10 MHz

**Correction makes signal worse**
- Input signal may not be a 10 MHz square wave
- Re-run calibration with correct signal
- Try disabling "Apply FIR corrections" and verify input signal is correct

**Very small improvement (< 1 dB)**
- This is often **normal and good** - it means your hardware already has flat frequency response!
- Check the diagnostic output: if H(f) magnitude ≈ 1.0 at most frequencies, hardware is working well
- Example: H(f) = 1.01 at 10 MHz means only 1% deviation (excellent)
- Corrections will be subtle but still improve edges at frequencies that need it
- If H(f) shows large deviations (e.g., 0.5 or 2.0) but improvement is still small:
  - Check that signal is a clean 10 MHz square wave
  - Verify trigger is stable (use trigger stabilizers)
  - Ensure sufficient signal amplitude and SNR
  - Try increasing number of taps to 128 or 256 (see main_window.py line 554)
    - More taps = better frequency resolution and smoother corrections
    - Especially helpful if you have sharp frequency response variations

**"Sample Rate Mismatch" warning when loading**
- Calibration was performed at a different base sample rate
- The FIR filter's frequency response is scaled by sample rate ratio
- Options:
  1. Click "No" and re-calibrate at current sample rate
  2. Click "Yes" to use anyway (not recommended - may be inaccurate)
  3. Change scope sample rate to match calibration
- Best practice: Keep separate .fir files for each base sample rate

**"Invalid FIR filter file" error**
- File is corrupted or not a valid .fir file
- Check file format (should be JSON with required fields)
- Try re-saving the calibration

**File dialog cancellation**
- No error occurs if you cancel the save/load dialog
- Simply try again when ready

## Example Workflow

### Initial Calibration:
```
1. User connects 10 MHz square wave to scope
2. User sets Downsample = 0 (maximum sample rate)
3. User starts acquisition and verifies stable trigger
4. User clicks: Calibration → Measure 10 MHz square FIR
   → Software captures 50 waveforms
   → Computes H(f) and designs FIR filter
   → Shows "Calibration successful. Improvement: 15.3 dB"
5. Correction is automatically applied
6. User clicks: Calibration → Save FIR filter
   → Saves to "haasoscope_3.2GHz_DS0.fir"
7. All subsequent waveforms are corrected in real-time
```

### Later Session at Max Rate:
```
1. User starts software at same sample rate (3.2 GS/s, downsample=0)
2. User clicks: Calibration → Load FIR filter
   → Selects "haasoscope_3.2GHz_DS0.fir"
   → Software validates sample rate matches
   → Correction enabled automatically
3. Waveforms now use pre-calibrated correction
```

### Using at Downsampled Rate:
```
1. User has calibration from max rate (downsample=0)
2. User sets Downsample = 2 (slower acquisition for longer time window)
3. User clicks: Calibration → Load FIR filter
   → Selects "haasoscope_3.2GHz_DS0.fir"
   → ℹ️ Info: "Calibration was at downsample=0, you are at downsample=2"
   → Correction enabled with reduced accuracy warning
4. Correction still works, but accuracy may be reduced
   For best results, use downsample=0
```

### Different Base Sample Rate:
```
1. User changes hardware to different base sample rate
2. User clicks: Calibration → Load FIR filter
   → Selects "haasoscope_3.2GHz_DS0.fir"
   → ⚠️ Warning: "Sample rate mismatch"
   → User clicks "No" to re-calibrate
3. User sets downsample=0 and re-runs: Calibration → Measure 10 MHz square FIR
4. User saves new calibration as "haasoscope_1.6GHz_DS0.fir"
```

## Algorithm Details

### Phase Alignment
1. Average 200 captured waveforms to reduce noise
2. Estimate initial phase using first zero crossing
3. Generate ideal square wave with estimated phase
4. Fine-tune alignment using cross-correlation
5. Ensures measured and ideal waveforms are time-aligned

### Amplitude Normalization
- Normalize measured signal to match ideal signal's RMS amplitude
- This separates overall gain from frequency-dependent response
- The FIR filter then corrects only frequency response, preserving input signal amplitude
- **Critical**: Without this step, the filter would include overall gain correction
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

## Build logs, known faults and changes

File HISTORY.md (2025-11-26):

# The Development History of the Haasoscope Pro

## A Story of Building a High-Speed Scientific Instrument

### The Beginning

On July 25, 2024, the first lines of code were committed to what would become the Haasoscope Pro project. This marked the beginning of an ambitious sixteen-month journey to create a professional-grade oscilloscope—an instrument that captures and displays electrical signals—capable of measuring phenomena occurring billions of times per second. The project was the work of Andy Haas, building on experience from earlier oscilloscope designs.

The earliest days were spent establishing the fundamental communication between a computer and the custom circuit board. By the end of July, the system could reliably send and receive data through a high-speed USB connection. This may seem like a modest achievement, but it represented the critical foundation upon which everything else would be built. Without reliable communication, no amount of sophisticated signal processing would matter.

### First Light

The first real breakthrough came on July 31, 2024, when the system successfully captured an analog signal at 500 million samples per second. This moment—when the oscilloscope first "saw" a real electrical waveform—is sometimes called "first light," borrowing terminology from telescope builders who use the phrase to describe the first time a new instrument captures an image of the sky.

Within a week, a graphical display was operational, allowing the captured waveforms to be visualized on a computer screen. The ability to see the signals in real time transformed the development process. Debugging became dramatically easier when problems could be observed directly rather than inferred from numerical data.

Throughout August 2024, the sample rate climbed steadily higher. Each increase brought new challenges: signals traveling through circuit traces at these speeds behave less like simple electrical currents and more like radio waves, requiring careful attention to the physical layout of the circuit board. By mid-August, the system was capturing signals at 800 million samples per second. By the end of the month, it reached 1.4 billion samples per second in single-channel mode.

### The Hardware Takes Shape

While the electronic capture system was being refined, the physical design evolved through several iterations. The first complete circuit boards were ordered in mid-August 2024. These early prototypes revealed the inevitable gap between simulation and reality—some things worked better than expected, others required modification.

The oscilloscope's architecture emerged as a modular design with several specialized circuit boards working together. A power supply board converted the incoming electricity to the various voltages required by different components. An input conditioning board prepared incoming signals, allowing the user to select between different sensitivity ranges and coupling modes. A clock generator board produced the precise timing signals needed to coordinate the entire system. And at the heart of the design, a main board combined a high-speed analog-to-digital converter with a programmable logic chip that could be reconfigured to implement different signal processing algorithms.

September 2024 brought continued performance improvements. The sample rate reached 2.9 billion samples per second, then 3.2 billion—fast enough to capture radio signals, examine the fine details of high-speed digital communications, or observe phenomena that occur in mere nanoseconds.

### Integration

By late September 2024, the separate prototype boards were being consolidated into a single, unified design. This integration phase required solving countless small problems: ensuring that heat from one component didn't affect another, routing hundreds of electrical connections without creating interference, and fitting everything into a practical enclosure.

The full board design was completed in early October 2024. This represented a significant milestone—the transition from a collection of development boards into something that could eventually become a product.

October also brought important advances in the instrument's triggering system. An oscilloscope's trigger determines when to begin capturing a waveform, and sophisticated triggering is essential for observing specific events within a continuous stream of signals. The Haasoscope Pro gained the ability to trigger on rising or falling edges, on signals that stayed above a threshold for a specified time, and on various other conditions that help isolate signals of interest from background noise.

### Expanding Capabilities

In late October 2024, a significant architectural expansion enabled multiple Haasoscope Pro units to work together as a synchronized system. By connecting two or more instruments with a cable, users could effectively multiply their channel count while maintaining precise timing alignment between all channels. This capability is essential for applications like debugging complex digital systems where many signals must be observed simultaneously.

The software continued to mature through early 2025. January brought an analysis window for examining the frequency content of signals—a mathematical transformation that reveals which frequencies are present in a waveform. The display gained the ability to show measurements in familiar units like volts per division, matching the conventions of traditional oscilloscopes.

The user interface became increasingly sophisticated. Rolling display modes showed continuously updating waveforms. Automatic triggering ensured the display remained active even when no specific trigger event occurred. Keyboard shortcuts allowed rapid adjustment of common settings.

### Reaching Outward

May 2025 marked the addition of a network interface that allowed other software to control the oscilloscope remotely. This opened the Haasoscope Pro to integration with existing laboratory automation systems and third-party analysis software. An instrument that can be controlled programmatically becomes far more powerful than one requiring manual operation.

The multi-instrument synchronization system was refined throughout this period. Precise measurements of signal propagation delays between connected units allowed the software to compensate for timing differences, ensuring that waveforms from different instruments aligned correctly.

### Refinement

The autumn of 2025 brought a major reorganization of the software. The original code, written rapidly during the prototype phase, was restructured into clearly separated components with well-defined responsibilities. This made the system easier to maintain and extend, enabling faster development of new features.

New capabilities emerged rapidly from this improved foundation. A persistence display mode accumulated multiple waveforms into a single image, revealing signal variations that would be invisible in a single capture. Mathematical operations allowed users to add, subtract, or otherwise combine channels to create derived measurements. Cursor tools enabled precise measurement of time intervals and voltage differences directly on the displayed waveforms.

November 2025 added a specialized trigger mode for detecting "runt" pulses—signals that partially transition between voltage levels but fail to complete the transition. This capability is particularly valuable for identifying marginal signals that might cause intermittent failures in digital systems.

The most recent developments have focused on increasing the data transfer rate between the instrument and the host computer, enabling deeper memory captures and faster screen updates.

### The Instrument Today

The Haasoscope Pro that exists today bears little resemblance to the first prototype from July 2024. What began as a basic data capture system has evolved into a sophisticated measurement instrument capable of capturing signals at 3.2 billion samples per second, triggering on complex signal conditions, synchronizing multiple units for expanded channel counts, and presenting results through a polished graphical interface.

The development history, preserved in over 1,700 individual code commits, tells a story of incremental progress punctuated by occasional breakthroughs. Some commits represent days of work; others capture small fixes made in minutes. Together, they document the gradual accumulation of capability that transforms an idea into a working instrument.

The project demonstrates what has become possible in the modern era of electronic design. High-speed analog-to-digital converters that once cost thousands of dollars are now available for modest sums. Programmable logic devices provide the processing power to handle billions of samples per second. Open-source software tools enable a single developer to create sophisticated graphical interfaces. And online manufacturing services can produce professional-quality circuit boards from design files in days rather than weeks.

The Haasoscope Pro stands as evidence that significant scientific instruments can emerge from individual effort and open development practices. The work continues, with each update adding new capabilities to an instrument that grows more powerful with time.

---

*This account was written by Claude, an AI assistant developed by Anthropic, based on analysis of the project's git repository containing over 1,700 commits spanning July 25, 2024 through November 26, 2025.*

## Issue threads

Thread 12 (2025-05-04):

HaasoscopePro software Consider integrating with ngscopeclient instead of custom Python+Qt UI

bvernoux, 2025-05-04:
## Issue Description

The current HaasoscopePro UI is implemented in Python using Qt, which provides a functional interface for controlling the oscilloscope.
However, I noticed this project might be "reinventing the wheel" by maintaining its own oscilloscope UI when there's a more advanced, comprehensive, open-source solution available: [ngscopeclient](https://github.com/ngscopeclient).

## Benefits of ngscopeclient

- **Comprehensive oscilloscope UI framework**: ngscopeclient is a specialized UI designed specifically for test and measurement equipment with features beyond what's currently implemented
- **Instrument abstraction layer**: libscopehal (part of ngscopeclient) provides a hardware abstraction layer for connecting to various oscilloscopes
- **Advanced protocol decoding**: Built-in support for many protocol decoders (RS232, Ethernet, etc.)
- **GPU-accelerated signal processing**: Uses Vulkan compute shaders for DSP operations
- **Cross-platform support**: Works on Windows, Linux, and macOS, just like the current solution
- **Filter graph system**: Allows for complex signal processing chains with visual configuration
- **Development community**: Active development with contributions from multiple projects

## Implementation Approach

- **Create a HaasoscopePro driver for ngscopeclient/libscopehal**: This would allow HaasoscopePro to be used with the complete ngscopeclient UI, providing a more advanced interface with protocol decoding and advanced analysis features.

## References

- ngscopeclient website: https://www.ngscopeclient.org/
- ngscopeclient GitHub: https://github.com/ngscopeclient

---

This suggestion aligns with the project's open-source philosophy while potentially reducing maintenance burden and providing users with a more feature-rich interface. By leveraging an existing oscilloscope UI framework, the project could focus more on the hardware and firmware aspects of the HaasoscopePro.

drandyhaas, 2025-05-04:
I certainly like the idea of HaasoscopePro being supported (having a driver for) ngscopeclient.
However, the Haasoscope Pro PyQt GUI has a somewhat different aim, and thus will still serve a useful purpose. It has features such as multi-board support and debugging features that are meant to test and debug advanced features of the HaasoscopePro.
@priimak is developing (very advanced already) a python API for the Haasoscope Pro. It will make it much easier to interface the Haasoscope Pro to other softwares or GUIs.
https://github.com/priimak/HaasoscopeProPy
He is also developing (also pretty advanced) a GUI in python Qt6 which relies on his API.
https://github.com/priimak/HaasoscopeProGUI
It is meant to be easy to use and resemble a standard oscilloscope interface. So in that way it also seems to serve a significantly different role than ngscopeclient, and thus should also be developed as well.
In summary, I see all three GUIs continuing to be developed:
 - HaasoscopeProQt for advanced users and developers testing new features (it's basically done anyways)
 - HaasoscopeProGUI for an easy interface resembling a standard scope (and it will also support other hardware as well)
 - ngscopeclient for more advanced users wanting signal processing, decoding, super speed, etc.

priimak, 2025-05-04:
I agree that being able to connect to HaasoscopePro from other clients including ngscopeclient would be a good thing. I would suggest to proceed at this in several steps. Andy already has GUI for Haasoscope Pro written in python, however in it API to the scope is heavily entangled with the graphical UI itself. To that end I have extracted API to the scope into python library ([https://github.com/priimak/HaasoscopeProPy](https://github.com/priimak/HaasoscopeProPy)) and am building new python GUI ([https://github.com/priimak/HaasoscopeProGUI](https://github.com/priimak/HaasoscopeProGUI)). Building this GUI allows me to verify that my python API to the scope is correct and that it provides good ergonomics for developers. Thus when both are complete (and python API that I heave still require some cleanup) I think it would make sense to rewrite that API layer in let say Rust and provide binding to python, C++ or other languages. Once that is done we can create driver from ngscopeclient.

drandyhaas, 2025-05-09:
I'm working on a quick solution. The plan is to open up a TCP socket in python in the HaasoscopePro python GUI. Once the GUI is up and running (which initializes and calibrates the scope), ngscopeclient can connect to its socket. It can then share control of the HaasoscopePro and get back waveforms.
For now, I've made a dummy python socket app, which is standalone - it just answers to the SCPI commands and feeds back dummy data:
https://github.com/drandyhaas/HaasoscopePro/blob/main/software/SCPIsocket.py
My HaasoscopePro scopehal driver is here:
https://github.com/ngscopeclient/scopehal/compare/master...drandyhaas:scopehal:master
Seems to work pretty well. I basically started from the ThunderScope driver and just updated it to 16-bit, since HaasoscopePro is 12-bit.
I'll post again soon once it is actually integrated into the real HaasoscopePro app and thus getting real data.
Is there a better, more real-time, way to communicate with the ngscopeclient team?

Screenshot:

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

drandyhaas, 2025-05-09:
OK, I integrated the python socket server into the HaasoscopePro PyQt GUI. It does some very basic serving of waveforms back to the HaasoscopePro driver in ngscopeclient now. Update rate is a solid ~60 Hz on my circa 2016 Windows machine, at mem depth of 4000 samples and one channel.
Screenshots:

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

drandyhaas, 2025-05-09:
Now works for multiple channels, and seems quite stable. Will make a pull request to include the driver in ngscopeclient. Closing this ticket as collected for now.

Closed 2025-05-09.

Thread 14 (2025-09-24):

29.2 Grid problems on win10 AMD Ryzen 7 5700U with Radeon Graphics

BrewLama, 2025-09-24:
I'm assuming this is some Qt bug but not sure what a fix might be. Switched computers today, was running slightly older scope release on my desktop vs. the 29.2 that's out now.

On my Dell laptop screen the app's display looks fine.  On both of the attached 4K monitors the grids are off as seen in the screen capture, and looks the same regardless of how big I make the window.

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

Worked fine on the 4K monitors on the other system which is also an older win10 one with older AMD graphics.

Not sure what other info would be helpful.  The system is win 10 22H2 with:
AMD Driver Version 23.19.21.01-240819a-417541C-Dell
Direct3D API Version 12.1
Vulkan™ API Version 1.3.260
OpenGL® API Version 4.6

Since it displays fine from the laptop's screen I can use it from there for now.  Thanks for any suggestions.

drandyhaas, 2025-09-24:
I put this in v29.21...
https://github.com/drandyhaas/HaasoscopePro/commit/8fd799a5dd5a2463f3b6c1db125c0b5a01b1ce30
See if that fixes it please.

drandyhaas, 2025-09-25:
Hmm. OK, I moved it earlier. Try 29.22.
Are you running from the HaasoscopeProQt.exe in the dist directory, or from python3 HaasoscopeProQt.py?
Please include a printout from the console window.

BrewLama, 2025-09-25:
I was running it direct from Python vs. the packaged .exe - seemed simpler to do that though I needed to install the pyqt stuff.

29.22 seems to have taken care of the grid problem - behaves as expected now.  Thanks for taking a look at it so quickly.

Unrelated question, there's not a specific user forum for the scope?  I was going share what I've done with it - specifically with the DIP1400 probe - in case someone was looking for info on that.

OTOH I have some questions about triggering that I have not figured out yet and maybe the community already has and/or you would want to chime in?  (though i want to go rewatch the videos in case I missed it).  What's your preference for where to post, etc?

drandyhaas, 2025-09-25:
So glad 29.22 fixed your drawing issue!
I just opened a discussions forum here on github: https://github.com/drandyhaas/HaasoscopePro/discussions
I look forward to seeing what you've been doing with the HSPro + DIP1400 (active probe?)
For a triggering issue that you think may be a bug, post an issue. If it's a more general question or discussion, maybe put in the new forum.
Thanks!

Closed 2025-09-25.

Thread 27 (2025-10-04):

Signal gen voltage drop

Erhannis, 2025-10-04:
When I connect an external oscilloscope to the 1KHz signal output, I see ~2.4V.  When I then also connect a probe from the Haasoscope Pro, the voltage (measured by the external scope) drops to ~300mV, and the Haasoscope itself reports 100mV.  Any idea what's going on?  I'm using a normal scope probe, 100MHz; labeled P6100, apparently 1MOhm.  ...Hang on, I think I'm starting to figure it out.  (Though I'm starting to forget the order in which I did things.)  When I checkboxed 1MOhm, the voltage drop got much smaller.  At some point in the process, the measured voltage seemed to cap out at 1.6V, in a way that seemed to indicate a limitation of the chips involved, but switching to 10x and turning down the gain got the signal gen to appear correctly as 2.4V.  This has sorta just turned into a log of how I got it to work; I figure I'll post it in case others have similar problems, but you can probably just close this issue unless you see something obviously incorrect.

drandyhaas, 2025-10-04:
Right, the 1kHz output on the front is only capable of about 20 mA (driven from an FPGA output). So only use it in 1 MOhm mode.

Closed 2025-10-05.

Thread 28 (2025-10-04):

Bent connector, peeled trace

Erhannis, 2025-10-04:
So my Haasoscope Pro arrived with a bent Trig/Aux Out connector.  Without much thought I bent it back, then thought maybe I shouldn't have, haha.  Indeed, when I opened it up, I saw that (in addition to the loose fan issue I've seen mentioned) the trace had been pulled off the board.

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

Now, on the one hand, I'm not sure when if ever I'll use the Aux Out connector, and it looks like the trace is still connected so it might even still _work_.  Not sure what to do about it in any case.  Thoughts?  I was initially going to replace the connector, but seeing the trace decided maybe I shouldn't touch it.

drandyhaas, 2025-10-04:
Yikes. Yeah, it looks like it would still work. I wouldn't try to replace it, since that might make it worse. You might solder it solid on the BOTTOM of the board, where the connector also has pins and there are ground traces.

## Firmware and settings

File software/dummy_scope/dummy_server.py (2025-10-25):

#!/usr/bin/env python3
"""
Dummy Oscilloscope Server
Simulates a HaasoscopePro board via TCP socket for testing without hardware.
Connect with: HaasoscopeProQt.py --socket localhost:9999
"""

import socket
import struct
import threading
import argparse
import time
import math
import random
from typing import Dict, Tuple

class DummyOscilloscopeServer:
    """Minimal simulated oscilloscope board responding to HaasoscopePro commands."""

    def __init__(self, host: str = "localhost", port: int = 9998, firmware_version: int = 0, noise_enabled: bool = True):
        self.host = host
        self.port = port
        self.firmware_version = firmware_version
        self.noise_enabled = noise_enabled
        self.running = False
        self.server_socket = None
        self.clients: Dict[socket.socket, str] = {}

        # Per-channel waveform configuration
        self.channel_config = {
            0: {
                "wave_type": "sine",  # "sine", "square", "pulse"
                "frequency": 3.2e6,  # Hz (3.2 MHz = 1000 samples per period at 3.2 GS/s)
                "amplitude": 1500,  # ADC counts (for sine/square waves)
                "square_rise_fall_k": 10.0,  # rise/fall sharpness for square wave (1-100)
                "pulse_tau_rise": 10.0,  # samples (rise time constant for pulse)
                "pulse_tau_decay": 50.0,  # samples (decay time constant for pulse)
                "pulse_amplitude_min": 100,  # minimum pulse amplitude (ADC counts)
                "pulse_amplitude_max": 2000,  # maximum pulse amplitude (ADC counts)
            },
            1: {
                "wave_type": "pulse",  # "sine", "square", "pulse"
                "frequency": 100e6,  # Hz (100 MHz)
                "amplitude": 1500,  # ADC counts (for sine/square waves)
                "square_rise_fall_k": 10.0,  # rise/fall sharpness for square wave (1-100)
                "pulse_tau_rise": 8.0,  # samples
                "pulse_tau_decay": 40.0,  # samples
                "pulse_amplitude_min": 10,  # minimum pulse amplitude (ADC counts)
                "pulse_amplitude_max": 500,  # maximum pulse amplitude (ADC counts)
            }
        }

        # Board state simulation
        self.board_state = {
            "trigger_ready": False,
            "fan_on": False,
            "fan_pwm": 128,
            "clk_out_enabled": True,
            "aux_out": 0,
            "board_position": 0,  # 0=middle, 1=first, 2=last
            "has_external_clock": False,  # For LVDS ordering
            "pll_locked": True,  # PLL lock status (bit 5)
            "internal_clock": True,  # True=internal, False=external
            "adc_temp": 25.0,  # Simulated ADC die temperature
            "board_temp": 20.0,  # Simulated board temperature
            "channel_impedance": [False, False],  # False=50Ohm, True=1MOhm
            "channel_coupling": [False, False],  # False=DC, True=AC
            "channel_att": [False, False],  # False=no att, True=att
            "split_enabled": False,  # Clock splitter for oversampling
            "spi_mode": 0,  # Current SPI mode (0 or 1)
            "trigger_counter": 0,  # Incrementing trigger counter
            "data_counter": 0,  # For phase continuity in generated data
            # Trigger settings (from opcode 8)
            "trigger_level": 0,  # Voltage threshold for triggering (0-255, maps to ADC value)
            "trigger_delta": 0,  # Trigger hysteresis
            "trigger_pos": 0,  # Position in waveform where trigger should occur
            "trigger_time_thresh": 0,  # Timing threshold
            "trigger_chan": 0,  # Channel to trigger on
            # Downsample settings (from opcode 9)
            "downsample_ds": 0,  # Downsample factor (power of 2)
            "downsample_highres": 1,  # 1 = averaging mode, 0 = decimation mode
            "downsample_merging": 1,  # Number of samples to merge
            # Trigger type (from opcode 1)
            "trigger_type": 1,  # 1 = rising edge, 2 = falling edge
            # Channel mode (from opcode 1, data[2])
            "two_channel_mode": False,  # False = single channel (3.2 GS/s), True = two channel (1.6 GS/s per channel)
            # Gain and offset (from SPI commands)
            "channel_gain": [0, 0],  # Gain in dB for each channel (0 = 0dB = 1x)
            "channel_offset": [0, 0],  # Offset in ADC counts for each channel
        }

    def start(self):
        """Start the dummy server."""
        self.running = True
        self.server_socket = socket.socket(socket.AF_INET, socket.SOCK_STREAM)
        self.server_socket.setsockopt(socket.SOL_SOCKET, socket.SO_REUSEADDR, 1)

        try:
            print("Opening port",self.port)
            self.server_socket.bind((self.host, self.port))
            self.server_socket.listen(5)
            print(f"[DUMMY SERVER] Listening on {self.host}:{self.port}")
            print(f"[DUMMY SERVER] Firmware version: {self.firmware_version}")
            print(f"[DUMMY SERVER] Noise: {'enabled' if self.noise_enabled else 'DISABLED (deterministic mode)'}")

            while self.running:
                try:
                    self.server_socket.settimeout(1.0)
                    client_socket, client_addr = self.server_socket.accept()
                    client_name = f"{client_addr[0]}:{client_addr[1]}"
                    self.clients[client_socket] = client_name
                    print(f"[DUMMY SERVER] Client connected: {client_name}")

                    client_thread = threading.Thread(
                        target=self._handle_client,
                        args=(client_socket, client_name),
                        daemon=True
                    )
                    client_thread.start()
                except socket.timeout:
                    continue
                except Exception as e:
                    print(f"[DUMMY SERVER] Error accepting connection: {e}")
        except Exception as e:
            print(f"[DUMMY SERVER] Server error: {e}")
        finally:
            self.stop()

    def _handle_client(self, client_socket: socket.socket, client_name: str):
        """Handle a single client connection."""
        try:
            while self.running:
                data = client_socket.recv(8)  # All commands are 8 bytes
                if not data or len(data) < 8:
                    break

                response = self._process_command(data)
                client_socket.sendall(response)

        except Exception as e:
            print(f"[DUMMY SERVER] Client {client_name} error: {e}")
        finally:
            client_socket.close()
            del self.clients[client_socket]
            print(f"[DUMMY SERVER] Client disconnected: {client_name}")

    def _process_command(self, data: bytes) -> bytes:
        """Process an 8-byte command and return response."""
        if len(data) < 8:
            return struct.pack("<I", 0xFFFFFFFF)  # Error response

        opcode = data[0]
        sub_cmd = data[1] if len(data) > 1 else 0

        # Opcode 0: Read data
        if opcode == 0:
            return self._handle_read_data(data)

        # Opcode 1: Trigger check
        elif opcode == 1:
            return self._handle_trigger_check(data)

        # Opcode 2: General commands
        elif opcode == 2:
            return self._handle_opcode2(sub_cmd, data)

        # Opcode 3: SPI transaction
        elif opcode == 3:
            return self._handle_spi_transaction(data)

        # Opcode 4: Set SPI mode
        elif opcode == 4:
            return self._handle_set_spi_mode(data)

        # Opcode 5: PLL reset
        elif opcode == 5:
            return self._handle_pll_reset(data)

        # Opcode 6: Phase adjust
        elif opcode == 6:
            return self._handle_phase_adjust(data)

        # Opcode 7: Clock switch
        elif opcode == 7:
            return self._handle_clock_switch(data)

        # Opcode 8: Trigger info/level
        elif opcode == 8:
            return self._handle_trigger_info(data)

        # Opcode 9: Set downsample/merge
        elif opcode == 9:
            return self._handle_downsample(data)

        # Opcode 10: Set channel parameters
        elif opcode == 10:
            return self._handle_channel_control(data)

        # Opcode 11: Send LED RGB values
        elif opcode == 11:
            return self._handle_led_control(data)

        # Opcode 12: Dummy server configuration (custom opcode)
        elif opcode == 12:
            return self._handle_dummy_config(data)

        # Default: return dummy response (4 bytes)
        return struct.pack("<I", 0x00000000)

    def _handle_opcode2(self, sub_cmd: int, data: bytes) -> bytes:
        """Handle opcode 2 (general board commands)."""

        if sub_cmd == 0:
            # Get firmware version
            return struct.pack("<I", self.firmware_version)

        elif sub_cmd == 1:
            # Read board digital status
            # Bit 5 must be 1 for PLL locked
            status = 0x20 if self.board_state["pll_locked"] else 0x00
            return struct.pack("<I", status)

        elif sub_cmd == 4:
            # Get pre-data (merge counter)
            # Return 1 to keep downsamplemergingcounter stable
            # (real hardware increments this, but for dummy we keep it constant)
            return struct.pack("<I", 1)

        elif sub_cmd == 5:
            # Get LVDS info/status (clockused checks bits)
            # Bit 1: external clock lock status
            # Bit 3: no external clock input (for first board)
            response = 0
            if self.board_state["internal_clock"]:
                response |= (1 << 3)  # Set bit 3 for internal clock (first board)
            else:
                response |= (1 << 1)  # Set bit 1 for external clock locked
            return struct.pack("<I", response)

        elif sub_cmd == 6:
            # Set fan on/off
            self.board_state["fan_on"] = bool(data[2])
            return struct.pack("<I", 0)

        elif sub_cmd == 7:
            # Set trigger pre-length
            return struct.pack("<I", 0)

        elif sub_cmd == 8:
            # Set rolling/external trigger mode
            return struct.pack("<I", 0)

        elif sub_cmd == 9:
            # Enable LVDS clock output
            self.board_state["clk_out_enabled"] = bool(data[2])
            return struct.pack("<I", 0)

        elif sub_cmd == 10:
            # Set aux output selector
            self.board_state["aux_out"] = data[2]
            return struct.pack("<I", 0)

        elif sub_cmd == 14:
            # Set first/last board
            self.board_state["board_position"] = data[2]
            return struct.pack("<I", 0)

        elif sub_cmd == 19:
            # Reload firmware from flash
            return struct.pack("<I", 0)

        elif sub_cmd == 20:
            # Set trigger delay/holdoff
            return struct.pack("<I", 0)

        elif sub_cmd == 21:
            # Set fan PWM duty cycle
            self.board_state["fan_pwm"] = data[2]
            return struct.pack("<I", 0)

        else:
            # Unknown sub-command
            return struct.pack("<I", 0)

    def _handle_trigger_check(self, data: bytes) -> bytes:
        """Handle opcode 1 (trigger status check)."""
        # Parse trigger type from data[1]
        # 1 = rising edge, 2 = falling edge
        trigger_type = data[1]
        self.board_state["trigger_type"] = trigger_type

        # Parse two-channel mode from data[2]
        # data[2] = is_two_channel + 2 * state.dooversample[board_idx]
        # For non-oversampling mode: data[2] = 0 (single channel) or 1 (two channel)
        channel_mode_byte = data[2]
        is_two_channel = (channel_mode_byte % 2) == 1  # Extract the LSB
        self.board_state["two_channel_mode"] = is_two_channel

        # Always simulate trigger ready - continuously return new events
        # Event ready response: byte 0 = 251, byte 1 = trigger position, bytes 2-3 = unused
        # Return trigger position of 0 in byte 1
        # This combined with triggerpos=50 will center the trigger in the display
        trigger_pos = 0
        return bytes([251, trigger_pos, 0, 0])

    def _generate_double_exponential_pulse(self, t: float, t0: float, amplitude: float,
                                          tau_rise: float, tau_decay: float) -> float:
        """
        Generate a double-exponential pulse value at time t.

        Formula: A * (e^{-(t-t₀)/τ_d} - e^{-(t-t₀)/τ_r})

        Args:
            t: Current time (sample index)
            t0: Pulse start time (sample index)
            amplitude: Pulse amplitude
            tau_rise: Rise time constant (samples)
            tau_decay: Decay time constant (samples)

        Returns:
            Pulse value at time t
        """
        if t < t0:
            return 0.0

        dt = t - t0

        # Compute double exponential
        # Use max to avoid division by zero or negative time constants
        tau_r = max(0.1, tau_rise)
        tau_d = max(0.1, tau_decay)

        exp_decay = math.exp(-dt / tau_d)
        exp_rise = math.exp(-dt / tau_r)

        # Normalize so peak amplitude is close to the specified amplitude
        # The peak occurs at t_peak = (tau_r * tau_d) / (tau_d - tau_r) * ln(tau_d / tau_r)
        # At the peak, the normalization factor is needed
        # For simplicity, we'll use an empirical normalization
        if tau_d > tau_r:
            norm_factor = 1.0 / (math.exp(-tau_r / tau_d) - math.exp(-1.0))
        else:
            norm_factor = 1.0

        return amplitude * norm_factor * (exp_decay - exp_rise)

    def _generate_channel_waveform(self, channel: int, num_samples: int,
                                   start_phase: float, downsample_factor: int,
                                   highres: int, sample_rate: float) -> list:
        """
        Generate waveform for a single channel based on its configuration.

        Args:
            channel: Channel number (0 or 1)
            num_samples: Number of samples to generate
            start_phase: Starting phase offset in radians
            downsample_factor: Total downsampling factor
            highres: 1 for averaging mode, 0 for decimation
            sample_rate: Sample rate in GS/s (3.2 for single channel, 1.6 for two channel)

        Returns:
            List of ADC sample values
        """
        config = self.channel_config[channel]
        wave_type = config["wave_type"]
        frequency = config["frequency"]
        amplitude = config["amplitude"]

        # Get gain and offset
        gain = pow(10, self.board_state["channel_gain"][channel] / 20.0)
        offset = self.board_state["channel_offset"][channel]

        # Noise parameters
        if self.noise_enabled:
            noise_rms = 0.01 * amplitude  # 1% RMS noise

            # Reduce noise for high-res mode (simulates averaging without actually averaging)
            if highres == 1 and downsample_factor > 1:
                noise_rms_effective = noise_rms / math.sqrt(downsample_factor)
            else:
                noise_rms_effective = noise_rms
        else:
            # No noise in deterministic mode
            noise_rms = 0.0
            noise_rms_effective = 0.0

        # Calculate period in samples
        sample_rate_hz = sample_rate * 1e9  # Convert GS/s to Hz
        wave_period = sample_rate_hz / frequency

        samples = []

        # For pulse waveforms, generate random pulses
        if wave_type == "pulse":
            # Random pulse amplitude for this event (or fixed in deterministic mode)
            if self.noise_enabled:
                pulse_amp = random.uniform(config["pulse_amplitude_min"], config["pulse_amplitude_max"])
            else:
                # Use average amplitude for deterministic mode
                pulse_amp = (config["pulse_amplitude_min"] + config["pulse_amplitude_max"]) / 2.0

            tau_rise = config["pulse_tau_rise"]
            tau_decay = config["pulse_tau_decay"]

            # Place pulse at a random position in the waveform, but ensure it's visible
            # For triggered events, center it roughly in the middle
            if self.noise_enabled:
                pulse_t0 = num_samples * 0.4 + random.uniform(-num_samples * 0.1, num_samples * 0.1)
            else:
                # Fixed position in deterministic mode
                pulse_t0 = num_samples * 0.4

            for i in range(num_samples):
                if downsample_factor == 1 or highres == 1:
                    # No downsampling or high-res mode: generate single sample
                    base_sample_pos = i if downsample_factor == 1 else i * downsample_factor
                    val = self._generate_double_exponential_pulse(
                        base_sample_pos, pulse_t0, pulse_amp, tau_rise, tau_decay
                    )
                    val = int(val * gain)
                    noise = random.gauss(0, noise_rms_effective)
                    val = int(val + noise + offset)
                else:
                    # Decimation mode
                    base_sample_pos = i * downsample_factor
                    val = self._generate_double_exponential_pulse(
                        base_sample_pos, pulse_t0, pulse_amp, tau_rise, tau_decay
                    )
                    val = int(val * gain)
                    noise = random.gauss(0, noise_rms)
                    val = int(val + noise + offset)

                val = max(-2048, min(2047, val))
                samples.append(val)

        elif wave_type == "square":
            # Get rise/fall parameter k
            k = config["square_rise_fall_k"]

            for i in range(num_samples):
                if downsample_factor == 1 or highres == 1:
                    # No downsampling or high-res mode: generate single sample
                    base_sample_pos = i if downsample_factor == 1 else i * downsample_factor
                    phase = (base_sample_pos * 2 * math.pi / wave_period + start_phase)
                    # Square wave with adjustable rise/fall: A/2 * [1 + tanh(k * sin(phase))]
                    # Convert to bipolar: A * tanh(k * sin(phase))
                    val = int(amplitude * math.tanh(k * math.sin(phase)) * gain)
                    noise = random.gauss(0, noise_rms_effective)
                    val = int(val + noise + offset)
                else:
                    # Decimation mode
                    base_sample_pos = i * downsample_factor
                    phase = (base_sample_pos * 2 * math.pi / wave_period + start_phase)
                    # Square wave with adjustable rise/fall: A * tanh(k * sin(phase))
                    val = int(amplitude * math.tanh(k * math.sin(phase)) * gain)
                    noise = random.gauss(0, noise_rms)
                    val = int(val + noise + offset)

                val = max(-2048, min(2047, val))
                samples.append(val)

        else:  # sine wave (default)
            for i in range(num_samples):
                if downsample_factor == 1 or highres == 1:
                    # No downsampling or high-res mode: generate single sample
                    base_sample_pos = i if downsample_factor == 1 else i * downsample_factor
                    phase = (base_sample_pos * 2 * math.pi / wave_period + start_phase)
                    val = int(amplitude * math.sin(phase) * gain)
                    noise = random.gauss(0, noise_rms_effective)
                    val = int(val + noise + offset)
                else:
                    # Decimation mode
                    base_sample_pos = i * downsample_factor
                    phase = (base_sample_pos * 2 * math.pi / wave_period + start_phase)
                    val = int(amplitude * math.sin(phase) * gain)
                    noise = random.gauss(0, noise_rms)
                    val = int(val + noise + offset)

                val = max(-2048, min(2047, val))
                samples.append(val)

        return samples

    def _generate_wave_buffer(self, num_samples: int, start_phase: float = 0.0) -> Dict[str, list]:
        """
        Generate raw waveform data for both channels.

        Args:
            num_samples: Number of ADC samples to generate
            start_phase: Starting phase offset in radians

        Returns:
            Dictionary with 'ch0' and 'ch1' keys containing lists of ADC sample values
        """
        two_channel_mode = self.board_state["two_channel_mode"]

        # Get downsample parameters
        ds = self.board_state["downsample_ds"]
        merging = self.board_state["downsample_merging"]
        highres = self.board_state["downsample_highres"]
        downsample_factor = merging * (2 ** ds)

        ch0_samples = []
        ch1_samples = []

        if two_channel_mode:
            # Generate samples for both channels at 3.2 GS/s base rate
            # Extraction will take every other sample to get 1.6 GS/s per channel
            ch1_samples = self._generate_channel_waveform(
                channel=1,
                num_samples=num_samples,
                start_phase=start_phase,
                downsample_factor=downsample_factor,
                highres=highres,
                sample_rate=3.2  # Generate at full rate, extraction decimates to 1.6 GS/s
            )
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

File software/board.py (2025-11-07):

"""
Provides high-level functions for configuring the Haasoscope Pro hardware,
including the ADC, PLL synthesizer, amplifiers, and other peripherals.

This module acts as the primary hardware abstraction layer, using lower-level
modules like `spi.py` to execute commands.
"""

import time
import math
from typing import Union
from numpy import byte

# Import dependencies
from spi import spicommand, spicommand2, set_spi_mode
from utils import reverse_bits, inttobytes, getbit, binprint
from adf435x_core import calculate_regs, make_regs, DeviceType, FeedbackSelect, BandSelectClockMode, PDPolarity, ClkDivMode, MuxOut, LDPinMode

def auxoutselector(usb, val: int, doprint: bool = False):
    """Selects the signal to route to the auxiliary SMA output."""
    usb.send(bytes([2, 10, val, 0, 99, 99, 99, 99]))
    res = usb.recv(4)
    if doprint:
        print(f"auxoutselector now {val}, was {res[0]}")

def clkout_ena(usb, board, en: bool, doprint: bool = True):
    """Enables or disables the LVDS clock output for daisy-chaining boards."""
    usb.send(bytes([2, 9, int(en), 0, 99, 99, 99, 99]))
    res = usb.recv(4)
    if doprint:
        print(f"Clock out on board {board} now {bool(en)}, was {bool(res[0])}")

def flash_erase(usb, doprint: bool = False):
    """Sends the command to bulk erase the configuration flash."""
    usb.send(bytes([17, 0, 0, 0, 99, 100, 101, 102]))
    res = usb.recv(4)
    if doprint:
        print(f"bulk erase got {res[0]}")

def flash_busy(usb, doprint: bool = False) -> int:
    """Checks the busy status of the configuration flash."""
    usb.send(bytes([14, 13, 0, 0, 99, 99, 99, 99]))
    res = usb.recv(4)
    if doprint:
        print(f"flash busy got {res[0]}")
    return res[0]

def reload_firmware(usb):
    """Commands the FPGA to reload its configuration from the flash memory."""
    print("New firmware is being loaded into the FPGA")
    usb.send(bytes([2, 19, 1, 0, 100, 100, 100, 100]))
    usb.recv(4)


def flash_write(usb, byte3: int, byte2: int, byte1: int, value_to_write: int, do_receive: bool = True):
    """
    Writes a single byte to a specific 24-bit address in the flash memory.

    Args:
        usb: The USB device handle.
        byte3 (int): The most significant byte of the address.
        byte2 (int): The middle byte of the address.
        byte1 (int): The least significant byte of the address.
        value_to_write (int): The 8-bit value to write.
        do_receive (bool): If True, waits for a response from the device.
    """
    # The hardware requires the data byte's bits to be reversed.
    reversed_value = reverse_bits(value_to_write)
    usb.send(bytes([16, byte3, byte2, byte1, reversed_value, 100, 101, 102]))
    if do_receive:
        res = usb.recv(4)
        print(f"Flash write response: {res[0]}")


def flash_writeall_from_file(usb, filename: str, do_write: bool = True, progress_callback=None) -> bytes:
    """
    Reads a binary file and writes its entire contents to the flash memory.

    Args:
        usb: The USB device handle.
        filename (str): The path to the binary file (e.g., firmware.rpd).
        do_write (bool): If False, reads the file but does not write to the device.
        progress_callback: Optional callback function(current, total) to report progress.

    Returns:
        The byte contents of the file that was read.
    """
    with open(filename, 'rb') as f:
        all_bytes = f.read()
        print(f"Opened {filename} with length {len(all_bytes)} bytes.")
        if do_write:
            for i, byte_val in enumerate(all_bytes):
                addr2 = i // (256 * 256)
                addr1 = (i // 256) % 256
                addr0 = i % 256
                # Write the byte but don't wait for an individual response to maximize speed.
                flash_write(usb, addr2, addr1, addr0, byte_val, do_receive=False)

                # The USB buffer is read in chunks to prevent overflow.
                if (i + 1) % 1024 == 0:
                    usb.recv(4 * 1024)
                    if (i + 1) % (1024 * 50) == 0:
                        print(f"Wrote byte {i + 1} / {len(all_bytes)}")
                        if progress_callback:
                            progress_callback(i + 1, len(all_bytes))

            # Receive the final remaining responses.
            remaining_bytes = len(all_bytes) % 1024
            if remaining_bytes > 0:
                usb.recv(4 * remaining_bytes)
            print(f"Finished writing {len(all_bytes)} bytes.")
            if progress_callback:
                progress_callback(len(all_bytes), len(all_bytes))
    return all_bytes
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

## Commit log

2025-04-12 Add direct processing of data using arrays, can click the "Persist (Direct)" button on the GUI (temporarily being used for this purpose), which sets dodirect=True Getting about 75 Hz on my Windows de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
2025-04-14 Check for clk and str problems in firmware, so we don't have to decode in software continuously
    [command_processor.v]
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2025-04-15 Fix minor issue with fast drawing at start of trace
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2025-04-16 reverse LED bits
2025-04-16 LED colors after reversing bits
    [board.py]
2025-04-17 account for different offset gain in AC coupling mode
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2025-04-23 handle multi-board for phase adjust and firmware update
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2025-04-23 put back triggerlive, needed for multi-board sync make sure dorolling doesn't count while trigger isn't live
    [command_processor.v]
2025-04-24 deal with triggerphase for fast edges with sampletrigged<10
2025-04-24 Turn off lvdsout_clk's for all boards during firmware upload Add flashbusy function to check when flash erase is done
2025-04-25 Set antialias filters on/off for two/single channel mode
2025-04-25 auxout can switch from 1kHz to trigger out set phaseoffset to 0 by default
2025-04-26 Make sure sample_triggered has a 0 in the first 10 bits
2025-04-26 Simplify code for edge trigger a little more (and also fix a minor bug in sample_triggered for two-channel mode)
    [command_processor.v]
2025-04-26 Redo autocalibration with new board+1 c0 c1 c2 phase if too large a TAD is required
2025-04-26 Fix bugs in clk error counting Count 1's to clean up code a bit
    [command_processor.v]
2025-04-26 Fix yet another bug in clk error calculation Condense the clkstr error code a little more
    [command_processor.v]
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2025-04-27 Connect auxout and exttrigin Beautify schematic a bit
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2025-04-28 triggerlive is checked during state 0 instead of 249 force-arm-trigger waits a few cycles before going back to INIT, to give time for didreadout to allow trigger back into state 0 before triggerlive 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
2025-04-29 KiCad 9
    [ADC.kicad_sch, Clock.kicad_sch, Data_output.kicad_sch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]
2025-04-29 remove reset, seems to fix acqstate reading
    [command_processor.v]
2025-04-30 take extra samples after trigger, needed for ext SMA trigger, but might help other things too
2025-05-01 Get data from boards in a proper order, where triggers are set live on ext trig boards first, then triggers set live on boards which can create triggers, for multi-board sync Be careful to get trigge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
2025-05-02 For multi-board, send echo back on lvds_trig_b after lvds_trig measure time for echo, correct toff accordingly
    [command_processor.v]
2025-05-02 For multi-board echos, only do echos during pll reset for a board instead of a huge toff correction, adjust the trigger position for a board with a measured echo
2025-05-03 More auxout options, now a combo box Max multi-board ext trig echo delay 127, for timing closure
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2025-05-04 For multi-board, sendtriggerinfo when changing exttrig, to adjust trigger for time delays
2025-05-04 For multi-board, adjust toff from 31 to 40
2025-05-04 For multi-board, turn off echo calc if we get the same value twice, unless we're in pllreset phase calc
2025-05-06 Menu items for force split and force switch clocks
2025-05-06 For multi-board, test echos using both rising and falling clock edges and demand they match, otherwise step phase of echo clock
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2025-05-07 For multi-board, correct trigger pos and toff when downsampling
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2025-05-10 SCPISocket, listen on all interfaces, and split incoming data in separate commands in case multiple come in during one read
2025-05-14 IC7 rotation
    [haasoscope_pro_adc_fpga_board.brd]
2025-05-16 close socket on USB error so app closes
2025-05-20 For multi-board: adjust trigger a little earlier, to collect data before time of interest, so we can then shift later with toff etc. and not have wrong samples at the start
2025-05-27 bom production v1
    [BOM.xlsx, bom.xlsx, jlcpcb_parts_output.csv]
2025-06-03 Beautify bom
    [bom.csv, bom.xlsx]
2025-08-07 update Linux dist
    [turbo.csv]
2025-08-14 allow for firstlast command to turn off ext trigger forward or backwards if we're the first or last board, respecitively
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2025-08-15 linux build
    [Stocks.csv, data_x_x2_x3.csv, msft.csv]
2025-08-15 windows build
    [Stocks.csv, data_x_x2_x3.csv, msft.csv]
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2025-08-15 Mac build
    [Stocks.csv, data_x_x2_x3.csv, msft.csv]
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2025-08-16 Disable some GUI controls by default Remove a couple printouts Cleanup GUI a little
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2025-08-17 No linux build
    [CET-C1.csv, CET-C1s.csv, CET-C2.csv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]
2025-09-04 v28 fix the trigger pos and phase calculation, and do all in firmware
    [command_processor.v]
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2025-09-11 29.05 add a frame around the channel color box if triggering on that channel
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2025-09-15 account for downsamplefactor in trig stabilizer wider trig stabilizer search range, and find closest crossing to trigger point send trigger phase to hspro socket better drawing and sending interlock 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
2025-09-18 trigger falling/rising per board line width box alpha for persist starts at 100/255 instead of 1 show samplerate in statusbar add more tooltips 29.17 winbuild
2025-09-20 correct statusbar sample rate for twochannels and interleaving
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2025-09-24 set voltage scale right for 50 Ohm (/2) run extra trigger stabilizer in more cases, not just for resampling
2025-09-24 can change channel color right number of decimal places for softwareversion don't print python error when no boards found
2025-09-25 Check for good power by drawing more power and checking ADC "temp" Check for good read of SPI info from ADC and Amps, to check power good Pause running and disable run button instead of exiting
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2025-09-28 skip next event after two channel switch
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2025-09-30 mean rms correct, temps at 1 Hz max, table rows stale removed
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2025-10-02 use fitwidth for mean rms calibration do mean rms calibration event every event during oversample calibration auto calibrate and interleave option in menu ignore early events, and do pre-calibration
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2025-10-04 disable firmware methods after PLL calibration failure
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2025-10-08 testing out trigger delay, got rid of jitter
2025-10-08 remove dist directory, will use github releases instead
    [CET-C1.csv, CET-C1s.csv, CET-C2.csv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]
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2025-10-08 minor fix for v30 firmware - reset downsamplemergingcounter_triggered during holdoff - may have given minor jitter?
2025-10-08 minor fix for v30 firmware - reset sample_triggered registers to remove jitter
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2025-10-11 drawing after calibration fails
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2025-10-12 Revert "FFT's use ThreadPoolExecutor"
    This reverts commit d6aeea5a6c67bca9906d48f5cd8c96d1c8383afe.
2025-10-12 Revert "FFT's use ThreadPoolExecutor"
    This reverts commit 97b736148e0e6d83b1e321e54fbb89be78181225.
2025-10-12 Better error handling when usb com fails due to power drop
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2025-10-12 More board setup error handling
2025-10-12 More board setup error handling, closing thread
2025-10-13 oldbytes, skip bad boards
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2025-10-15 Don't turn on ext clock out on the last board, because who would it be talking to?
2025-10-15 Setup of internal / external clocks at startup, and switching better supported
2025-10-16 reset persistence when doing/stoping oversampling, set autocalibration state based on board
2025-10-16 fix for no boards
2025-10-16 dummy server sends data (no pll reset)
    [dummy_server.py]
2025-10-16 increase dummy wave amplitude, add noise and trigger jitter
    [dummy_server.py]
2025-10-17 dummy scope trigger jitter fixed
    [dummy_server.py]
2025-10-17 dummy scope random phase right for 2 channel, half the noise, falling trigger in 2 channel
    [dummy_server.py]
2025-10-17 dummy server refactored to separate wave generation, triggering, sending - triggering broken
    [dummy_server.py]
2025-10-17 dummy server refactored to separate wave generation, triggering, sending - triggering fixed almost
    [dummy_server.py]
2025-10-17 dummy server refactored to separate wave generation, triggering, sending - triggering fixed
    [dummy_server.py]
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2025-10-18 dummy server: reduce noise by sqrt(downsample), instead of actually downsampling
    [dummy_server.py]
2025-10-21 peak lines width and x-axis stability
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2025-10-22 reference line colors track channel's, two-channel mode resamp fix
2025-10-22 Set board + 1 to ext trig mode when doing oversampling, in case it wasn't already
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2025-10-23 Add zoom window - fix a couple errors
2025-10-23 Add zoom window - stay visible when switching units, two-channel mode, remove autoscale button
2025-10-25 tests: turn off noise in dummy server
    [dummy_server.py]
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2025-10-26 persist heatmap: reset on gain or offset change, only add persist data in zoomed view range
2025-10-26 persist heatmap: fix spotty bins, just need to use more upsampling
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2025-10-27 persist uses just 16 lines still for lines and averaging, but heatmap uses up to 100
2025-10-31 fix oscillation in meanrms calibration for very high frequency inputs (2700+ MHz)
2025-11-01 FIR: measure mean and duty cycle and frequency of "square" wave and then compare to ideal square wave with same parameters, for both even and odd harmonics with power X amount x nearby noise floor, l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
2025-11-01 FIR: disable (and uncheck) menu item if corrections not loaded/taken yet, add support for two-channel mode, 32/64/128 taps for different sample rates,
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2025-11-03 update FIR corrections to account for anti-alias filters
2025-11-03 fix time delay in polyphase resample filtering
2025-11-07 actionPolynominal filtering settings bug on load
2025-11-07 enable clkout on all boards at first, since we don't know which is first
2025-11-07 Got to connect to all boards, and then choose the first max_devices boards after ordering them
2025-11-08 add dummy scopes at the end of the usb list, even if max-devices is e.g. 2 and there are 4 real scopes
2025-11-08 tell first and last even for 1 board, and disable output clock for even one board extra little sleep before trying to erase flash
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2025-11-09 send_trigger_info to all boards that need it for lvds correction
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2025-11-09 Use "r" and "f" keyboard shortcuts to set the current board to rising or falling trigger, respectively. Use space key to toggle run/pause (instead of "r"). Use 0 1 2 3 4 etc keys to select board.
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2025-11-09 process boards in the right order, so correct distcorr from non-ext board is applied to all boards
2025-11-09 after pll reset, check actual state of clock, then switch if needed
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2025-11-26 don't fail board setup for usb3, for now
2026-09-05 Fix recorded timestamps in two-channel mode (discussion #96)
    The CSV recorder copied the raw xydata time column, which always uses the
    single-channel 3.2 GS/s spacing. In two-channel mode each channel is
    sampled at 1.6 GS/s, so the recorded timestamps were 2x too dense - the
    plot manager already doubles the raw x for display, but the recorder did
    not, giving a factor-of-two timing error in the saved files.
    Apply the same 2x scaling when writing, and resolve two-channel mode per
    board for each channel (it is a per-board setting) instead of using
    board 0's mode for every channel, which truncated or wrote stale samples
    for boards in a different mode. Single-channel output is unchanged.
    Co-Aut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
2026-09-05 test_scpi_client: print ps/sample correctly (fs / 1e3, not 1e6)
    Claude-Session: https://claude.ai/code/session_013D7FvLEMWNRBBy4T6YdvfH
